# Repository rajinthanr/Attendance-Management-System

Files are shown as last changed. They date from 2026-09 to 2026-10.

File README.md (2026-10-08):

# Card Attendance System

A battery-powered NFC attendance logger. A student taps an ID card and the unit
confirms the tap with an LED and a vibration pulse, and stores the card number
with a timestamp in on-chip flash. Plugged into a PC over USB-C, it appears as a
USB drive, with no driver needed:

- `ATTEND.CSV`: every tap, read-only.
- `STATUS.TXT`: a short summary of the device.
- `SETTINGS.CSV`: edited by the PC to set the clock, start a lecture, and send
  the list of registered card numbers.

A desktop companion app for the PC keeps the student names and works out who
attended which lecture.

The repository holds the hardware (KiCad 10), the firmware (STM32CubeIDE /
Makefile) and the companion app (Python).

## Project status (2026-10-06)

| Area | State |
|---|---|
| Schematic and PCB | Complete and sent to JLCPCB. DRC still reports two missing connections on the antenna loop (AE1). |
| Firmware | Runs on the board in polling mode. Card reading, LEDs, vibration and the USB drive work. Battery measurement reads full scale on the bench (see [Known issues](#known-issues)). 829 host checks pass. |
| Companion app | Desktop app (Tkinter); the earlier browser version is still included. 123 tests pass, including cross-checks against the firmware's own parser. |

## How it works

1. **Card tap.** The ST25R3916 reader polls for ISO14443-A cards (MIFARE
   Classic, NTAG and similar) every 100 ms. The card number is its UID: 4-byte
   UIDs as they are, longer ones by their last four bytes.
2. **Check.** A card read again within 10 s, or already recorded in the current
   lecture, is a duplicate and is not recorded again. Every other card is
   recorded. The device's card list only decides the colour: green for a
   registered card, red for one it doesn't know.
3. **Feedback.**

   | Result | Feedback |
   |---|---|
   | Registered card | green LED and one short buzz |
   | Unregistered card (still recorded) | red LED and one long buzz |
   | Duplicate | two short buzzes |
   | Log full, or reader fault | red blinks with buzzes |
   | Settings applied / refused (eject, button tap or unplug) | green and two buzzes / red and three buzzes |

4. **Logging.** Taps go to a RAM buffer, then to flash within 5 seconds. The log
   holds 6,858 records and survives a power cut. When it is full, new taps are
   refused rather than overwriting old ones.
5. **Lectures.** Starting a lecture (module and lecture name) writes a marker
   into the log, so taps are grouped by lecture even without the app. A card
   counts once per lecture. The app imports every tap before a lecture starts
   and has the device delete its copy (`#CLEARLOG`).
6. **USB.** Plug in USB-C. The reader stops and the drive appears. Ejecting
   the drive or tapping the button applies `SETTINGS.CSV` and starts the reader
   with the cable still in (unplugging does the same). A USB charger that is not
   a computer is recognised after 5 s, and scanning carries on while it charges.
7. **Power.** Press the power button to switch on. A tap shows the battery
   level; holding it for 2 s switches the device off. On battery it also switches
   itself off after 3 minutes without a tap, or when the battery is flat.

`Firmware/docs/USER_GUIDE.md` explains the device for the people who run a
class with it.

## Hardware

| Function | Part | Notes |
|---|---|---|
| MCU | STM32L432**KB** (Cortex-M4F, 128 kB flash, 64 kB RAM, QFN-32) | Runs at 4 MHz from MSI, and 24 MHz during USB sessions, with a 32.768 kHz LSE crystal. The 128 kB of flash holds both the firmware (72 kB) and the attendance log (56 kB). |
| NFC reader | ST25R3916 (13.56 MHz, QFN-32) on SPI1 | Differential antenna drive with an EMC filter, a matching network and a capacitive RX divider; 27.12 MHz crystal. |
| Antenna | PCB loop, `NFC_Loop_40x30_3T` (40 × 30 mm, 3 turns) | In the keep-out area at the top of the board. |
| Backup reader | 8-pin header for a PN532 breakout (Elechouse V3 SPI pinout) | Shares SPI1, with its own chip-select (PA15) and IRQ (PB6). Not used by the firmware yet. |
| Charger | MCP73833 Li-ion linear charger | 10 kΩ NTC and three charge-status LEDs. |
| 3.3 V rail | TPS7A0233 LDO, 200 mA | Runs from the cell. The reader's VDD/VDD_TX come straight from the battery, and its VDD_IO from 3.3 V. |
| USB | USB-C receptacle (GCT USB4110), USB 2.0 full speed | Sink-only with 5.1 kΩ CC resistors; USBLC6-2SC6 ESD protection. |
| Battery | Single-cell Li-ion, 3.7 V, 2-pin JST-XA | Sensed through a 4.7 MΩ / 2.7 MΩ divider with 100 nF, on the ADC (PA7) and the PVD input (PB7). |
| Feedback | Red and green LEDs, vibration motor | The motor is switched by an AO3400A MOSFET with an SS14 flyback diode. |
| Buttons | Power (PA0 / WKUP1), reset, BOOT0 | |
| Debug | 4-pin SWD header: 3V3, SWDIO, SWCLK, GND | |

### MCU pin map

| Pin | Signal | Pin | Signal |
|---|---|---|---|
| PA0 | Power button (WKUP1, polled) | PB0 | ST25R3916 chip-select |
| PA2 / PA3 | Green / red LED | PB1 | ST25R3916 IRQ (polled) |
| PA4 | Vibration motor enable | PB3 / PB4 / PB5 | SPI1 SCK / MISO / MOSI |
| PA7 | Battery sense (ADC1_IN12) | PB6 | PN532 IRQ |
| PA9 | VBUS detect (polled) | PB7 | Battery sense (external PVD input) |
| PA11 / PA12 | USB D- / D+ | PA15 | PN532 chip-select |
| PA13 / PA14 | SWDIO / SWCLK | PC14 / PC15 | 32.768 kHz crystal |

`Firmware/Bsp/Inc/bsp_board.h` is the firmware's reference for the pin map, and
`Firmware/Card Attendance System.ioc` for the CubeMX configuration.

### PCB

- **Board:** 60 × 88.6 mm, 2 layers, 1.6 mm FR-4, all parts on the top side.
- **Floorplan:** the NFC antenna fills the top of the board. Below it are the
  PN532 header, the MCU and the ST25R3916 front end. The power section (USB-C,
  ESD, charger, LDO, battery connector) runs along the bottom edge.
- **Schematic sheets:**
  - `power.kicad_sch`: USB-C, ESD, charger, LDO and battery.
  - `mcu.kicad_sch`: STM32, buttons, LEDs, motor driver, SWD and the PN532
    header.
  - `rfid.kicad_sch`: ST25R3916, crystal, EMC filter, matching network and
    antenna.
- **Rules:** manufacturing rules are in `PCB/Attendance Management System.kicad_dru`.
  The production files sent to JLCPCB are in `PCB/production/`.

## Firmware

The firmware is split along one rule: **the application logic (`App/`) decides,
the drivers (`Bsp/`) act.**

- **`App/`:** the state machine, ISO14443-A protocol, card presence tracking,
  button debouncing, flash log, card list and device config, lecture sessions,
  the `SETTINGS.CSV` parser, the FAT12 volume, CSV and status files, and battery
  maths. It includes no HAL or register headers and compiles on a PC.
- **`Bsp/`:** implements the hardware contract in `App/Inc/platform_if.h`,
  handing up only raw values. It includes the register-level ST25R3916 driver
  (`bsp_nfc.c`).
- **`Tests/`:** builds all of `App/` against a RAM-backed stub platform with a
  simulated card and a simulated PC editing the drive, so the logic is tested
  without hardware.

The firmware currently **polls**: the main loop runs once a millisecond, and only
SysTick and USB use interrupts. `Firmware/docs/ARCHITECTURE.md` describes the
whole design: polling and the plan for interrupts, the flash layout, record, CSV
and settings formats, sessions, the USB volume, and known limitations.

For debugging, `dbg_*` globals defined in `Core/Src/main.c` show the battery
voltage, the last card, button presses, reader status and record counts in
STM32CubeIDE's Live Expressions view.

### Build and test

Run these from `Firmware/`:

```sh
make test    # host tests for the application logic; needs only a native C compiler
make         # cross-compiles build/card-attendance.{elf,hex,bin}
make clean
```

- **Toolchain:** `make` uses the GCC bundled with STM32CubeIDE
  (`/opt/st/stm32cubeide_*`) when one is installed, and otherwise
  `arm-none-eabi-gcc` on `PATH`.
- **Flashing and debugging:** use STM32CubeIDE over the SWD header.
- **Optional:** `Tests/fs_check.sh` checks the USB volume with real FAT tools
  (needs `mtools` and `dosfstools`).

### Data on the device

- **Flash layout:** the firmware takes the first 72 kB of the 128 kB flash; the
  last 56 kB (from `0x08012000`) is reserved for data by the linker script.
  - Its first page: configuration (device ID).
  - The other 27 pages: the attendance log, 6,858 records.
- **Records:** each record is 8 bytes (card number and seconds since
  2000-01-01), exactly one flash double-word. Lecture markers are records with
  reserved IDs from `0xFFFFFF00` up.
- **Setting up a device:** nothing is needed for it to log. The clock starts from
  the firmware's build time until it is set with `#TIME` in `SETTINGS.CSV` (the
  companion app does this when you start a lecture). The card list and device ID
  also come from `SETTINGS.CSV`.

## Companion app

`Companion/` is a desktop app for the PC the device is plugged into. It needs
only Python 3.8 or newer, with no install and no internet, and runs entirely on
that computer. It finds the device, reads its taps into a local SQLite database,
keeps student names, modules and lectures, starts lectures, sends the card list,
and produces attendance reports as CSV or PDF. Start it with `start.bat` on
Windows or `sh start.sh` on macOS and Linux. `Companion/README.md` explains it
in full.

## Repository layout

```
Firmware/            STM32CubeIDE project + standalone Makefile
  App/               application logic (portable, host-tested)
  Bsp/               board support: HAL drivers, ST25R3916 driver, USB MSC glue
  Core/              CubeMX-generated startup code (edit only inside USER CODE blocks)
  Drivers/           ST HAL and CMSIS
  Middlewares/       ST USB Device Library (core + MSC)
  Tests/             host test harness and tools
  docs/              ARCHITECTURE.md (design), USER_GUIDE.md (for users)
  Card Attendance System.ioc   CubeMX pin and peripheral configuration
Companion/           PC app (Python): desktop GUI, database, reports, tests
PCB/                 KiCad 10 project, BOMs (bom/) and JLCPCB production files (production/)
Enclosure/           3D-printable enclosure (enclosure.py and STL files)
CLAUDE.md            detailed engineering notes (design decisions, open issues)
LICENSE              MIT
```

## Tools

- **PCB:** KiCad 10.0.
- **Firmware:** STM32CubeIDE 1.19 (CubeMX 6.15, STM32Cube FW_L4 V1.18.2), or
  `arm-none-eabi-gcc` with `make`.
- **Host tests:** any C11 compiler (`cc`).
- **Companion app:** Python 3.8+ with Tkinter (included with the standard Python
  installers).

## Known issues

- **Battery reading at full scale.** On the bench the battery-sense pin reads
  full scale (`dbg_battery_error` = 4). The schematic, the layout and the BOM
  values are correct, and the firmware path has been checked. The next step is
  to measure the voltage across the 2.7 MΩ resistor on the running board. Until
  this is fixed, low-battery shutdown cannot work.
- **Firmware limitations.** `Firmware/docs/ARCHITECTURE.md` lists them under
  "Known limitations". The most important:
  - Start each lecture from the PC. Without a new lecture, a card already
    recorded in the last 6 hours counts as a duplicate.
- **Antenna tuning.** Tune the matching network and the RX capacitive divider
  against the real coil (ST AN5276). The reader measured a weak RX signal at
  first; the target amplitude reading is about 190.
- **Charge current.** The PROG resistor is 1 kΩ, which sets 1 A. That's more than
  the 500 mA a USB-C sink with plain 5.1 kΩ CC resistors may draw, and more than
  the MSOP-10 charger can dissipate. Use at least 2 kΩ.
- **External footprint library.** Some footprints come from a SnapEDA library at
  an absolute path outside the repository, so a fresh clone can't resolve them
  until the library is added or the paths are updated.
- **PN532 placement.** A PN532 module plugged into its header sits close to the
  ST25R3916 antenna and may detune it.

## License

MIT. See [LICENSE](LICENSE).

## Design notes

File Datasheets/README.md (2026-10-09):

# Datasheets

Reference documents for the parts on the board. Designators follow the current
schematic (`kicad-cli sch export bom`).

| File | Part | Used for |
|---|---|---|
| `STM32L432KB_DS11451_Rev4.pdf` | STM32L432KB (U4), MCU | Stop 2 / Standby wake-up times, run currents, clocks |
| `ST25R3916_DS12484_Rev8.pdf` | ST25R3916 (U5), NFC reader | Wake-up mode, timers, supply currents, SPI |
| `AN4555_STM32L4_hardware_development.pdf` | STM32L4 application note | Power supply, reset, clocks, boot, SWD |
| `FC-135_32.768kHz_crystal_Y1_Q13FC13500049.pdf` | Epson FC-135 (Y1), LSE crystal | CL 6 pF, ±20 ppm, R1 ≤ 70 kΩ, C0 1.2 pF |
| `X32252712MMB4SI_27.12MHz_crystal_Y2.pdf` | YXC 27.12 MHz (Y2), reader crystal | CL 10 pF |
| `MCP73833_charger_DS20002005.pdf` | MCP73833 (U2), Li-ion charger | PROG resistor, status pins |
| `TPS7A02_LDO.pdf` | TPS7A0233 (U3), 3.3 V LDO | Quiescent current, dropout |
| `USBLC6-2SC6_ESD.pdf` | USBLC6-2SC6 (U1), USB ESD | Layout next to J1 |
| `AO3400A_motor_MOSFET.pdf` | AO3400A (Q1), motor switch | Gate threshold at 3.3 V |
| `SS14_flyback_diode.pdf` | SS14 (D4), motor flyback | |

Not included: st.com refuses scripted downloads. Get these from a browser:

- RM0394, STM32L41x-46x reference manual (Stop 2, LPTIM, RCC, PWR):
  https://www.st.com/resource/en/reference_manual/rm0394-stm32l41xxx42xxx43xxx44xxx45xxx46xxx-advanced-armbased-32bit-mcus-stmicroelectronics.pdf
- AN2867, oscillator design guide (LSE drive level):
  https://www.st.com/resource/en/application_note/an2867-guidelines-for-oscillator-design-on-stm8afals-and-stm32-mcusmpus-stmicroelectronics.pdf
- AN5276, antenna matching for ST25 NFC readers:
  https://www.st.com/resource/en/application_note/an5276-antenna-matching-for-st25-nfc-readers-stmicroelectronics.pdf

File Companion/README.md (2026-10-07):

# Attendance Logger: companion app

A small app for the computer that the attendance device is plugged into. The
device records only a card number and a time for each tap; it keeps no list of
registered cards and records every card it reads. This app keeps everything
else: who each card belongs to (so it alone decides which cards are
registered), their department and modules, and the lectures that were held. It reads the taps off the device, matches them to
lectures, and makes attendance reports. You never have to open a CSV by hand,
though you can.

It needs **Python 3.8 or newer**. It opens its own window on your computer;
nothing is served on the network.

The window is built with **Qt** (PySide6), which needs a one-time install, from
this folder:

```sh
python -m venv .venv
.venv/bin/pip install -r requirements.txt          # Windows: .venv\Scripts\pip install -r requirements.txt
```

`start.sh` / `start.bat` use that `.venv` by themselves. Without PySide6 the app
does not start; it says how to install it.

## Start it

| System | How |
|---|---|
| Windows | double-click `start.bat` |
| macOS, Linux | `sh start.sh` |
| anywhere | `python attendance_qt.py` (with the `.venv` Python, or one that has PySide6); `python attendance_app.py` opens the window too |

The **Attendance Logger** window opens: an indigo header with the device status
on the right, then a row of device buttons: **Connect** (indigo, Ctrl+K),
**Read device** (blue, also F5), **Eject** (orange, Ctrl+E), **Set device time**
(teal) and **Clear device records** (red). Under them, banners appear when
something needs doing (with an **Eject now** button where that is the fix). The
two pages, **Lectures** and **Students**, are picked from the bar on the left.
The menus (File, Device, View, Help) hold the same actions with their
shortcuts, and the status bar at the bottom reports what just happened.

Plug the device into the USB-C port: it appears as a drive called
**ATTENDANCE**, and the status at the top turns green and says *Device
connected*. That can take a few seconds. While the drive is gone the status
says *Device not connected*, and **Eject** and the other device buttons are
greyed out. Next to the status the device's **battery** is drawn as a phone
shows it: a battery filled from the left by its charge, green from 50 %, orange
from 20 %, red below, with the percentage beside it. Hover over it for the cell
voltage. While the device is plugged in its cell is charging, so the figure
reads a little high. Older firmware does not report the battery, nor does a
device that has not measured it yet, and then no battery is shown. The window
keeps working while it looks for the device. To stop, close the window
(File, Quit). On Windows a small black window opens behind it; leave that
open, since closing it closes the app.

`python attendance_qt.py --demo` shows the whole app with made-up data and no
device, which is a good way to learn it. Nothing in demo mode touches a real
drive or your database, and the made-up data is deleted when you quit. Other
options: `--device-dir` (use a folder as the device) and `--data-dir` (keep the
database elsewhere).

The window works from the keyboard too. Ctrl+1 and Ctrl+2 pick a page, Ctrl+F
jumps to the search box, F5 reads the device, Ctrl+K connects, Ctrl+E ejects,
and Ctrl+Q quits. In lists, Enter or a
double-click opens the selected row, and clicking a column heading sorts by
it. In a dialog, Enter saves and Escape cancels. Every delete asks first.

## The two pages

The window shows only what a lecturer needs: lectures, and who came to each by
index number and name. (Modules, departments and enrolments are still kept in
the database, but this window does not show them.)

1. **Lectures.** At the top, type the lecture name (the next one is suggested:
   *Circuits Lecture 4* becomes *Circuits Lecture 5*) and press **Start lecture**.
   The app first reads every tap on the device into its database and, once it has
   all of them, tells the device to delete its copy. Then it sets the device
   clock, writes the lecture and ejects the drive. The device checks the file:
   green light and two buzzes means the lecture started, red light and three
   buzzes means it was refused. The cable can stay in. Lectures started on the
   device itself (hold its button 2 seconds) appear here too the next time it is
   plugged in.

   Below, every lecture is listed, the running one marked with a dot. Pick one to
   see who came: **index number, name and the time they tapped**, with the count
   in a green badge. Cards that tapped but belong to nobody are pointed out in an
   orange strip with a **Register…** button. **Rename…**, **End lecture**,
   **Delete**, **Save list (CSV)…** and **Save as PDF…** work on the lecture
   shown. **Clear all records…**, above the list, empties this computer's
   records (see *Your data*).
2. **Students.** Index number, name, card and last tap for each student. **Add
   student**, or **Import list…** (paste rows from Excel or choose a CSV: card
   number, name, index number). **Tap a card…** reads a card on the plugged-in
   device (see below). Cards the device recorded that belong to nobody are
   listed at the top in an orange box, with a **Register…** button.

## The device buttons

* **Eject** ejects the device's drive safely, as the file manager's Eject does.
  The device then applies any changes waiting in `SETTINGS.CSV` and takes
  attendance with the cable still in: the window says *Ejected. The device is
  now taking attendance with the cable in.* When the computer refuses (on
  Linux, most often because a file manager window or the file indexer is
  showing the drive) the window says why, for example *The drive is in use by
  another program: close any window showing it and try again*.
* **Connect** reads the device now when its drive is there. When it is not
  (after an eject the device leaves the computer's USB bus, and the computer
  cannot call it back by itself), a note says how to bring it back: plug the
  cable in, or, if it is already plugged in and taking attendance, **press the
  device's button twice quickly**; its drive comes back in a few seconds. The
  window looks for it every second for 30 seconds, reads it as soon as it
  appears and closes the note. **Cancel** stops waiting.
* **Set device time** sets the device clock to this computer's and ejects the
  drive so the device takes it at once.
* **Clear device records** empties the device's memory. It asks first. Every tap
  and lecture is copied into the database before the device is told to erase
  them (`#CLEARLOG`); if anything could not be read, nothing is erased. Students
  and everything already in the database are kept.
* **Erase device without saving…** (in the Device menu) is for a device whose
  records cannot be read, which *Clear device records* then refuses to erase.
  It tells the device to erase everything **without** copying it here first, so
  taps and lectures not yet read in are lost for good. You have to type `ERASE`
  to confirm. The device keeps its number and clock and numbers its lectures
  from 1 again.

## Registering a card

The device shows green for every new tap: it does not know who is registered;
this app does. While the device is plugged in, its reader stays on, and a tap
is **not** attendance: the device flashes green, buzzes, and tells the app the
card's number (in `LASTCARD.TXT`). So, with the device plugged in:

* **New student:** press **+ Add student** and then **Tap card on device…**, or
  just **Tap a card…** on the Students page with no student picked. Tap the
  card on the device; its number fills in. Add the index number and name and
  save.
* **A new card for a student** (lost card, wrong number): pick the student in
  the list and press **Tap a card…**, or open the student and press **Tap card
  on device…**. The student's taps and modules move to the new card.
* **Whose card is this?** **Tap a card…** with no student picked: a card that
  belongs to someone selects that student.

A card that already belongs to another student is refused, and the app keeps
waiting for another card. Cancel stops the waiting. This needs the updated
firmware; an older device says nothing over USB, and then the way in is to tap
the new card with the device unplugged, plug it in, and **Register** the card
from the *New cards* list (or pick it in the student dialog).

## Saving lists (CSV and PDF)

**Save list (CSV)…** on the Lectures page saves the lecture shown as a CSV with
the columns Index No, Name, Card and Time, unregistered cards last. It opens in
Excel. **Save as PDF…** next to it saves the same list as a PDF to print.

**File, Export** saves the whole database's lists: **All attendance records**
(every tap: date, time, card, index number and name) and the **Student list**,
each as CSV or PDF. The student list CSV has every column (card, name, index
number, department, modules), so it can be imported again.

The PDFs are A4 tables with the title, when they were made, the column
headings at the top of every page and page numbers. The app writes them itself,
so no browser or other program is needed. They use the PDF's built-in
Helvetica, which has the letters of Western European languages only: other
letters (Sinhala and Tamil names, for instance) print as `?`, so use the CSV
for those.

## Your data

The database is one SQLite file, `~/AttendanceLogger/attendance.db` (your home
folder), holding students, modules, enrolments, lectures and every tap. It makes a
dated copy in `~/AttendanceLogger/backups/` once a day and keeps the last 14.
**File, Back up the database…** (Ctrl+B) saves a copy now, wherever you
choose.

**Clear all records on this computer…** (File menu, or the button above the
lecture list) deletes every lecture and every tap from the database, for a
fresh start; the students, their cards, modules and departments are kept.
First it saves a copy of the database in `~/AttendanceLogger/backups/`, named
with the date and time and `before-clear` (the daily copies do not replace it),
and says where. You have to type `CLEAR` to confirm. Records still on the
device come back the next time it is read, lectures and all, unless you tick
**Also clear the device's records**: with the device plugged in, it is then
told to erase its records too, without copying them here first. If you only have a saved `ATTEND.CSV` and not the device,
**Import an ATTEND.CSV…** adds its taps. Reading the device twice never
duplicates a tap. Next to the database, `companion-gui.json` remembers the
folder you last saved to, and `companion.lock` stops a second
window from opening on the same database.

## How it works, and what it will not do

* It looks for the device by checking each drive for `ATTEND.CSV`,
  `SETTINGS.CSV` and a `STATUS.TXT` that begins `ATTENDANCE LOGGER`, so another
  stick that happens to hold files with those names is never touched.
* The device's drive holds `ATTEND.CSV` (every tap), `LECTURES.CSV` (every
  lecture start), `SETTINGS.CSV`, `STATUS.TXT`, `LASTCARD.TXT` (the card last
  tapped while plugged in) and a `LECTURES` folder with one CSV per lecture,
  named like `L001_2026-10-07_14-30.csv` (lecture number, start date and time;
  taps before the first lecture are in `L000_…`). That folder is for reading
  by hand; the app does not need it.
* It reads `ATTEND.CSV`, `LECTURES.CSV`, `STATUS.TXT` and `LASTCARD.TXT`, and
  writes only `SETTINGS.CSV` (the clock, module, lecture, `#NEWSESSION` and
  `#CLEARLOG`). It never writes `ATTEND.CSV`; the device could not accept that
  anyway. The device makes `STATUS.TXT` and `LASTCARD.TXT` afresh at every
  read, so the app reads those two past the computer's file cache (Linux:
  `O_DIRECT`; macOS: `F_NOCACHE`; Windows: `FILE_FLAG_NO_BUFFERING`), falling
  back to an ordinary read where that fails.
* Changes reach the device when the drive is ejected, the device's button is
  tapped or the cable is unplugged, because that is when the device reads the
  file. Starting a lecture ejects the drive for you (Windows: the same lock,
  dismount and eject Explorer uses; macOS: `diskutil eject`; Linux: `udisksctl`
  unmount and power-off).
* `#CLEARLOG` (delete the device's records) is sent only with a lecture start,
  and only when every row of `ATTEND.CSV` and `LECTURES.CSV` was read into the
  database and the row count matched `STATUS.TXT`. Otherwise the device keeps its
  records.
* A lecture is the device's own idea: it stores the module and lecture names in
  its log, so taps are separated by lecture even if you never open this app. The
  app matches taps to its lectures by time, using the start times the device
  lists in `LECTURES.CSV` (the device's clock, whatever this computer says). A
  lecture with no end time lasts until the next one starts, or six hours.
* The lecturer can also start the next lecture on the device itself, with no
  computer: a long press. The device keeps the module and counts the lecture
  name on ("Circuits Lecture 4" becomes "Circuits Lecture 5"). `LECTURES.CSV`
  lists every lecture start in the device's log, so each lecture started this way
  becomes a lecture of its own here, with its own taps, however many there were
  between two reads. A lecture started on the device before any lecture was ever
  named has no module; it is filed under the module `UNASSIGNED`, and editing the
  lecture moves it to the right one. A lecture you delete here is not read back
  from the device. Taps made before the device's first lecture (its `L000` file)
  appear as **Lecture 0**, also under `UNASSIGNED`; move them by editing it, or
  delete it and it stays deleted. Older firmware has no `LECTURES.CSV`; then only the newest
  lecture, from `STATUS.TXT`, is read.
* The device holds only card numbers and times, never names, and no list of
  registered cards: the app sends it none (an older app's `#CARDS` list is
  ignored by the new firmware). Which taps are registered students is worked
  out here, from the database.

## Files

| File | Purpose |
|---|---|
| `attendance_qt.py` | the window (Qt, PySide6): the Lectures and Students pages, the device buttons, the battery icon, menus, dialogs and saving files |
| `app_helpers.py` | what the window says and decides, with no GUI in it: suggested names, banners, device status, the battery level, waiting for a tapped card or for the device to come back, a lecture's CSV and PDF, the one-window lock and the worker thread |
| `requirements.txt` | PySide6, for the Qt window |
| `attendance_app.py` | finds the device, reads and writes its files (`STATUS.TXT` and `LASTCARD.TXT` past the file cache), ejects it, and the actions and exports the window calls; running it opens the window |
| `attendance_db.py` | the SQLite database, the rules for matching taps to lectures, the `SETTINGS.CSV` writer, and the parsers for `ATTEND.CSV`, `LECTURES.CSV`, `STATUS.TXT` and `LASTCARD.TXT` |
| `report_pages.py` | printable report pages, and the PDF writer for tables (standard library only) |

`python attendance_qt.py --demo` is the quickest way to check a change by hand: the demo device has every file a real one has,
with a `LASTCARD.TXT` that never sees a tap.

## Troubleshooting

* *"Device not connected" for a long time.* Check the drive shows up in File
  Explorer or Finder. After an eject it does not: press **Connect** and then
  the device's button twice quickly. If the drive shows and the app still
  waits, the drive is probably not this device (see above).
* *Eject says the drive is in use.* Close any file manager window showing the
  ATTENDANCE drive and press **Eject** again, or press the button on the device
  once.
* *The device refused the settings.* The device keeps its old settings; read
  `STATUS.TXT` on the drive for the reason.
* *A card shows red on the device.* Red now means the device refused the
  settings file or something went wrong, not "unregistered": every new card
  shows green. Read `STATUS.TXT`.
* *Tap a card… keeps waiting.* The device must be plugged in, with the updated
  firmware (the drive then holds `LASTCARD.TXT`), and its light must flash green
  when the card is tapped.
* *Nobody shows as present.* Check the device clock (the app warns when it is
  more than two minutes off) and that the lecture was started before the taps.
* *Only one copy runs.* Starting a second window on the same database just
  says the first is already open. Look for it on the taskbar.
* *"needs PySide6".* Install it as described at the top (the `.venv` lines),
  then start the app with `start.sh` or `start.bat`.

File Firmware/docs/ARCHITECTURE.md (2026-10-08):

# Card Attendance System — firmware architecture

Target: **STM32L432KBU6** (Cortex-M4F, 128 kB flash, 64 kB SRAM, UFQFPN32).
The code and the attendance data share the 128 kB of flash: code in the first
72 kB, the config page and log in the last 56 kB (see "Flash map").

## The two levels

The firmware is split along one rule: **Level 2 decides, Level 1 acts.**

```
                    App/            Level 2 — logic and arithmetic
                     |                no HAL, no vendor headers, no registers
                     |                compiles and runs on a workstation
       platform_if.h |  <-- the contract
                     |
                    Bsp/            Level 1 — HAL drivers
                                      no policy, no arithmetic, no decisions
                                      moves bytes and toggles pins
```

`App/Inc/platform_if.h` is written from Level 2's point of view: it *declares*
what the application needs, and `Bsp/Src/*.c` *implements* it. The dependency
arrow therefore points from the hardware towards the logic, not the other way
round, which is what lets `App/` build against a RAM-backed stub on the host.

### What that buys

`Tests/` compiles every Level 2 module against a RAM-backed stub platform with
a simulated ISO14443-A card, and runs about 900 assertions in under a second:
card activation with 4-, 7- and 10-byte UIDs, presence tracking, the reader's
wake-up mode, button debouncing, exhaustive calendar round trips from 2000 to
2099, the flash log's recovery from a power loss mid-page, the FAT12 image a
host has to accept (the `LECTURES` folder and its long names included), a
simulated PC that copies and edits `SETTINGS.CSV` over that image, a card read
while plugged in reaching `LASTCARD.TXT`, and the whole state machine driven end
to end on simulated time, from card tap to unplug, lecture sessions, duplicate
taps and the sleep deadlines included. None of that needs hardware, a debugger, or a
card.

```
make test          # Level 2, on the host
make               # the full firmware, cross compiled
```

### The rules, concretely

Level 1 never returns a cooked value:

| Level 1 hands up | Level 2 turns it into |
|---|---|
| ADC counts + `VREFINT_CAL` | millivolts, then a battery verdict (`battery.c`) |
| the bytes a card sent (FIFO contents) | a checked UID (`iso14443a.c`), then a card ID (`card_reader.c`) |
| raw button and VBUS levels | debounced presses and attach/detach events (`button.c`, `app_fsm.c`) |
| RTC calendar fields | seconds since epoch, and back (`timeutil.c`) |
| a 512-byte sector request | a synthesised FAT12 / CSV sector (`usb_storage.c`) |

Level 1 never makes a decision. There is no `plat_handle_card()`. The only
Level 2 symbol Level 1 calls is `app_event_post()`, from interrupt context: the
USB storage callback, the button and VBUS edges (EXTI0, EXTI9) and the reader's
wake-up (EXTI1).

The reader's supply mode is an example of where the line falls. Whether the
ST25R3916 runs in its 3.3 V or 5 V mode depends on the battery voltage, so
Level 2 decides (`nfc_supply_3v3_for()`, with hysteresis) and passes a bool to
`plat_nfc_init()` / `plat_nfc_set_supply()`. The no-response timeout and the
SPI prescaler are properties of the chip and the clock tree, so they live in
`bsp_board.h`. That is the test to apply when the boundary is unclear.

## Layout

```
App/Inc, App/Src      Level 2. app_fsm, card_reader, iso14443a, button,
                      log_store, device_cfg, record_buffer, dedup, feedback,
                      battery, csv, fat12, settings_file, session,
                      usb_storage, timeutil, crc, app_events, app_debug
Bsp/Inc, Bsp/Src      Level 1. bsp_clock/gpio/time/nfc/flash/adc/power/usb,
                      bsp_isr, plus usbd_conf and usbd_desc
Core/                 CubeMX output. main.c calls bsp_init() then app_init(),
                      inside USER CODE blocks, so regeneration is safe.
Drivers/              STM32L4 HAL and CMSIS
Middlewares/          ST USB Device Library, core + MSC class
Tests/                host build of Level 2
```

Peripheral interrupt handlers live in `Bsp/Src/bsp_isr.c`, **not** in
`Core/Src/stm32l4xx_it.c`, so that regenerating from the `.ioc` cannot
clobber them.

### The `.ioc`

`Card Attendance System.ioc` carries the full pin map — every signal, label
and pull — so the CubeMX pinout view matches the board and a pin conflict is
caught there rather than on the bench. It declares the button, VBUS and
reader IRQ as EXTI inputs, and TIM1/TIM2 from the 125 kHz design. The BSP
de-initialises those pins and arms them itself (button and VBUS on both edges,
the reader IRQ rising and masked outside wake-up mode), puts LPTIM1 on the LSE
where CubeMX clocks it from PCLK, and never starts TIM1/TIM2. Bring the `.ioc`
in line when it is next regenerated.

The interrupts the BSP owns are listed with code generation switched off, so a
regeneration cannot emit a second copy of a handler that already lives in
`bsp_isr.c`. The USB *middleware* is deliberately not declared — only the USB
peripheral — because the MSC class would generate its own `usbd_conf.c` and
`usbd_desc.c` beside the ones in `Bsp/Src`.

Level 1 stays authoritative: it configures every peripheral at run time and
reads nothing CubeMX generates. Regenerating adds `MX_*_Init()` calls to
`main.c` that are redundant rather than harmful — `bsp_init()` runs after them
and reprograms the same registers, at the cost of about 1 kB of RAM in
duplicate handles.

### After regenerating from the `.ioc`

CubeMX prunes `Drivers/` and `Middlewares/` down to what the `.ioc` declares,
and rewrites `.cproject`. Two things it gets wrong for this project:

1. **`Middlewares/ST/STM32_USB_Device_Library/` is deleted**, and `Middlewares`
   is dropped from the `.cproject` source folders (the include paths survive,
   which makes the failure look like a link error rather than a missing tree).
   Restore the library from `STM32Cube_FW_L4` — Core and Class/MSC, without the
   `*_template.c` files — and re-add the source-folder entry.
2. **`HAL_PCD_MspInit` / `HAL_PCD_MspDeInit` are re-emitted** into
   `stm32l4xx_hal_msp.c` and collide with the ones in `bsp_usb.c`. Delete the
   generated pair; a note in that file's `USER CODE BEGIN 1` block survives
   regeneration and says so. The BSP's version is the one that matters: it uses
   HSI48 + CRS rather than PLLSAI1, enables VDDUSB, sets the NVIC priority, and
   parks PA11/PA12 as analog on unplug.

The clock tree in the `.ioc` is MSI at 4 MHz with the PLL off, matching
`bsp_clock.c`. If it ever drifts back to the 80 MHz PLL default, the generated
`SystemClock_Config()` will start that PLL before `bsp_init()` runs;
`stop_unused_oscillators()` shuts it down again, but the `.ioc` is the place to
fix it.

## Power design

The main loop is a deadline loop: each pass does what is due, works out when
it next has to run, and sleeps until then or until an interrupt. Between cards
the reader watches the antenna on its own, and the MCU spends most of its time
in Stop 2.

| Mode | Used when | Retained | Wakes on |
|---|---|---|---|
| Sleep | USB sessions and switching off (1 ms passes), and any wait under `BSP_STOP2_MIN_MS` (4 ms) | everything | SysTick (1 ms), any interrupt |
| Stop 2 | idle (`ST_IDLE`) with the next deadline 4 ms or more away | SRAM, registers, RTC, LPTIM1 | LPTIM1 at the deadline (at most 15 s), the button (EXTI0), VBUS (EXTI9), the reader's wake-up (EXTI1) |
| Standby | 3 min idle on battery, low battery, a 5 s hold | RTC + backup registers | WKUP1 (button) only, through reset |

Each `app_task()` pass samples the button and VBUS, steps the feedback pattern,
runs the reader, handles queued events, publishes the `dbg_*` globals, and then
calls `plat_sleep_until(next_wake(), deep, queue_still_empty)`. `next_wake()`
in `app_fsm.c` takes the soonest of the deadlines the loop owns: the feedback
pattern's next step, the heartbeat LED's next edge, the button's debounce and
its 2 s and 5 s thresholds (`btn_next_ms()`), the VBUS debounce, the reader's
field guard or next poll (`cr_next_ms()`), the reader retry, the 10 s battery
sample (placed on a heartbeat flash), the 5 s flush and the 3-minute
inactivity timeout, capped at `APP_SLEEP_MAX_MS` (5 s). `deep` is set only in `ST_IDLE`: a USB session needs
the 24 MHz clock and SysTick, so it and the shutdown sequence keep 1 ms passes.
Every timer is still a timestamp compared against `plat_uptime_ms()`
(`HAL_GetTick()`), so nothing blocks, not even the reader's 5 ms field guard.

`plat_sleep_until()` (`bsp_power.c`) re-tests its predicate with interrupts
masked, so an event posted between the queue check and the WFI is never slept
through. For a deep sleep of at least 4 ms, `stop2_for()` sets an LPTIM1
compare at the deadline (rounded up to the next tick) and enters Stop 2.
LPTIM1 counts the LSE divided by 8 (16 bits, 4096 Hz, 0.24 ms a tick, wrapping
every 16 s) without pause and interrupts on both the compare and the wrap,
through EXTI line 32, so a sleep always ends within one wrap and the ticks
slept are never ambiguous; that is why one sleep is capped at
`BSP_STOP2_MAX_MS` (15 s). A wake from the wrap alone, with nothing else
pending, goes straight back to Stop 2 (`woken_by_wrap_only()`). On waking (on MSI at the scanning range), the ticks
slept are converted to milliseconds and added to HAL's `uwTick`, with the
remainder carried to the next sleep, so `plat_uptime_ms()` never notices the
gap. `BSP_ENABLE_STOP2` in `bsp_board.h` set to 0 brings back Sleep-mode-only
operation. With a debugger attached the core never sleeps, so Live Expressions
reads stay stable.

The button and VBUS interrupt on both edges only to wake the loop:
`bsp_input_edge()` posts `APP_EVT_INPUT_EDGE` once per sleep (a bouncing
contact makes dozens of edges), and the next pass samples the levels and
debounces them in Level 2 as before. An edge that arrives after the loop's last
sample but before the sleep is caught by `bsp_input_changed()`, which compares
the pins with the levels the loop last read.

A reader poll switches the field on, waits the ISO14443 guard time, runs
REQA/anticollision/SELECT, and switches the field off again. With
`APP_NFC_USE_WAKEUP` set (the default) the reader is polled only while
something is in the field; see [Card detection](#card-detection-wake-up-mode).
With it cleared, the reader polls every 100 ms for ever, the field is on
about 6 % of the time, and the ST25R3916 stays in Ready mode (oscillator
running) between polls. Either way it is put into power-down before Standby,
since it runs straight off the cell. The reader also stays on during a USB
session, for registering cards (see below).

Consequences worth stating:

- **Feedback never blocks.** Patterns are tables of (output mask, duration)
  stepped against the uptime. The reader pauses while one plays, so the motor
  never runs with the field on, and a card held through the pattern is not
  reported twice.
- **Flash is written in batches, and soon.** Records stage in RAM and go to
  flash at 80 % occupancy, or 5 s after the last scan, whichever is first.
  Appending is a few double-word programs; erases happen once per 254 records.
- **The ADC is powered down between samples** (every 10 s), and re-calibrated
  on each power-up because it has to be.
- **Spare pins are analog**, the lowest-leakage state on an L4.
- **The core runs at 4 MHz** while scanning. USB sessions raise it to 24 MHz
  and drop back on unplug.
- **The idle loop wakes only for the heartbeat:** at the start and end of the
  10 ms flash every 5 s (`APP_SLEEP_MAX_MS` is the same 5 s). The battery
  sample is placed on the flash's wake (`sample_battery()` aligns
  `next_battery` to the heartbeat), so it adds none of its own.
- **The button's pull-up is retained in Standby** via `PWR_PUCRA`. Without
  that, PA0 floats and the unit wakes on noise. Standby is only entered once
  the button is released, so the press that switched the unit off cannot
  switch it straight back on.

### Moving to interrupts

The event queue (`app_events.c`) was the seam: the polled sources posted the
same events an ISR would, so moving a source to an interrupt changed where the
event comes from and not how it is handled. The plan had four steps, and all
are now done:

1. **Done:** button and VBUS on EXTI0 and EXTI9, both edges. The ISR only wakes
   the loop (`APP_EVT_INPUT_EDGE`); the debounce stays in Level 2, which still
   samples the levels and posts `APP_EVT_BUTTON_*` from `poll_button()` and
   `APP_EVT_USB_*` from `poll_vbus()`.
2. **Done, differently from the plan.** The plan was to move the timers to
   LPTIM1/LPTIM2 so `plat_uptime_ms()` no longer depended on SysTick. Instead,
   SysTick still keeps time while the core runs, and LPTIM1 on the LSE only
   bridges each Stop 2 sleep, adding the time slept to the tick count. Every
   Level 2 timer stayed a timestamp against the uptime, and LPTIM2 is unused.
3. **Done:** the ST25R3916 wake-up mode (amplitude measurement on its own
   RC timer) in place of the 100 ms poll, posting `APP_EVT_NFC_WAKE` from
   EXTI1 (PB1).
4. **Done:** Stop 2 between events, through `plat_sleep_until()` and the
   deadlines from `next_wake()`, above.

Still polled: the battery, sampled on the ADC every 10 s (the PVD on PB7 stays
off, `BSP_ENABLE_BATTERY_PVD`). USB sessions do not use Stop 2.

## Data formats

### Attendance record — 8 bytes

```c
struct { uint32_t student_id; uint32_t stamp; };   /* card ID (the field name is historical); epoch 2000-01-01 */
```

Exactly one STM32L4 flash double-word, the smallest programmable unit. Record
size and programming granularity being identical removes read-modify-write
from the log entirely: a power loss can only lose the record being written,
never corrupt one already stored.

### Flash map — 128 kB, code then data

```
0x08000000  pages  0..35   code, 72 kB      (about 60 kB at -Og, 50 kB at -Os)
0x08012000  page  36       config: device ID              (region page 0)
0x08012800  pages 37..63   attendance log, 27 pages x 254 = 6 858 records
                                                        (region pages 1..27)
```

The linker script (`STM32L432KBUX_FLASH.ld`) gives `FLASH` 72 kB and the
rest to an `NVDATA` region, so an image that would overlap the log fails to
link instead of erasing records at run time. `ASSERT`s in the script check
that the two regions tile the 128 kB, and `_Static_assert`s in `bsp_flash.c`
check `BSP_FLASH_BASE` / `BSP_FLASH_SIZE` against `NV_REGION_BYTES`. -O0
(about 97 kB) does not fit, so the CubeIDE Debug configuration builds at -Og.

Firmware for the earlier 256 kB layout kept its data at `0x08020000`, which the
KB does not specify (it may read back on a given chip, untested). This layout
reads none of it: import a unit's log with the app before reflashing, and set
its device ID again afterwards. Old code left in the region by a reflash is no
valid config (no magic) and no valid log page, and `log_init()` erases it.

The config page is one 32-byte `nv_config_t`: magic `"CAS1"`, `format_version` 4,
`device_id`, and words that are written 0 and ignored (`old_card_count` and
`old_card_crc32`, where the card list's size and CRC used to be, and three
reserved). `devcfg_set_device_id()` erases the page, programs it last
double-word first so the magic goes in last, and reads the whole page back. A
blank page, or one written by an earlier layout (format 1 to 3), reads as "no
configuration" with device ID 0; it is never interpreted. A page left by
firmware that still kept a card list is format 4 too, and loads with its device
ID; its card fields and pages 1..8 are simply never read. The pages stay out of
the log so that the log's pages did not move.

Each log page is self describing: a header double-word carrying a monotonic
sequence number, 254 record slots, and a footer written at close carrying the
count and a CRC-16. Logical order comes from the sequence number, not from
physical position. `log_init()` adopts an opened-but-unsealed page and
continues appending, which covers both a power loss mid-write and an ordinary
power-off. Pages are sealed only when they fill: sealing at every power-off
or USB attach, as earlier firmware did, left the rest of the page unusable and
filled the 55-page log after 55 power cycles. There are tests for both.

When the log fills, the device **refuses further records and complains** rather
than overwriting the oldest. Losing attendance history silently is worse than
a device that visibly needs emptying. `APP_LOG_WRAP_WHEN_FULL` inverts this.

### Who owns a card

The device knows nobody's name and keeps no list of registered cards. It
stores a card ID and a time stamp for every tap, and every card that is read and
is not a duplicate is recorded:

| Tap | Feedback |
|---|---|
| new card | green and one short buzz (`FB_ACCEPTED`), recorded |
| duplicate | two short buzzes, not recorded |
| log full | red ×4 (`FB_ERROR`), not recorded |
| any card during a USB session | green and one short buzz (`FB_ACCEPTED`), shown in `LASTCARD.TXT`, not recorded |

A low battery still overrides all of these. Names, student numbers, departments,
module enrolment and which cards are registered at all live in the PC app's
database (`Companion/`), which finds a card's owner by its number. Earlier
firmware kept the registered numbers and showed red for a card not on the list;
that list, the `#CARDS` directive and the red "unknown card" pattern are gone.

### Lecture sessions in the log

A lecture is a module name and a lecture name that apply to every attendance
record after it, up to the next one. It is written into the log itself, as a
marker made of ordinary 8-byte records, so it needs no flash area of its own and
lives exactly as long as the attendance it describes:

```
header  {0xFFFFFFF0 | n, start stamp}      n = text records that follow, 0..15
text    {0xFFFFFFD0,     4 name bytes}     "module NUL lecture NUL", NUL padded
```

Card IDs from 0xFFFFFF00 up are reserved (`NV_ID_RESERVED_MIN`; the PC app also
refuses them), so a marker is recognised from its first word, scanning in either
direction. A longest-name marker is 16 records. Module names are at most 24 bytes
and lecture names 32.

A marker is started from the USB drive (see below). `usbs_end()` returns the
names; once USB has stopped, the state machine appends the marker with
`start_session()`, which flushes the RAM buffer first so the marker always fits
and last so it is in flash at once.

A marker is also started from the button, with no PC: hold past
`APP_BTN_LONG_MS` (2 s, a short buzz) and let go before `APP_BTN_OFF_MS` (5 s).
`new_lecture()` in `app_fsm.c` finds the newest marker with `sess_latest()` and
appends one with the same module and the next name from `sess_next_name()`: a
trailing number counts up (`Circuits Lecture 4` -> `Circuits Lecture 5`, `Week
09` -> `Week 10`), a name without one gets ` 2`, an empty log gives `Lecture 1`
with no module, and the text before the number is cut, at a character boundary,
if the result would pass 32 bytes. It is stamped when the button is released.
With fewer than `SESS_MAX_RECORDS` free log slots it shows the log-full pattern
instead. The PC learns of these lectures from `LECTURES.CSV`.

A marker can be torn by a power cut. A header then promises more text than
follows, or the tail of one has lost its header. `usbs_begin()` claims only the
text records that are really there, and records strays separately, so what comes
after is still attendance.

### Attendance CSV: 32 bytes per row, header included

```
DATE,TIME,CARD_ID<spaces>
2026-09-10,13:27:45,0000123456
```

Fixed width, and 32 divides 512 exactly: sixteen rows per sector, no row ever
straddling a sector boundary. A mass-storage host reads sectors in whatever
order it likes, and this turns "which records are in sector N?" into a multiply
(plus a binary search over the session markers, below): no scan, no
RAM-resident copy of the log. Columns: date 0..9, time 11..18, card 20..29, CRLF
30..31. The card ID is zero padded to ten digits; there is no name, module or
lecture column. No column holds a comma or a quote, so no quoting is needed.

Markers are not rows. At attach the log is read once and every marker is noted
in a table (position, attendance records before it, marker records so far; 6
bytes each, up to 768, in SRAM2). Row `r` is then log record `r` plus the marker
records before it, found by binary search. Every marker's names and start time
reach the PC through `LECTURES.CSV`, and the newest one's through `STATUS.TXT`
too (below), not through the attendance CSV. The `LECTURES` folder splits the
same rows at the markers, one file per lecture.

### Lecture list: 128 bytes per row

```
DATE,TIME,MODULE,LECTURE<spaces>
2026-10-07,14:00:03,EN2090,Circuits Lecture 5<spaces>
```

`LECTURES.CSV` has one row per marker header in the log, in log order, built
from the same marker table (`read_lectures_sector()` in `usb_storage.c`, rows
from `csv_lecture_row()`). The names need more than 32 bytes, so the rows are
128: at most 77 bytes of text, spaces to byte 125, CRLF, four rows to a sector.
A stray text record (the tail of a torn marker) is no lecture and has no row; a
torn header shows the names it still has. The module field is empty for a
lecture started from the button before any was named. Names never hold a comma
or a quote. The PC treats each row as a lecture start by the device clock, and
a tap belongs to the last lecture that started before it.

### Lecture files: the `LECTURES` folder

```
LECTURES\L000_2026-10-06_09-12.csv    taps before the first lecture, if any (8.3 alias L000.CSV)
LECTURES\L001_2026-10-06_14-00.csv    lecture 1 (L001.CSV)
LECTURES\L002_2026-10-07_14-00.csv    lecture 2 (L002.CSV)
```

For people reading the drive by hand; the PC app does not use the folder.
`plan_lecture_files()` in `usb_storage.c` makes one file per marker header, in
log order, plus `L000` when attendance records come before the first header (or
the log has taps and no header at all). A file holds the attendance rows from
its marker up to the next file's, in the same 32-byte rows and header as
`ATTEND.CSV` and rendered by the same code (`attend_sector()`), so a file costs
only a 4-byte table entry (its marker and first cluster; up to 769, in SRAM2).
`read_lfile_sector()` finds the file that owns a cluster by binary search.

The name is the lecture number, then the marker's start date and time; `L000`
is named after its first tap. Lecture `n` is row `n` of `LECTURES.CSV`, which
holds its module and lecture names. Numbers count from 1 in log order, so they
start again after `#CLEARLOG`. Stray text records start no file. Each name takes
two long-name entries (`fat12_lfn_entry()`, with `fat12_sfn_checksum()` of the
alias) and the 8.3 alias, dated with the lecture's start. The directory is
generated on every read (`read_dir_sector()`): `.`, `..`, then three entries a
file. The files are placed last and get whatever clusters are left; if they did
not all fit, the oldest would be left out, but with the shipped log size they
always fit. `STATUS.TXT` gives the count.

### Duplicate taps

Three layers, cheapest first:

1. **The reader** accepts a card only after a clean ISO14443-A activation (BCC
   and CRC_A checked in `iso14443a.c`), and `card_reader.c` reports a card held
   on the reader once, not on every 100 ms poll, so one noisy read is never a
   tap.
2. **`dedup.c`**: a card recorded in the last 10 seconds is a duplicate. This
   is the card held against the reader. The 10 s run from the tap that counted:
   a retry inside them does not restart them (it did once, which held off a
   student who kept tapping). Starting a lecture clears the table
   (`start_session()`), so the last card of one lecture counts at once in the
   next; before that fix, a card tapped just before a long press was a
   "duplicate" in the new lecture. It is a RAM table, so it forgets at Standby.
3. **`sess_card_seen()`** (`session.c`): a card already recorded in the current
   lecture is a duplicate, however long ago. It scans the RAM buffer and then the
   flash log backwards from the newest record and stops at the first session
   header, at a record older than `APP_SESSION_MAX_AGE_S` (6 hours, which is what
   makes it work when no lecture has been started), or after
   `APP_SESSION_SCAN_MAX` records. It reads flash, so a student who comes back
   after the unit has slept is still caught, and it costs a few hundred
   microseconds. A stamp from the future (the clock was set backwards) counts as
   just now.

A duplicate buzzes twice, records nothing, and counts in `scans_duplicate`.
Starting the next lecture resets layer 3 for everyone, because the new header is
where the scan stops.

### USB volume

A FAT12 volume with five files and a folder, sized afresh at every attach to be
exactly as large as its contents:

| File | Access | Source |
|---|---|---|
| `ATTEND.CSV` | read-only | synthesised sector by sector from the flash log |
| `SETTINGS.CSV` | read/write | the current settings rendered as text into a 14 kB RAM window (`SETF_MAX_BYTES` = 28 x 512) |
| `STATUS.TXT` | read-only | one generated sector: see below |
| `LASTCARD.TXT` | read-only | one generated sector: the card last read during this USB session |
| `LECTURES.CSV` | read-only | synthesised from the marker table: one row per lecture start |
| `LECTURES\` | read-only folder | one CSV per lecture, synthesised like `ATTEND.CSV` (above) |

```
LBA 0            boot sector
LBA 1..12        FAT 1 (12 sectors, 4096 entries)
LBA 13..24       FAT 2 (one RAM copy serves both)
LBA 25           root directory (16 entries)
cluster 2        STATUS.TXT                                  (LBA 26)
clusters 3..30   SETTINGS.CSV window (the only free space the host sees)
cluster 31       LASTCARD.TXT
clusters 32..    ATTEND.CSV
then             LECTURES.CSV (1 cluster per 4 lectures, header included; at most 193)
then             the LECTURES directory
then             the lecture files
```

One sector per cluster and 16 root entries, seven of them the device's own (the
volume label, the five files and the folder). A full log appears twice, in
`ATTEND.CSV` and in the lecture files: 6 858 rows at 32 bytes is about 429
clusters each, about 860 with the lecture list and the directory. The volume
may have at most 4084 data clusters (`FAT12_MAX_CLUSTERS`), the most a FAT12
volume can have before a host reads it as FAT16, so the FAT has 4096 entries,
12 sectors a copy. The FAT (6 kB) and root directory are real RAM tables that the
host's writes modify, so the host may allocate, delete and replace files exactly
as its driver pleases. Because the window is the only free space, everything the
host writes lands in RAM. A write to any generated file is refused; a write to
the boot sector, or to the `LECTURES` directory (a host updating an access
date), is accepted and dropped. Windows' `System Volume Information` and macOS's
`.Trashes` fit in the window beside the settings or are refused for lack of
room; neither can touch the log.

`usbs_begin()` takes the loaded `device_cfg_t` (the device ID) so that
`SETTINGS.CSV`, `STATUS.TXT` and the volume serial can show it. The FAT, the
root directory, the marker table (4.5 kB) and the lecture-file table (3 kB)
live in SRAM2. The ARM build uses about 22.3 kB (46 %) of the 48 kB main RAM
block, 14 kB (88 %) of the 16 kB SRAM2, and 60.3 kB (84 %) of the 72 kB code
region.

The record count is latched at attach. A host that saw the file size change
mid-copy would produce a truncated CSV. Nothing is recorded during a USB
session anyway: a card read then goes to `LASTCARD.TXT` (below), not to the log.

`STATUS.TXT` is 512 bytes of text that starts `ATTENDANCE LOGGER` (the PC app
recognises the device by that line). It lists the device ID (once set), the
clock, the battery (`87 % (3950 mV)` from the last sample, or `unknown` before
the first), the number of records in `ATTEND.CSV`, the number of files in the
`LECTURES` folder, the last tap (card and time), the current lecture with the
device-clock time it started (`module / lecture (since ...)`, or `none set`),
and what the host's current `SETTINGS.CSV` would do when the session ends:
unchanged, will be applied (clock set, device ID change, all records deleted,
new lecture), or an error, in which case nothing is applied. The PC uses the
lecture's start time, which is the device's own clock, to decide which taps
belong to which lecture whatever its own clock says.

The battery figure is `batt_percent()` (`battery.c`): a piecewise-linear Li-ion
discharge curve at light load, 0 % at `APP_BATT_CUTOFF_MV` (where the unit
switches itself off) and 100 % at 4.2 V. A cell on charge reads high, and so
does the figure, which on `STATUS.TXT` is the usual case, since the cable is in.
The main loop passes each sample to `usbs_set_battery()`; it is also
`dbg_battery_percent`.

### Editing the settings over USB

`SETTINGS.CSV` as first shown:

```
# Edit these lines, then eject the drive (or press the button). Add #NEWSESSION,1 to start another lecture with the same names.
#TIME,2026-10-06 14:30:00
#MODULE,EN2090
#LECTURE,Circuits Lecture 4
#DEVICE,0000012345
```

The `#DEVICE` line appears once an ID is set. The device shows its current
settings back, so a host that edits only the lines it cares about leaves the
rest as they were. Nothing reaches the device while the drive is
mounted. The session ends in one of four ways, and all of them run `usb_leave()`:

- **Eject.** The host sends SCSI START STOP UNIT with START = 0 (Eject in
  Explorer, Finder or a Linux file manager, `eject`, `udisksctl power-off`).
  ST's MSC class handles that command without telling anyone, so `bsp_usb.c`
  registers a copy of the class whose `DataOut` looks at the command block just
  decoded and latches `plat_usb_ejected()`. `run_usb()` waits
  `APP_USB_EJECT_GRACE_MS` (1 s) so the host finishes its side, then leaves.
- **A short press of the button.**
- **A 5 s hold** (switch off). `begin_shutdown()` applies the file before switching off. A 2-5 s hold ends the session like a tap.
- **The cable coming out** (VBUS drops).

After an eject or a press the unit stays on USB power and scans; it sets
`usb_hold_off`, so the drive comes back only once the cable has been unplugged
and plugged in again, or on a double press (`BTN_DOUBLE`: two taps whose
releases are within `APP_BTN_DOUBLE_MS`, 600 ms), which clears `usb_hold_off`
and runs `usb_attach()`. The PC cannot bring it back itself: after the eject
the device has left the bus. The app's Connect button says to double-press.
The first tap of the pair is still an ordinary `BTN_SHORT` (the battery
display, or the end of a USB session). While VBUS is present the 3-minute idle switch-off is
suspended: Standby would bring the drive back on the next wake instead of the
reader. `usb_leave()` stops the USB peripheral and calls `usbs_end()`, which finds the file by its exact 8.3 name `SETTINGS.CSV` (a file
saved under any other name is ignored), follows its cluster chain through the
window, and parses it with `setf_scan()`, which never touches flash. Only after
the whole file is accepted is anything applied.

Rules for the file (`settings_file.h` has the full list): CRLF, LF or CR line
ends; UTF-8 BOM skipped; only lines whose first non-blank character is `#` mean
anything and every other line is ignored, so an old file that still lists
students does no harm; a `#` line with an unknown keyword is a comment, which
includes `#CARDS` from an older app (its numbers are ordinary lines, so they are
ignored too); a comma or quote inside a name becomes a space and quoted values
work. A file that is empty, larger than the window, or whose cluster chain
is broken is refused.

| Directive | Effect |
|---|---|
| `#TIME,YYYY-MM-DD HH:MM[:SS]` | sets the RTC, but only when it differs from the value the file was shown with, so an untouched file never winds the clock back to the moment of attach |
| `#DEVICE,<id>` | sets the device ID (decimal or `0x` hex), stored in the config page and used as the volume serial |
| `#MODULE,<name>` / `#LECTURE,<name>` | name the lecture (24 and 32 bytes). A new session starts when either differs from what the file was shown with. A name the file omits keeps its current value, and clearing both ends the lecture |
| `#NEWSESSION` | starts a new session even if the names are unchanged (a second lecture with the same names) |
| `#CLEARLOG` | erases the whole log (`log_erase_all()`), the RAM buffer and the 10 s table, before any new session marker is written. The Companion app sends it with a lecture start and with *Clear device records*, in both cases only after it has read every row of `ATTEND.CSV` and `LECTURES.CSV` into its database and the row count matched `STATUS.TXT`; *Erase device without saving…* sends it without that import, behind a typed confirmation. Renaming the lecture by hand never clears anything |

The session marker is written only if the import succeeded. A malformed `#TIME`
or `#DEVICE` value is reported on `STATUS.TXT` and ignored; it does not fail the
import.

When the cable comes out (`usb_leave()` in `app_fsm.c`, after the USB peripheral
has stopped) the unit applies the edit, shows the result and carries on
scanning: green and two pulses for applied (`FB_SAVED`), red and three pulses
for refused (`FB_REJECTED`). If the host changed nothing there is no pattern.
A new device ID is read back from flash before success is claimed; a mismatch
shows red.

**Power loss during the apply.** The only flash write besides the log is the
config page (device ID). It is erased and then programmed with the magic last,
so an interruption leaves "no configuration" (device ID 0) until the host sets
the ID again, never a page that half reads. The marker is appended to the log
like any other record.

### Registering a card while plugged in

The reader stays on during a USB session (`usb_attach()` leaves it
enabled), but a card read then is not attendance. `run_usb()` runs the reader just as
`run_idle()` does, wake-up mode included, and hands a card to `enrol_card()`
instead of `handle_card()`: nothing is logged and no duplicate check applies.
`usbs_set_last_card()` stores the card ID and UID (inside a critical section,
since the USB interrupt reads them) and counts the tap, the unit shows green and
one buzz (`FB_ACCEPTED`), and the scan counts in `scans_enrolled`
(`APP_SCAN_ENROLLED` in `dbg_scan_result`). `LASTCARD.TXT` is rendered afresh
at every read (`lastcard_sector()`):

```
LAST CARD
Taps    : 2
Card ID : 0183769758
UID     : 0A F4 1A 9E
```

`Taps` counts the cards read since this USB session began, from 0 at each
attach, so the PC notices the same card tapped twice; before the first tap the
ID reads `none yet` and the UID `-`. A host caches files, so the PC app reads
this one past its cache (as it does `STATUS.TXT`) and fills in the card when
`Taps` goes up: **Tap a card…** on the Students page, or **Tap card on device…**
in the student dialog. Once the drive is ejected or a button press ends the
session, taps are attendance again. A card can also be registered afterwards:
the app lists cards in the log that belong to nobody and offers to register
each one.

## Card reading (ISO14443-A)

```
field on -> 5 ms guard -> REQA -> ATQA
         -> per cascade level: anticollision (93/95/97 20) -> UID part + BCC
                               SELECT (93/95/97 70 ...)   -> SAK + CRC_A
         -> field off
```

`iso14443a.c` runs the exchange over `plat_nfc_reqa()` and
`plat_nfc_transceive()`, checks the BCC and the SAK's CRC_A itself, and
follows the cascade tag (0x88) through 4-, 7- and 10-byte UIDs. A collision is
reported rather than resolved: the reader expects one card at a time, and the
next poll tries again.

`card_reader.c` turns polls into arrivals. A card held on the reader is seen
by every poll but reported once; it counts as gone after one empty poll
(`APP_NFC_REMOVE_MISSES`; each empty poll costs the 203 mA field for ~6 ms and
100 ms of Ready mode). The reader then re-arms its wake-up mode, so a card
still held but missed once is not logged twice: it is in the reference, and
taking it away only costs one false wake-up. The logged ID is the UID
as a big-endian 32-bit number (`0A F4 1A 9E` is `0x0AF41A9E`, `0183769758` in
the CSV); longer UIDs keep their last four bytes, since the first is the
manufacturer code.

`bsp_nfc.c` drives the ST25R3916 at register level (DS12484 Rev 8). It waits
on the IRQ *pin* rather than polling the status registers over SPI, because
§4.3.3 forbids SPI traffic while a timed direct command runs, and it lets the
chip's no-response timer (1 ms) end each exchange that gets no answer.

### Card detection: wake-up mode

With `APP_NFC_USE_WAKEUP` set, the reader is not polled while the field is
empty. `card_reader.c` alternates between two states:

```
armed ──EXTI1 / APP_EVT_NFC_WAKE──> polling every 100 ms
  ^                                     │
  └── measure the empty field, arm <────┘ after 1 empty poll           
```

- **Arming** (`plat_nfc_wakeup_arm()`): Level 2 measures the antenna
  amplitude with the field empty and passes it as the reference. The BSP
  writes it to the amplitude reference register, sets the wake-up timer to
  `APP_NFC_WAKE_PERIOD_MS` (100 ms) with amplitude measurement on, unmasks
  only I_wam, enters wake-up mode (`en` = 0, `wu` = 1) and unmasks EXTI1. The
  chip then drives the antenna briefly every period on its own RC timer and
  interrupts when a reading differs from the reference by more than the
  trigger window (`delta`, passed in by Level 2). **Every other chip interrupt
  must be masked in wake-up mode** (`irq_masks(true)`): the chip starts its
  oscillator for each measurement, so an unmasked I_osc raised the pin every
  100 ms. On the bench that showed as 99 % false wake-ups with the wake-up
  reading equal to the reference; `dbg_nfc_wake_irq` now records what raised
  each wake-up (0x040000, I_wam, is the only right answer). Leaving wake-up
  mode restores the normal masks before the oscillator is waited on.
- **The reference and the window are learned.** The reference is a Measure
  amplitude reading, but the chip compares its own wake-up measurement, which
  may sit a few counts away. `plat_nfc_wakeup_disarm()` hands up that
  measurement (register 0x36); after a wake-up that found no card,
  `card_reader.c` keeps the difference as `offset` and adds it to every later
  reference. False wake-ups that continue after that are noise: from the
  second in a row the window widens by one count, from
  `APP_NFC_WAKE_DELTA_MIN` (2) up to `APP_NFC_WAKE_DELTA_MAX` (10), and it
  narrows by one after `APP_NFC_WAKE_RELAX_AFTER` (20) wake-ups in a row that
  found a card. Both start afresh at every boot.
- **Waking**: the EXTI1 handler masks its line (one shot: the pin stays high
  until the status registers are read, and SPI belongs to the main loop) and
  posts `APP_EVT_NFC_WAKE`. The FSM calls `cr_wake()`, which leaves wake-up
  mode (`plat_nfc_wakeup_disarm()` reads the status, which drops the pin, and
  waits for `osc_ok`) and polls at once.
- **Polling** then runs exactly as without wake-up mode. A held card keeps the
  reader polling, so it is still reported once, and its removal is still seen.
  After `APP_NFC_REMOVE_MISSES` empty polls the reader arms again.
- **Arming only ever follows an empty poll.** A card measured into the
  reference would never wake the reader. So after any pause (a feedback
  pattern, a supply-mode change) `cr_enable()` polls once first, and arms
  only if that finds nothing. The reader runs the same way during a USB
  session, for registering cards.
- **A fresh reference each time** keeps drift from building up. If the cell
  voltage or the surroundings move the amplitude past the delta, the reader
  wakes, finds nothing, and re-arms against the new level. Such wake-ups are
  counted in `dbg_nfc_false_wakes`.
- **No commands in wake-up mode.** The oscillator is off there, so the regulator
  adjustment and the amplitude measurement need Ready mode. `sample_battery()`
  disables the reader before changing the supply mode, and `run_idle()` skips
  its 10 s amplitude reading while armed (`dbg_nfc_amplitude` then shows the
  reference). The host stubs count any command sent in wake-up mode
  (`host_nfc_misuse`), and the tests require none.

**Tuning on the bench.** Watch `dbg_nfc_armed`, `dbg_nfc_wakeups`,
`dbg_nfc_false_wakes`, `dbg_nfc_wake_irq`, `dbg_nfc_wake_raw`,
`dbg_nfc_wake_offset`, `dbg_nfc_wake_delta` and `dbg_nfc_amplitude`. A
false wake-up or two after power-on is the offset being learned. A
`dbg_nfc_wake_irq` other than 0x040000 is a masking bug. A window stuck at
`APP_NFC_WAKE_DELTA_MAX` with false wake-ups still climbing is noise or an
object near the antenna; cards that are read only very close mean the window
grew too large for this antenna. Setting `APP_NFC_USE_WAKEUP` to 0 brings back
plain 100 ms polling for comparison.

**Reading the globals with a hot-plugged probe.** CubeIDE's debug session sets
C_DEBUGEN, and `plat_sleep_until()` then never sleeps, so Live Expressions are
reliable. A probe attached without halting debug (STM32CubeProgrammer
`mode=HOTPLUG`) reads zeros for most words while the core sleeps, flash
included. Halt for the read: `STM32_Programmer_CLI -c port=SWD mode=HOTPLUG
shared -halt -u <addr> <len> out.bin -run` (a millisecond, which USB does not
notice). No build keeps the debug clocks on in Sleep, Stop 2 or Standby:
`bsp_power_init()` clears `DBGMCU_CR` (DBG_SLEEP, DBG_STOP, DBG_STANDBY) at
every boot, and Stop 2 and Standby entry clear it again. The bits survive every
reset but a power-on one, and with them set the unit drew 0.3 mA switched off.
So a probe cannot attach while the core is in Stop 2: attach while it is awake
(plug its USB into a PC, which keeps the loop in Sleep mode),
or hold BOOT0 (SW2) and press reset (SW1) to enter the bootloader.

**Flashing over SWD toggles FLASH_SR.PEMPTY ("main flash is empty").**
Measured on the bench, with no reset in between: 0 before programming, 1
after, 0 after a second pass. ST's flash loader (STM32CubeProgrammer, and
CubeIDE through the ST-LINK GDB server) clears status flags with a mask that
includes the bit, and on this part writing 1 to it flips it. With it set,
every reset that is not a power-on (the tool's, the reset button, the
debugger's) boots the system bootloader (USB ID 0483:df11, DFU), because the
chip re-reads the flag only at power-on or option-byte reload; `RCC_CSR`
showed only a software reset, no brown-out and no option reload. Hence "it
sometimes does not run after flashing": it depends on the flag's state before
the flash.

The firmware now deals with it whenever it gets to run once:
`bsp_early_init()`, the first call in `main()`, sets `SCB->VTOR` to
`FLASH_BASE` (with the flag set, address 0 maps the bootloader, so a program
a debugger starts after a reset would otherwise take its interrupts from the
bootloader's vectors) and flips a set PEMPTY back (`dbg_pempty_cleared` = 1).
That covers CubeIDE debug sessions, which halt at the reset vector and start
the program themselves. It also stops the HAL taking the flag for a flash
error, which used to fail the first log write after a flash. A flash followed
straight by a plain reset (CubeProgrammer `-rst`, CubeIDE Run) never runs the
program, so if the board then shows up as DFU: power-cycle it (USB and
battery), or flash once more (the flag flips back), or toggle FLASH_SR bit 17
(write 0x00020000 to 0x40022010) and reset.

## Flow-chart coverage

| Flow chart | Where |
|---|---|
| Start / battery OK? / load config | `app_init()` |
| card present → power RF → read | the reader's wake-up (`APP_EVT_NFC_WAKE`), `run_idle()`, `card_reader.c`, `iso14443a.c`, `bsp_nfc.c` |
| valid ID? (BCC, CRC_A, cascade) | `iso14443a_select()` |
| same ID within 10 s? / already signed in? | `dedup.c` (8-entry MRU table) and `sess_card_seen()`, see "Duplicate taps" |
| known card? | not on the device: every new card is logged with `FB_ACCEPTED` (green); the PC app decides who is registered |
| create record, RAM buffer | `handle_card()`, `record_buffer.c` |
| RAM buffer ≥ 80 % | `rb_needs_flush()` → `log_flush()` |
| 3-min inactivity → flush → Standby | `APP_EVT_INACTIVITY` → `begin_shutdown()` |
| USB attach → enumerate → CSV | `usb_attach()`, `usb_storage.c`, `bsp_usb.c` |
| card read during USB (registering) | `run_usb()` → `enrol_card()` → `usbs_set_last_card()`, `LASTCARD.TXT`; not logged |
| low battery → flush → Standby | `sample_battery()` → `APP_EVT_LOW_BATTERY` |

Branches the flow chart does not have:

- **Every card is recorded.** The device has no student list to check, so
  "ID in student list?" always takes the yes branch.
- **A card read on USB is not attendance.** It is shown to the PC for
  registering (`LASTCARD.TXT`) and not logged.
- **A charger is not a host.** VBUS that does not enumerate within 5 s is
  treated as a charger: USB is stopped again and taps are logged from then on.
  Until a host has enumerated, the reader waits (`run_usb()` enables it only
  with `usb_host` set), so a card held through those seconds is logged when the
  session ends rather than shown in a `LASTCARD.TXT` nobody reads.
- **Settings when the USB session ends.** On an eject, a button press or the
  cable coming out, an edited `SETTINGS.CSV` is applied (green, two pulses) or
  refused (red, three pulses), and scanning carries on, with the cable still in
  after an eject or a press.

`handle_card()` checks in this order: the 10 s table (`dedup.c`), then "already
recorded in this lecture" (`sess_card_seen()`), then whether the log has room,
and only then records the card (green).

Duplicate suppression uses an eight-entry MRU table rather than the single
last-seen slot the diagram implies. With one slot, two people tapping in
alternation each clear the other's entry and both get logged twice; there is a
test for that case.

## User interface

| Event | LEDs | Motor |
|---|---|---|
| Power on | green 300 ms | 120 ms |
| Card accepted | green 250 ms | 60 ms |
| Card read during a USB session (registering, not recorded) | green 250 ms | 60 ms |
| Duplicate (within 10 s, or already in this lecture) | green ×2 | ×2 short |
| Log full, or reader failed at power-on | red ×4 | ×4 |
| Settings applied (eject, button or unplug) | green, two pulses | ×2 |
| Settings refused | red, three pulses | ×3 |
| Button held 2 s (still down) | — | 60 ms |
| Released between 2 s and 5 s: new lecture | green | ×3 short |
| Button tap | green ×2 (battery OK) or red ×5 (low); while plugged in it first ends the USB session | — |
| Button held 5 s, or 3 min idle on battery | red 700 ms, then off | 250 ms |
| Idle | 10 ms green flash every 5 s; red if the battery is low or the reader failed | — |
| USB session | green flash every second | — |

## Live debugging

The `dbg_*` globals for the STM32CubeIDE Live Expressions view are defined in
`Core/Src/main.c` (the `USER CODE BEGIN PV` block, so CubeMX regeneration
keeps them) and declared in `App/Inc/app_debug.h`: battery millivolts, raw
counts and percentage (`dbg_battery_percent`), the last card's UID, ATQA, SAK and logged ID, the scan result, button
state and press counts, reader status, counters and interrupt flags, the
wake-up state and counts (`dbg_nfc_armed`, `dbg_nfc_wakeups`,
`dbg_nfc_false_wakes`), how long the last pass asked to sleep
(`dbg_sleep_ms`), record counts, and the RTC. The host build defines its own
copies in `Tests/host_platform.c`.

To set the clock from the debugger, fill in `dbg_set_time` and set
`dbg_set_time_request` to 1. A unit whose RTC was never set starts from the
firmware's build time.

## Companion app

`Companion/` holds the app for the computer the device is plugged into: a
desktop window built with Qt (`attendance_qt.py`, PySide6; it says how to
install PySide6 and exits when it is missing). There is no other window, no
browser version and no server. The window's non-GUI helpers are in
`app_helpers.py`; the actions and device access in `attendance_app.py`. It recognises the device by `ATTEND.CSV`, `SETTINGS.CSV`
and a `STATUS.TXT` that begins `ATTENDANCE LOGGER`, reads `ATTEND.CSV`,
`LECTURES.CSV`, `STATUS.TXT` and `LASTCARD.TXT` (the last two past the OS file
cache, since the device regenerates them at every read), and rewrites only
`SETTINGS.CSV`, in place. It does not use the `LECTURES` folder.

Everything the device does not know lives in a SQLite database
(`attendance_db.py`, `~/AttendanceLogger/attendance.db`, with a dated backup once
a day): students (card, name, student number, department, modules), modules,
lectures and every tap. Reading the device adds its taps (known ones are
skipped); attendance is worked out by matching taps to lecture time windows,
using the lecture start times the device lists in `LECTURES.CSV`. Which taps
are registered students is decided there too: the app sends the device no card
list. It registers cards over USB through `LASTCARD.TXT` (see above), shows the
battery from `STATUS.TXT` while the device is connected, and clears the device
with `#CLEARLOG` only after importing everything, except for *Erase device
without saving…*, which skips the import behind a typed `ERASE`. Reports come
out as CSV or as PDF (`report_pages.py` makes a page that headless Chrome or Edge
prints; with neither, Print opens the page in the browser, then Save as PDF).
`Companion/README.md` describes use.

## Board notes for the hardware

- **PC14/PC15 need a 32.768 kHz crystal.** Not optional: the RTC runs from
  it, and so does LPTIM1, which times and ends every Stop 2 sleep.
- **PB7 (`PVD_IN`) must be tied to the battery divider node**, the same node
  as PA7. The PVD's levels 0–6 watch VDD, which a regulator holds steady until
  it drops out entirely — by which point it is too late to write flash. Level 7
  compares PVD_IN against VREFINT and so actually tracks the cell.
- **Never leave PLS at 7 with the PVD off.** In that state PB7 pulls the
  divider node up to VDD and PA7 reads full scale (4079 counts measured on
  the board, against ~1250 when deselected). `pvd_off()` in `bsp_power.c`
  disables the PVD and sets PLS back to 0, at boot and before Standby.
- **The divider is 4.7 M over 2.7 M with 100 nF across the low leg.** It is
  permanently connected because the PVD watches it, so it is sized for ~0.5 µA;
  the cap keeps the source impedance low enough for the ADC's 640.5-cycle
  sampling window.
- **PA0 is the power button**, active low to ground; it is WKUP1, and while
  running its edges (EXTI0) wake the loop, which samples the level.
- USB is crystal-less: HSI48 trimmed by the CRS against the host's SOF.
- **The MCU is the 128 kB STM32L432KB.** The flash-size word at `0x1FFF75E0`
  reads 128 on the bench unit. A 256 kB KC would run this firmware unchanged,
  using only the bottom 128 kB.

Full pin map: `Bsp/Inc/bsp_board.h`.

## Known limitations

Most were found in review on 2026-10-06; none is covered by a test yet. (A long press
while plugged in used to discard the host's edits; `begin_shutdown()` now applies
them first, and `test_fsm_plugged_in()` covers it.)

- **Back-to-back lectures need a new session.** Without a new marker, a card
  recorded in the last 6 hours (`APP_SESSION_MAX_AGE_S`) is a duplicate, so a
  second lecture within 6 hours that was started neither over USB nor with the
  button (hold 2 s, let go) loses every returning student, with no way to
  recover the taps.
- **A button lecture can be started by accident.** One 2-5 s hold starts it,
  with no confirmation. Nothing is lost: the taps after it are filed under the
  new lecture, which can be deleted or merged in the app. While the device is a
  USB drive the hold only ends the drive session.
- **Card IDs from `0xFFFFFF00` up collide with session markers.** The PC app
  refuses them, but `handle_card()` does not: a 7-byte UID whose last four bytes
  fall in that range is logged as a marker and disappears from the CSV.
- **The marker table holds 768 entries.** A log with more lecture markers than
  that is cut short at the 768th in `ATTEND.CSV`, `LECTURES.CSV` and the
  `LECTURES` folder, silently.
  With the Companion app's `#CLEARLOG` at every lecture start the log holds the
  markers since the last one, a few lectures started from the button at most, so
  this matters only to a device used without the app.
- **Changing the device ID erases the config page first.** A power cut between
  the erase and the final write leaves no device ID (0, and the default volume
  serial) until it is set again.
- **Host editors.** The root directory has 16 entries, seven of them the
  device's own, and a long file name takes extra entries; macOS metadata files
  use root entries too, so a save can fail with "disk full" for want of an
  entry. `SETTINGS.CSV` is a few hundred bytes now, so the 28-cluster window
  leaves an editor plenty of room for a temporary copy. Excel may also rewrite `#TIME` in a locale format the parser does not
  accept. Edit `SETTINGS.CSV` with a plain text editor, or let the Companion app
  write it.
- **Settings apply when the session ends.** `#TIME` is applied at the eject,
  button press or unplug, so the clock is late by however long the drive stayed
  mounted after the file was written (the app ejects straight away).
- **A tap in the first seconds on a charger is late.** Until VBUS has gone
  `APP_USB_ENUM_TIMEOUT_MS` (5 s) without enumerating, the reader waits for a
  host. A card held through that is read and logged when the wait ends; one
  taken away sooner gets no feedback and has to be tapped again.
- **Eject detection relies on START STOP UNIT.** A host that ejects some other
  way (or only suspends the port) leaves the drive session running; the button
  or the cable still end it. A Windows or Linux host that sends START = 0 for
  disk power management would end the session as well.

## Provisioning

Nothing needs provisioning for the device to log: it records every card it
reads, and keeps no card list. Until the RTC is set it starts from the
firmware's build time; set the clock once (the app does it when a lecture is
started, or use `#TIME` in `SETTINGS.CSV`). The device ID is optional and set
with `#DEVICE`. Students are entered in the PC app, which never sends them to
the device. `Tests/fs_check.sh` drives the whole USB path with real FAT tools.

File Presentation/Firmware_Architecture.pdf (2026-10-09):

# Firmware Flow

The MCU sleeps in Stop 2 until something wakes it, handles it, and goes back to sleep.

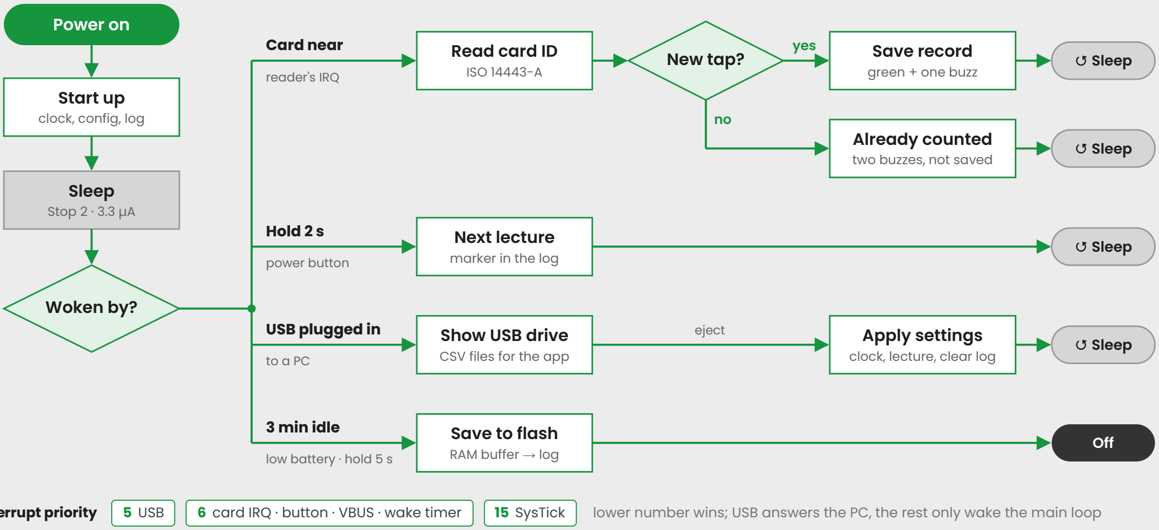
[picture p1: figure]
Power on; Start up clock, config, log; Sleep Stop 2 · 3.3 µA; Woken by?; Card near; reader's IRQ; Read card ID ISO 14443-A; New tap?; yes; Save record; green + one buzz; Already counted two buzzes, not saved; Hold 2 s; power button; Next lecture marker in the log; USB plugged in; Show USB drive CSV files for the app; eject; Apply settings; clock, lecture, clear log; 3 min idle; low battery · hold 5 s; Save to flash RAM buffer → log; ↺ Sleep; Off

Interrupt priority | 5 USB | 6 card IRQ · button · VBUS · wake timer | 15 SysTick | lower number wins; USB answers the PC, the rest only wake the main loop

New tap = not already in this lecture and not the same card within 10 s. Records wait in RAM and go to flash 5 s after the last tap. The reader looks for cards by itself while the MCU sleeps.

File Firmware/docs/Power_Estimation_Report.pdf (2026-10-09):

BENCH MEASUREMENT AND MODEL · FIRMWARE AND HARDWARE REV 0. 1

# RFID Attendance Logger Power, Capacity and Cost

Current draw for each operating mode and event, | when the MCU and the reader
are awake, | the reasoning behind each clock frequency, | the expected number of
card reads and the battery life on a 1000 mAh, | 3.7 V Li- | ion cell, | how the

## STM32L432KB's 128 kB of flash is shared between the program and the

attendance log, | and what a finished unit costs to make at 1 to 10 000 units, | in
US dollars and Sri Lankan rupees.

Hardware
STM32L432KB (128 kB) +

ST25R3916

Battery
1000 mAh, 3.7 V nominal
(3.7 Wh)

Date
08 October

2026

| | | Status Currents measured 8 October
| | | 2026

BATTERY LIFE
17 months
4 lectures/day, | 100
students, | incl. | self-
discharge (12
pessimistic)

IDLE SCANNING
108µA

Reader wake- up mode is
91 % of it

SWITCHED OFF
1.8µA

Standby, measured; 57
years on the device alone

PER CARD TAP
2.8µAh

10.3 mC; 6,858 records fit in flash

# 1 Summary

The logger spends nearly all of its life in one of two low- | power states. | Switched off, | it sits in Standby and
draws 1.8 µA (measured). | Switched on and waiting for cards, | the MCU sleeps in Stop 2 and wakes only for a
10 ms heartbeat flash every 5 s, | while the ST25R3916 checks the antenna itself every 100 ms. | That idle state
draws about 108 µA, | and 91 % of it is the reader's wake- | up mode. | The large currents (202 mA for the RF
field, | 82 mA for the motor) flow only for milliseconds per tap, | so a whole 100- | student lecture costs about 0.36
mAh (1.34 mWh).
At four lectures a day, | the device uses about 33 mAh a month. | With the cell's self- | discharge (about 20 mAh a
month) that gives roughly 17 months per charge, | or 27 months from the device's draw alone.
The program and the log share the STM32L432KB's 128 kB flash: 72 kB for the program (60.6 kB at - | Og) and
56 kB for the log, | 6,858 records or about 64 lectures of 100 students. | The log fills long before the battery
empties (in about 16 teaching days at four lectures a day), | so the PC sync, | which clears the log, | sets the
routine, | not the charger.

A finished unit costs about US$25 (LKR 8,382) to make at 1 000 units and US$18 (LKR 6,042) at 10 000, landed in Sri Lanka and tested (section 11).

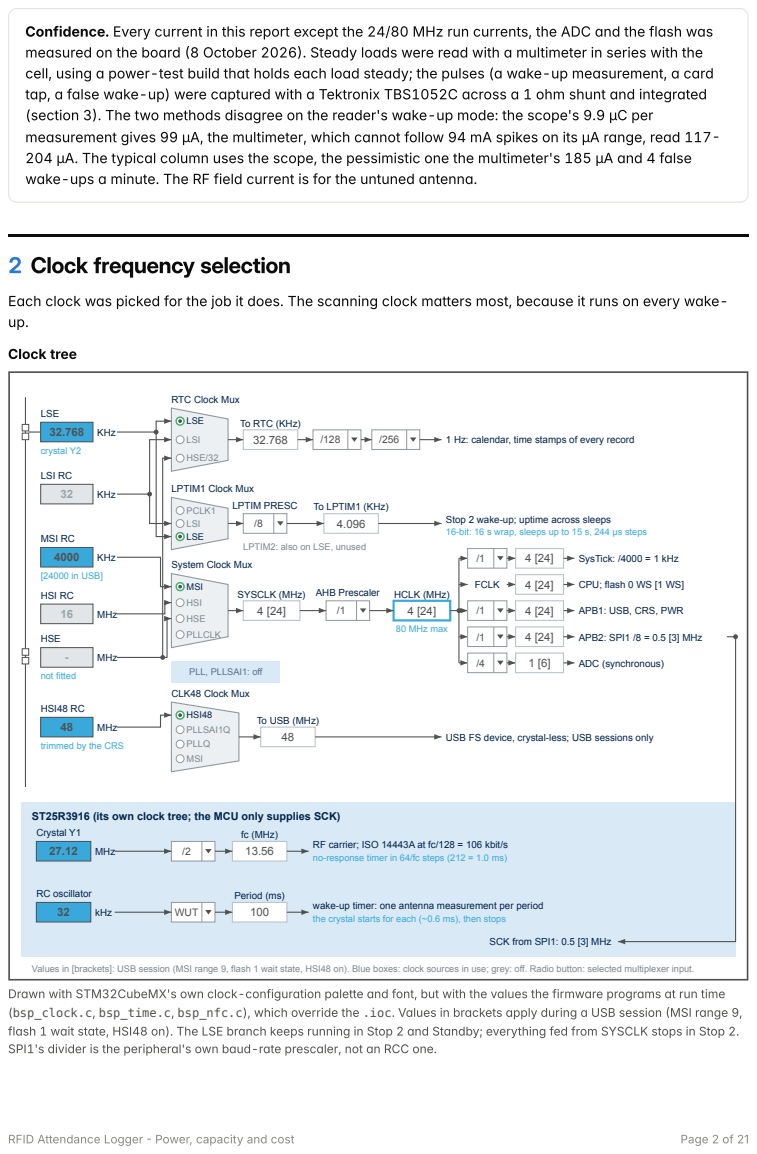
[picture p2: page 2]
RFID Attendance Logger -; Power, capacity and cost; Page 2 of 21; Confidence.; Every current in this report except the 24/80 MHz run currents,; the ADC and the flash was; measured on the board (8 October 2026).; Steady loads were read with a multimeter in series with the; cell,; using a power-; test build that holds each load steady; the pulses (a wake-; up measurement,; a card; tap,; a false wake-; up) were captured with a Tektronix TBS1052C across a 1 ohm shunt and integrated; (section 3).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

2 Clock frequency selection

RTC Clock Mux

To RTC (KHz)

16-bit: 16 s wrap, sleeps up to 15 s, 244 µs steps

LPTIM2: also on LSE, unused

System Clock Mux

To USB (MHz)

trimmed by the CRS

ST25R3916 (its own clock tree; the MCU only supplies SCK)
Crystal Y1

RF carrier; ISO 14443A at fc/128 = 106 kbit/s
no-response timer in 64/fc steps (212 = 1.0 ms)

wake-up timer: one antenna measurement per period
the crystal starts for each (~0.6 ms), then stops

SCK from SPI1: 0.5 [3] MHz

Values in [brackets]: USB session (MSI range 9, flash 1 wait state, HSI48 on). Blue boxes: clock sources in use; grey: off. Radio button: selected multiplexer input.

RFID Attendance Logger - | Power, capacity and cost | Page 3 of 21
Clock domain | Selection | Setting | Why

Scanning
(SYSCLK/HCLK)

MSI range 6, 4
MHz

Range 1, 0 wait
states
Reset clock and the Stop 2 wake- | up clock
(STOPWUCK = | MSI): no PLL to relock on each
wake- | up. | The work is time- | bound (5 ms field
guard, | 106 kbit/s frames, | ADC sampling), | so a
faster clock only raises the current for the same window.
USB session | MSI range 9, | 24
MHz

Range 1, 1 wait
state
USB FS needs HCLK above 14. | 2 MHz
(RM0394). | 24 MHz is the first MSI step with
margin for rendering CSV sectors on demand. Powered from VBUS, so it costs the battery nothing.
USB kernel clock | HSI48 trimmed by
CRS

Locks to the host's
1 kHz SOF
Meets the USB ±0. | 25 % tolerance with no
crystal and no PLL. | Stopped outside USB
sessions.
RTC and Stop 2 timer | LSE 32.768 kHz | RTC; LPTIM1 at
LSE / 8 (16- | bit)
Runs through Stop 2 for well under 1 µA. | LPTIM1
counts 4096 Hz, | so its 16- | bit count wraps every
16 s and one Stop 2 sleep can last up to 15 s (the loop asks for at most 5 s); resolution 244 µs. A wake from the wrap alone goes straight back to Stop 2.
Reader SPI | 4 MHz / 8 = | 500
| kHz

Mode 1,

ST25R3916 max

10 MHz

Well inside the chip's limit. | Register traffic during
a read adds an estimated 2- | 3 ms of field- | on
time; a /2 prescaler (2 MHz) would cut it to under 1 ms.
ADC | HCLK / 4 = | 1 MHz | 640.5- | cycle
| | | sample

0.64 ms per channel gives the 1.7 MΩ divider time to settle; the ADC is powered only for each sample.

Reader crystal | 27.12 MHz | 2 × 13.56 MHz
| | | carrier
Fixed by ISO 14443 (fc = | 13.56 MHz). | Runs only
in Ready mode or for each wake- | up
measurement.
Reader wake- | up timer | ST25R3916 32
| kHz RC
100 ms period | Keeps the 27. | 12 MHz crystal off between
measurements, | so the reader idles at about 3 µA
between them. | 100 ms is the slowest check a
person will not notice; each check costs about 10 µC, so the period sets most of the idle current.
SysTick | HCLK / 4000 = | 1
| kHz
Stopped in Stop 2 | HAL's millisecond tick, | the firmware's only time
base while awake. | LPTIM1 adds the time slept in
Stop 2, | so timers never see a gap.
Calendar | LSE / 128 / 256 =
| 1 Hz
RTC, | backup
domain
ST's lowest- | power split of the prescalers. | Keeps
the date and time through Standby and resets for the attendance time stamps.
Clocks left off | PLL, | PLLSAI1,
HSI16, | LSI
- | No load needs more than 24 MHz, | so there is no
PLL to start or lock (15- | 40 µs, | plus current).
There is no HSE crystal. | LSI would only be
needed by a watchdog, | which is not enabled.
MSI is not locked to the LSE (MSI PLL mode off): nothing timed depends on it.

RFID Attendance Logger - | Power, capacity and cost | Page 4 of 21

### Why 4 MHz and not faster

The MCU's awake time is set by the radio and the protocol rather than by computation: a read waits out a 5 ms
field guard, | exchanges ISO 14443 frames at 106 kbit/s, | and busy- | waits on the reader's IRQ line. | For a fixed
window t, | the charge is Q = Irun
(f) × t, | so the lowest clock that meets the deadlines wins.

MCU charge during one 15 ms read window (4 MHz measured, 24/80 MHz datasheet):
4 MHz | = 1.01 mA × 15 ms = 15.2 µC
24 MHz | = 2.8 mA × 15 ms | = 42.0 µC
80 MHz | = 9.0 mA × 15 ms | = 135.0 µC + PLL lock per wake-up
RF field = 202 mA × 12 ms | = 2474 µC

Charge for one card read: MCU clock options against the RF field

0 | 1,000 | 2,000 | µC
MCU at 4 MHz (selected) | 15.2 µC
MCU at 24 MHz | 42.0 µC
MCU at 80 MHz (PLL) | 135.0 µC
RF field for the same poll | 2,473.8 µC
At 4 MHz the MCU is 0.6 % of a read's charge. | At 80 MHz it would be about 5 %, | for no gain in speed.
For purely computational work (one pass of the main loop is roughly 2000 cycles), | current per MHz is close to
constant, | so finishing faster and sleeping longer gains little: 0.5 ms at 1.0 mA (0.51 µC) at 4 MHz against 25
µs at 9 mA (0. | 23 µC) at 80 MHz. | That small gain is lost to the PLL's start- | up time and to the 4 flash wait states
80 MHz needs.

### Why not slower

SPI with the field on. | The SPI clock is SYSCLK / 8. | At 2 MHz the reader's register traffic would take twice as
long while the 202 mA field is on, | costing more than the MCU saves.
ADC sampling. | The ADC clock is HCLK / 4. | A slower clock stretches the 640.5- | cycle sample and keeps the
ADC powered longer.
Low- | power run (at most 2 MHz) would barely help. | The MCU is awake about 0.02 % of the time in idle, | so
its run current adds only ~0. | 2 µA to the 108 µA idle figure.

### Voltage scaling

The firmware keeps Range 1 at all clocks. | Range 2 would cut run current by about 10 %, | but that saves well
under 0. | 1 µA in idle, | while USB needs Range 1 anyway. | Staying in Range 1 avoids switching the regulator on
every USB attach. | Stop 2 and Standby use the low- | power regulator either way.

RFID Attendance Logger - | Power, capacity and cost | Page 5 of 21

# 3 Measurements and assumptions

Battery- | side currents, | measured on 8 October 2026 with a multimeter in series with the cell. | The power- | test
build (make power-test, | Bsp/Src/bsp_power_test.c) runs no application: each press of the button holds the next
load steady, | so the meter reads it instead of a millisecond pulse. | The 3.3 V rail comes from a linear LDO, | so the
battery supplies the same current the MCU and LEDs draw; the reader's VDD/VDD_TX and the motor sit straight on BAT+.

Measured MEASURED 8 OCTOBER 2026

Mode | State held | Current | Note
1 | MCU Stop 2 + RTC + LPTIM1, | reader
power- | down
3.3 µA | Includes the divider, | LDO and charger leakage
2 | As 1, | reader in wake- | up mode (100
| ms)
103 µA | Meter read 117- | 204 µA as it averaged the 100 ms
measurements; 188 averaged
3 | As 1, | reader Ready (oscillator on,
field off)
5.66 mA | Reader between polls and during patterns
4 | As 1, | RF field on | 202 mA | Antenna not yet tuned
5 | MCU Run, | MSI 4 MHz, | reader power-
| down | | 1.01 mA | DS11451 gives ~0.5 mA; peripheral clocks are on
6 | MCU Sleep, | MSI 4 MHz, | SysTick
| every 1 ms
0.72 mA | The loop's mode in USB sessions
7 | Green LED on (470 Ω from 3.3 V) | 2.77 mA
8 | Red LED on | 3.0 mA
9 | Vibration motor on (coin ERM on BAT+) | 56.5 mA
10 | Standby (switched off) | 1.8 µA | 4.8 µA before the reader's SPI pins were pulled down in
Standby

### Scope captures MEASURED 8 OCTOBER 2026

Tektronix TBS1052C, | probe and menu at 10X, | across a 1 ohm shunt in the battery's negative lead, | so 1 mV is
1 mA; USB and the debugger unplugged. | Each capture's DC offset (up to 2 mA) is taken from a quiet stretch
and subtracted, | and the charge is the integral of the current. | The files are in Waveforms/;
Firmware/docs/waveforms.py does the arithmetic.
Event | Capture | Charge / current | Detail
One wake- | up
measurement
TEK00005 | 9.9 µC | Oscillator start 13 mA × 0.4 ms, | plateau 3.7 mA, | field spike 94
mA peak for 41 µs; two more in TEK00007: 5.9 and 8.8 µC

Wake- up mode
average
99 µA | 9.9 µC × 10 per second, | plus the reader's timer (a few µA,
below the scope's resolution)

Wake- up IRQ to field
on
TEK00006 | 25.9 µC | The measurement that saw the card, | MCU wake, | oscillator start
Read: field on | TEK00006 | 2.47 mC | 12. | 2 ms at 202 mA (guard, | REQA, | anticollision, | SELECT)

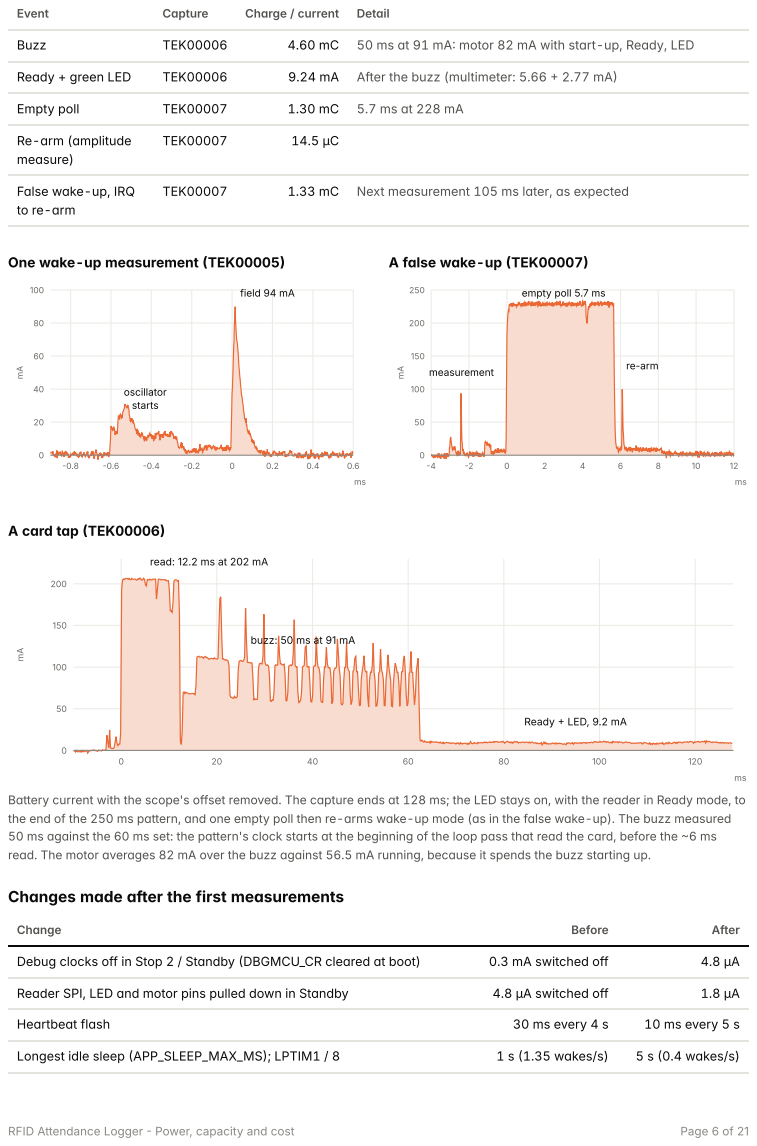
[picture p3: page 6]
RFID Attendance Logger -; Power, capacity and cost; Page 6 of 21; Event; Capture; Charge / current; Detail; Buzz; TEK00006; 50 ms at 91 mA: motor 82 mA with start-; Ready,; LED; Ready + green LED; After the buzz (multimeter: 5.66 + 2.77 mA); Empty poll; TEK00007; arm (amplitude; measure); False wake-; IRQ; arm; Next measurement 105 ms later,; as expected; One wake-; up measurement (TEK00005); oscillator starts; field 94 mA; A false wake-; up (TEK00007); measurement; re-arm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

empty poll 5.7 ms

read: 12.2 ms at 202 mA

buzz: 50 ms at 91 mA

Ready + LED, 9.2 mA

Changes made after the first measurements

RFID Attendance Logger - | Power, capacity and cost | Page 7 of 21
Change | Before | After
Battery sample placed on the heartbeat's wake | own wake every 10 s | none extra
Empty polls before re- | arming (APP_NFC_REMOVE_MISSES) | 3 | 1
Accepted- | card buzz (APP_FB_ACCEPT_VIB_MS) | 90 ms | 60 ms

### Still estimated

Quantity | Typical | Pessimistic | Source / basis
STM32L432 Run, | 24 MHz / 80
MHz
2.8 / 9.0 mA | - | DS11451 typ., | Range 1 (not used while scanning)
ADC on, | extra over Run | 0. | 2 mA | - | DS11451
Flash program / erase | 7.0 mA | - | DS11451; 22 ms per page erase
Button pull- | ups (R8 10k + internal) | 0.41 mA | - | Only while pressed
Field time per read / per empty poll | 12. | 2 / 5.7 ms | 14. | 1 / 6.6 ms | Scope (one capture each); pessimistic +15 %
Reader wake- | up mode average | 99 µA | 185 µA | Scope (pulse charge × 10/s) against the
multimeter
False wake- | ups while scanning | 1 / min | 4 / min | Not measured yet; read dbg_nfc_false_wakes
Cell self- | discharge | 2 %/month | 3 %/month | Typical Li- | ion at room temperature
Usable capacity of 1000 mAh | 900 mAh | 850 mAh | Cut- | off at 3.3 V, | ageing margin

### Measured on the board MEASURED 07 OCTOBER 2026

Quantity | Value | Note
Flash size (0x1FFF75E0) | 128 kB | Fitted part is the STM32L432KB
Cell voltage (dbg_battery_mv) | 4,152 mV | Three samples 10 s apart: 4152, | 4149, | 4154 mV
State of charge (dbg_battery_percent) | 96 % | From the firmware's Li- | ion voltage curve
ADC counts at PA7 | 1,876 | PA7 = | 3308 mV × 1876 / 4095 = | 1515 mV
VDDA from VREFINT | 3,308 mV | VREFINT_CAL 1652 / 1497 counts × 3000 mV
Divider check | 4,153 mV | 1515 mV × (4.7 M + 2.7 M) / 2.7 M

# 4 Operating modes

Mode | Typical | Pessimistic | What is running
Off (Standby) | 1.8 µA | 1.8 µA | MCU Standby + RTC, | reader power- | down, | divider (measured)
Idle, | scanning | 108 µA | 194 µA | Stop 2, | reader wake- | up mode, | heartbeat
Polling mode (wake- | up off) | 18.9 mA | - | Reader Ready + field every 100 ms; for comparison
Card read (RF field on) | 202 mA | - | 12. | 2 ms per read, | 228 mA in an empty poll (scope)
Vibration motor on | 82 mA | - | Average over a 50 ms buzz (scope); 56.5 mA running steadily

RFID Attendance Logger - | Power, capacity and cost | Page 8 of 21
Mode | Typical | Pessimistic | What is running
USB session | 4- | 6 mA | - | From VBUS, | not the battery (plus charge current)
Idle scanning current, | 108 µA in total
0 | 25 | 50 | 75 | 100 | µA
ST25R3916 wake-up mode (100 ms) | 99.27 µA
Heartbeat LED (10 ms every 5 s) | 5.54 µA
MCU Stop 2, reader off, board static | 3.30 µA
MCU loop wake-ups (0.4/s) | 0.20 µA
Battery sample (every 10 s) | 0.18 µA
The reader's own antenna measurements are 91 % of idle current. | The MCU, | including its wake- | ups, | is under 4 %.
Wake-up mode = 9.93 µC per measurement × 10 /s (scope) | = 99.3 µA
Heartbeat | = 2.77 mA × 10 ms / 5000 ms | = 5.5 µA
Wake-ups | = 0.4 /s × 0.5 ms × 1.01 mA | = 0.20 µA
Sampling | = 1.5 ms × (1.01 + 0.2) mA / 10 s | = 0.18 µA
Off | = measured, mode 10 | = 1.80 µA
Polling mode = 5.66 mA Ready + 228 mA × 5.7 ms / 100 ms + MCU = 18.9 mA
The reader's wake- | up mode is still far cheaper than polling: switching it off would take idle current from 108
µA to about 19 mA, | and battery life left switched on from 346 days to 2.0 days. | Each measurement costs 9.9
µC (scope), | ten times the ~1 µC first assumed: it starts the 27. | 12 MHz oscillator (5.0 µC) and drives the
untuned antenna for about 41 µs at up to 94 mA (4.0 µC). | A longer period (section 10) or a tuned antenna is
the largest remaining saving.

# 5 When the MCU and the reader are awake

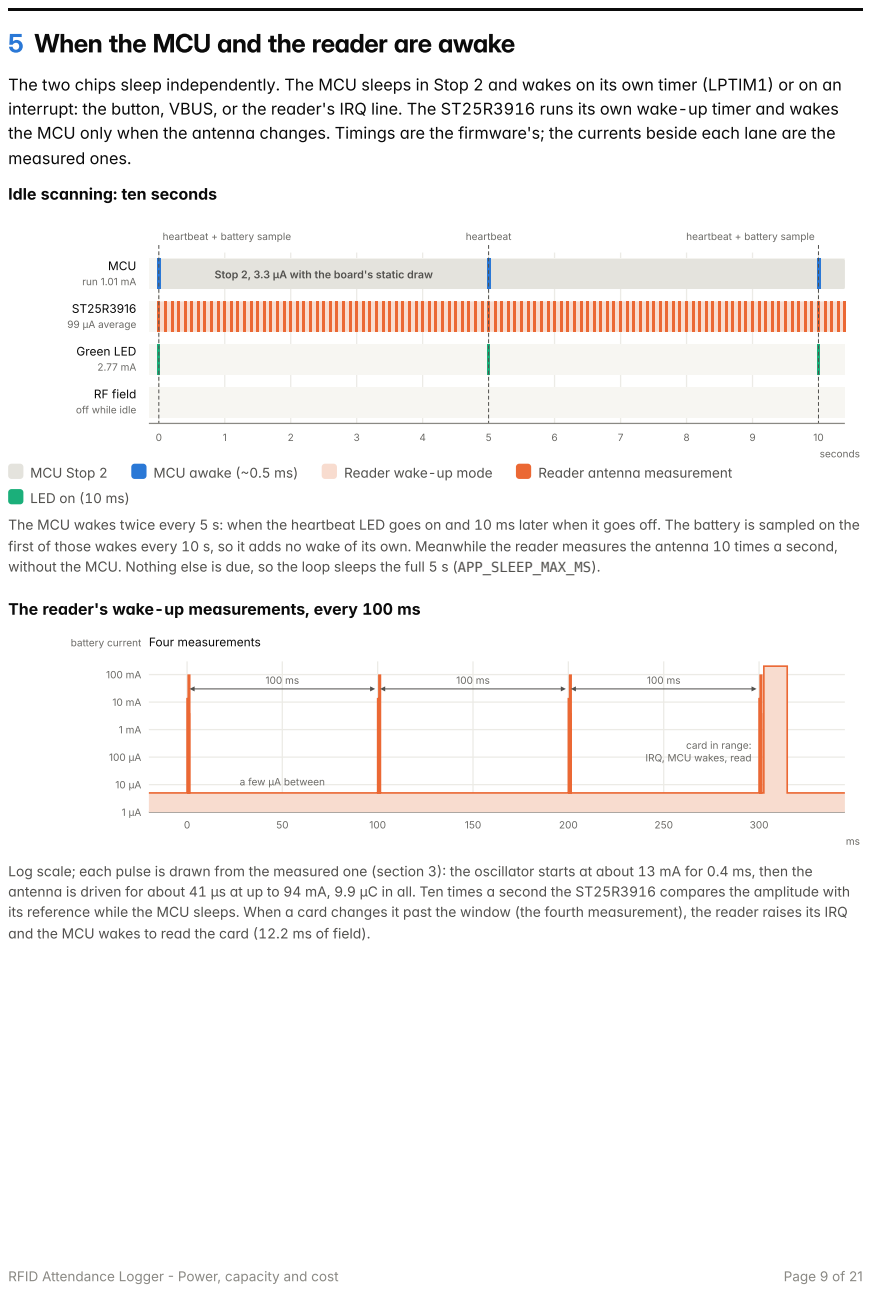
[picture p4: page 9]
RFID Attendance Logger -; Power, capacity and cost; Page 9 of 21; The two chips sleep independently.; The MCU sleeps in Stop 2 and wakes on its own timer (LPTIM1) or on an; interrupt: the button,; VBUS,; or the reader's IRQ line.; The ST25R3916 runs its own wake-; up timer and wakes; the MCU only when the antenna changes.; Timings are the firmware's; the currents beside each lane are the; measured ones.; seconds; MCU; run 1.01 mA; 99 µA average; Green LED; heartbeat + battery sample; heartbeat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

Idle scanning: ten seconds

Stop 2, 3.3 µA with the board's static draw

RF field
off while idle

LED on (10 ms)

IRQ, MCU wakes, read | card in range:

a few µA | between

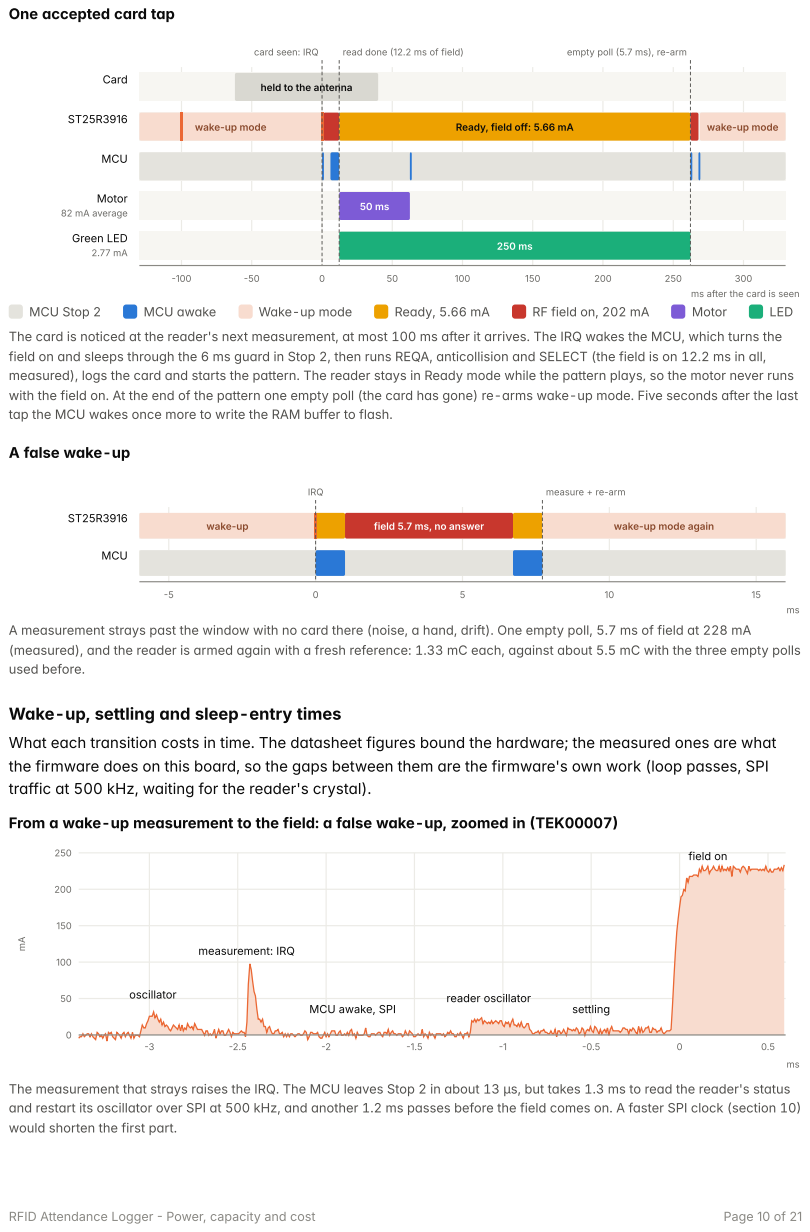
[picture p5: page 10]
RFID Attendance Logger -; Power, capacity and cost; Page 10 of 21; Card; wake-up mode; Ready, field off: 5.66 mA; MCU; Motor; 82 mA average; Green LED; card seen: IRQ; read done (12.2 ms of field); empty poll (5.7 ms), re-arm; MCU Stop 2; MCU awake; Wake-; up mode; Ready,; RF field on,; LED; The card is noticed at the reader's next measurement,; at most 100 ms after it arrives.; The IRQ wakes the MCU,; which turns the; field on and sleeps through the 6 ms guard in Stop 2,; then runs REQA,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

One accepted card tap

held to the antenna

ms after the card is seen

tap the MCU wakes once more to write the RAM buffer to flash.

MCU awake, SPI

would shorten the first part.

RFID Attendance Logger - | Power, capacity and cost | Page 11 of 21
Measured on the board | Time | Source / what happens
Wake- | up measurement: oscillator start
to field | 605 µs | TEK00005
Wake- | up measurement: whole event | 731 µs | TEK00005

Measurement to the reader's oscillator
restarting
1. | 28 / 1. | 27 ms | MCU leaves Stop 2 (~13 µs), | runs the loop, | reads the reader
over SPI at 500 kHz
Oscillator restart to field on | 1. | 15 / 1. | 22 ms | Crystal settles (I_osc), | next loop pass
Card seen to field on | 2.43 / 2.49 ms | False wake- | up / card tap

Field on for a read (guard,
REQA..SELECT)
12. | 25 ms | TEK00006
Field on for an empty poll | 5.69 ms | TEK00007; see the note below
Field off to re- | arm measurement | 392 µs | TEK00007
Re- | arm to the next wake- | up
measurement
98.8 ms | TEK00007: the 100 ms wake- | up timer
Buzz (motor on) | 50. | 1 ms | TEK00006; 60 ms set
STM32L432 (DS11451 Rev 4) | Typ | Max | Where it applies
Sleep to Run | 6 CPU cycles | 6 cycles | 1.5 µs at 4 MHz; USB sessions and short waits
Stop 2 to Run, | MSI 4 MHz,
from flash
12.06 µs | 13. | 16 µs | Every idle wake- | up (datasheet lists 4 MHz at Range 2)
Stop 2 to Run, | MSI 48 MHz,
Range 1
8.02 µs | 9. | 24 µs | For comparison: a faster wake clock saves 4 µs
Standby to Run, | MSI 4 MHz | 19. | 14 µs | 25.8 µs | Power button; then reset and start- | up code
Shutdown to Run | 261.5 µs | 315.7 µs | Not used: Shutdown would lose the RTC
Reset after power- | on (BOR) | 250 µs | 400 µs | Battery connected

Regulator Range 2 to Range

1

20 µs | 40 µs | Not used: the firmware stays in Range 1
MSI start- | up, | ranges 4- | 7 | 3 µs | 6 µs | MSI restarts on every Stop 2 exit
MSI PLL- | mode settling to 1
% | | | | - | 2.5 ms | Not used (MSI PLL mode off)
HSI48 start- | up | 2.5 µs | 6 µs | USB attach; the CRS then trims it on each 1 ms SOF
PLL lock | 15 µs | 40 µs | Not used (PLL off)
LSE start- | up | 2 s | - | Crystal dependent; only when the battery is connected
(firmware allows 5 s)
ADC regulator start- | up | - | 20 µs | Every battery sample
ADC calibration | 116 ADC cycles | - | 116 µs at 1 MHz, | every sample
VREFINT buffer start | 8 µs | 12 µs | Every sample; then at least 4 µs sampling
Flash: one 64- | bit record | 81.69 µs | 90.76 µs | Each log record

RFID Attendance Logger - | Power, capacity and cost | Page 12 of 21
STM32L432 (DS11451 Rev 4) | Typ | Max | Where it applies
Flash: page erase (2 kB) | 22.02 ms | 24.47 ms | Once per 254 records, | and #CLEARLOG
ST25R3916 (DS12484 Rev 8) | Typ | Max | Note
Power- | down to Ready: crystal
start- | up
crystal dependent | - | I_osc at 750 mVpp; firmware waits up to 50 ms
Wake- | up mode: field per
measurement
~20 µs | - | Measured: 41 µs above 40 mA
Measure amplitude command | - | 25 µs | Each re- | arm
Adjust regulators command | - | 5 ms | Start- | up and a supply- | mode change
ISO 14443 guard, | field on to first
command
5 ms | - | Firmware: 5 ms + 1 tick
(APP_NFC_FIELD_GUARD_MS)
No- | response timer | 212 × 64/fc = | 1.0 ms | - | Ends an empty poll (BSP_NFC_NRT_64FC)
Supply: power- | down | 2 µA | 20 µA | Switched off
Supply: wake- | up mode (logic +
RC)
2.8 µA | 20 µA | Between measurements; 3.6 µA in the
datasheet's example
Supply: Ready | 4.5 mA | 7.5 mA | Measured 5.66 mA
Firmware | Time | What it covers
Enter Stop 2 | <100 µs | Mask interrupts, | re- | check the queue and inputs, | write the
LPTIM1 compare (synchronises in ~3 LSE cycles, | 92 µs), | WFI

Shortest / longest Stop
2 sleep
4 ms / 15 s | Shorter waits use Sleep mode; the loop asks for at most 5 s
(BSP_STOP2_MIN/MAX_MS, | APP_SLEEP_MAX_MS)
Enter Standby | ~1 s | Power- | off pattern (700 ms), | flush to flash (up to 24.5 ms with
an erase), | reader power- | down, | wait for the button release

Button debounce / hold /
off / double press

30 ms / 2 s / 5 s / 600 ms APP_BTN_*

VBUS debounce; USB
enumeration timeout
50 ms; 5 s | No enumeration in 5 s means a charger
Battery divider settling | 1. | 2 s | C3 through R7 || R8 = | 171 ms time constant
(APP_BATT_SETTLE_MS)
Flush RAM records | 5 s after the last tap | Or at 80 % full, | on USB attach, | before power- | off
Inactivity switch- | off | 3 min | Suspended while VBUS is present
Open finding: the field guard looks short. | An empty poll keeps the field on 5.7 ms in all, | although the
firmware waits 5 ms + 1 tick before REQA and the no- | response timer then adds about 1 ms. | The buzz is
also shorter than set (50 ms against 60). | Both suggest that the millisecond count runs ahead across short
Stop 2 sleeps, | or that the guard starts before the field does, | so the real guard may be under the 5 ms ISO
14443 requires. | Cards still read, | but it should be confirmed with a GPIO marker on the scope. | Timing the
guard with the reader's own NFC field- | on guard timer would make it independent of the MCU.

RFID Attendance Logger - | Power, capacity and cost | Page 13 of 21

# 6 Charge per event

Charge = | current × time for each load, | summed over the event. | 1 µAh = | 3.6 mC.
Event | What draws current | Charge (typ.) | µAh (typ.) | µAh (pess.)
Accepted card tap | Measured: field 12. | 2 ms, | buzz 50 ms, | Ready + LED to
250 ms, | 1 empty poll
10. | 26 mC | 2.85 | 3.01
Duplicate tap | Same read and poll, | 2 × 60 ms motor at 82 mA + LED | 15. | 19 mC | 4. | 22 | 4.38
False wake- | up | Measured: IRQ, | 5.7 ms empty poll at 228 mA, | re- | arm | 1.33 mC | 0.37 | 0.42
Power- | on (button) | Boot (20 ms at 80 MHz), | reader start, | 120 ms motor,
| | 300 ms LED | | | | 11.05 mC | 3.07 | 3.07
Lecture start (2- | 5 s
hold)
3 s hold, | 60 ms + 3 × 80 ms motor, | 880 ms LED,
marker write
28.32 mC | 7.87 | 7.87
Auto power- | off (3
min idle)
250 ms motor, | 700 ms red LED, | flush, | reader power-
down
22.63 mC | 6. | 29 | 6. | 29
Power- | off (5 s hold) | As above + 5 s hold + 60 ms hold buzz | 29.61 mC | 8. | 23 | 8. | 23

Short press (battery
check)
0. | 2 s press, | two 150 ms green blinks | 0.91 mC | 0. | 25 | 0. | 25
Flash page erase | 22 ms at ~7 mA, | once per 254 records | 0. | 15 mC | 0.04 | 0.04
Battery sample | 1.5 ms MCU + ADC, | every 10 s, | on a heartbeat wake | 1.8 µC | 0.0005 | 0.0005
One accepted card tap, | 10.3 mC (2.85 µAh)
0 | 2 | 4 | mC
Buzz: motor, Ready and LED, 50 ms | 4.60 mC
RF field for the read, 12.2 ms at 202 mA | 2.47 mC
Ready and LED, rest of the pattern, 200 ms | 1.85 mC
Empty poll, 5.7 ms at 228 mA, and re-arm | 1.32 mC
Wake-up IRQ: measurement, oscillator start | 25.9 µC
Flash write + share of page erase | 1.3 µC
Built from the scope captures. | The buzz and the RF field (read plus one empty poll) are 82 % of a tap; the reader in Ready mode
with the LED on for the rest of the pattern is most of the remainder.
Wake-up IRQ = measured, TEK00006 | = 0.026 mC
Read | = 202 mA × 12.2 ms (guard, REQA, anticollision, SELECT) = 2.47 mC
Buzz | = 91 mA × 50 ms (motor, Ready, LED) | = 4.60 mC
Ready + LED = 9.24 mA × 200 ms (rest of the pattern) | = 1.85 mC
Empty poll | = 228 mA × 5.7 ms + re-arm 14 µC | = 1.32 mC
Total | = incl. flash | = 10.26 mC = 2.85 µAh

# 7 A lecture, and battery life

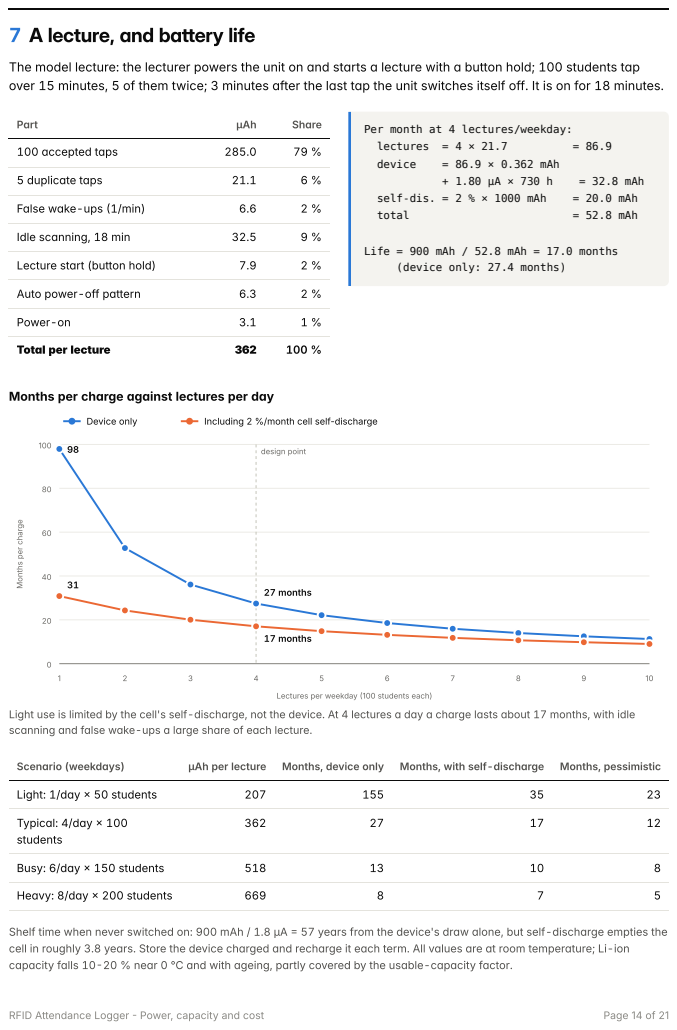
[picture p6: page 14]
RFID Attendance Logger -; Power, capacity and cost; Page 14 of 21; over 15 minutes,; 5 of them twice; 3 minutes after the last tap the unit switches itself off.; It is on for 18 minutes.; Part; µAh; Share; 100 accepted taps; 5 duplicate taps; False wake-; ups (1/min); Idle scanning,; 18 min; Lecture start (button hold); Auto power-; off pattern; Power-; Total per lecture; lectures = 4 × 21.7; device; = 86.9 × 0.362 mAh; = 32.8 mAh; self-dis. = 2 % × 1000 mAh; = 20.0 mAh; total; = 52.8 mAh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

The model lecture: the lecturer powers the unit on and starts a lecture with a button hold; 100 students tap

Per month at 4 lectures/weekday:

Life = 900 mAh / 52.8 mAh = 17.0 months
(device only: 27.4 months)

Months per charge against lectures per day

Months per charge

Lectures per weekday (100 students each)

# 8 Card reads per charge

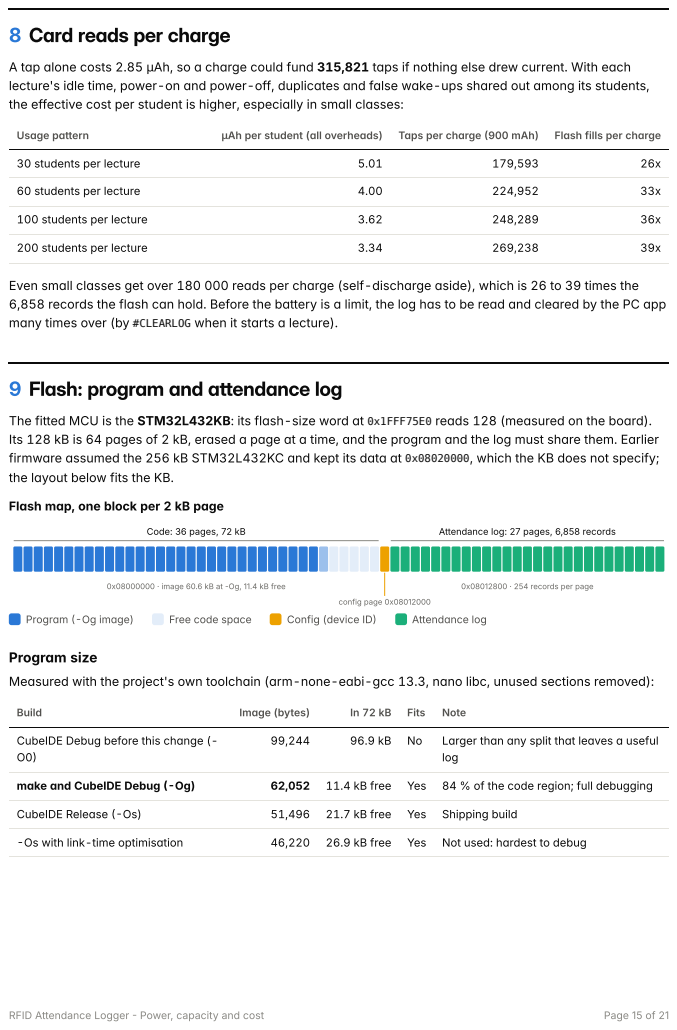
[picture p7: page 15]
RFID Attendance Logger -; Power, capacity and cost; Page 15 of 21; A tap alone costs 2.85 µAh,; so a charge could fund 315,821 taps if nothing else drew current.; With each; lecture's idle time,; power-; on and power-; off,; duplicates and false wake-; ups shared out among its students,; the effective cost per student is higher,; especially in small classes:; Usage pattern; µAh per student (all overheads); Taps per charge (900 mAh); Flash fills per charge; 30 students per lecture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

many times over (by #CLEARLOG when it starts a lecture).

9 Flash: program and attendance log

the layout below fits the KB.

Flash map, one block per 2 kB page

Code: 36 pages, 72 kB

Attendance log: 27 pages, 6,858 records

0x08000000 · image 60.6 kB at -Og, 11.4 kB free

0x08012800 · 254 records per page

CubeIDE Debug before this change (-

RFID Attendance Logger - | Power, capacity and cost | Page 16 of 21
Where the 50.3 kB - | Os image goes
0 | 5,000 | 10,000 | 15,000 | 20,000 | bytes
Application logic (App/) | 19.3 kB
ST HAL drivers | 18.1 kB
Board support (Bsp/) | 5.9 kB
USB device library | 5.5 kB
Startup and CubeMX init (Core/) | 1.4 kB
C library | 0.2 kB
Application code and ST's HAL are about three quarters of the image. | The HAL is used through its generic drivers; replacing it
with direct register code could save several kB more, | at the cost of portability.
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

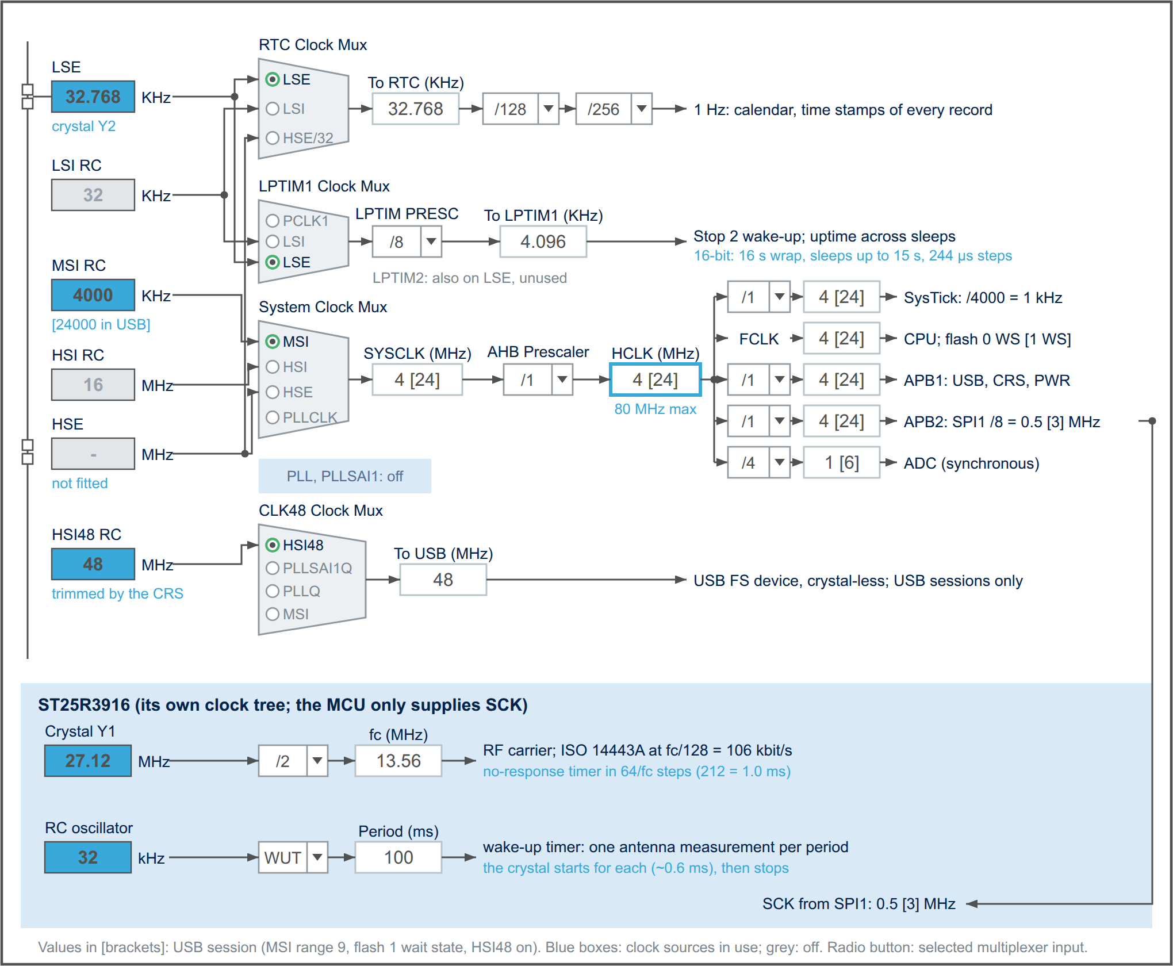
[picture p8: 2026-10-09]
Firmware/docs/clock_tree.png

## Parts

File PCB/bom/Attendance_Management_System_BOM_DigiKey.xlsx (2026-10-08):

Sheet: Read_me
How to order
1. On the BOM sheet set "Boards to build" (B4) and review the yellow Use alternate / Include / Spares cells.
2. Open the DigiKey_Upload sheet. Delete rows whose Quantity is 0 (optional cable parts are off by default), then save it as CSV or copy the rows.
3. On digikey.com use BOM Manager (Upload a BOM) or Cart > Quick Add > "Upload a list", and map: Quantity, Digi-Key Part Number, Customer Reference. digikey_upload_1_board.csv (next to this workbook) is the same list for 1 board with the default choices.
4. Red stock figures on the BOM sheet mean the chosen part has less stock than you are ordering.
Decisions before ordering
U5, NFC reader: ST25R3916-AQWT is out of stock at Digi-Key (the ST25R3916B is not due until 2028). The in-stock ST25R3917-AQWT is pin-compatible but has no capacitive-sensor wake-up, no automatic antenna tuning and no card emulation. It works for this reader if the firmware uses inductive wake-up and J5/J6 stay unconnected. Set U5 "Use alternate" = Y to order it, or source the ST25R3916 elsewhere.
Y2 + C6/C7, 32.768 kHz: no 4 pF-load 3.2x1.5 mm crystal is stocked, so Y2 is a 6 pF part and C6/C7 were changed to 8.2 pF in the schematic (2026-09-26).
R6, charge current: 1 kΩ sets 1 A, above the 500 mA a USB-C sink with 5.1 kΩ CC resistors may draw. The 2 kΩ alternate gives 500 mA.
C20/C21/C36, 10 µF: only 178 of the Samsung part are in stock; switch to the Yageo alternate if that runs out.
Not included
The PCB itself, the Li-ion cell (with a JST XA plug), the vibration motor, the optional PN532 breakout module, solder paste and a JST XA crimp tool. J5/J6 (solder pads) and AE3 (etched antenna) are PCB features, not parts.
Substitutions made against the first choice (all checked on digikey.com)
USBLC6-2SC6 is back-ordered, so the BOM uses USBLC6-2SC6Y. U1 is the 128 kB STM32L432KBU6 (2026-10-07); its Digi-Key number, stock and price have not been looked up, so search the MPN before ordering. Samsung CL21A475KAQNNNE (4.7 µF), CL21B105K (1 µF), CL21A106K (10 µF) and CL21C150J (15 pF, obsolete) and Yageo RC0805FR-075K1L (5.1 kΩ) are out of stock or obsolete, so the listed KEMET, Samsung, Yageo and Stackpole parts replace them.
Checked 2026-09-26. Each row has a Digi-Key search link (column AA) for re-checking stock and price.

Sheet: BOM
Card Attendance System: Bill of Materials (Digi-Key)
Source: PCB/Attendance Management System.kicad_sch. Part numbers, stock and prices read from digikey.com on 2026-09-26; stock and prices change daily, so re-check before ordering.
Boards to build | 1
Edit only the yellow cells: Boards to build, Use alternate (Y/N), Include (Y/N), Spares. Order qty, the part to order and the cost are formulas.
Item | Designators | Qty / board | Value | Description | Package | Manufacturer | MPN | Digi-Key PN | DK stock (2026-09-26) | Unit price (USD) | Price at qty | Use alternate (Y/N) | Alt. manufacturer | Alt. MPN | Alt. Digi-Key PN | Alt. DK stock | Alt. unit price (USD) | Include (Y/N) | Spares | Order qty | Order: manufacturer | Order: MPN | Order: Digi-Key PN | Est. cost (USD) | Notes | Digi-Key link
1 | C1,C3,C8,C11,C22,C23,C24,C25,C28,C29,C30,C34 | 12 | 100n | Capacitor, ceramic, 100 nF 50 V X7R ±10% | 0805 | Samsung Electro-Mechanics | CL21B104KBCNNNC | 1276-1003-1-ND | 4581382 | $0.045 | 10 | N |  |  |  |  |  | Y | 3 |  |  |  |  |  | Schematic asks X7R 16 V; 50 V part has less DC-bias loss. | https://www.digikey.com/en/products/result?keywords=
2 | C2,C35 | 2 | 4.7u | Capacitor, ceramic, 4.7 µF 25 V X5R ±10% | 0805 | Samsung Electro-Mechanics | CL21A475KACLRNC | 1276-2415-1-ND | 190853 | $0.137 | 10 | N |  |  |  |  |  | Y | 2 |  |  |  |  |  | Covers C2 (10 V) and C35 (16 V) with one 25 V part. CL21A475KAQNNNE is out of stock. | https://www.digikey.com/en/products/result?keywords=
3 | C4 | 1 | 10n | Capacitor, ceramic, 10 nF 50 V X7R ±10% | 0805 | Samsung Electro-Mechanics | CL21B103KBANNNC | 1276-1015-1-ND | 2107628 | $0.044 | 10 | N |  |  |  |  |  | Y | 2 |  |  |  |  |  |  | https://www.digikey.com/en/products/result?keywords=
4 | C5,C33 | 2 | 1u | Capacitor, ceramic, 1 µF 25 V X7R ±10% | 0805 | KEMET | C0805C105K3RACTU | 399-C0805C105K3RACTUCT-ND | 373194 | $0.109 | 10 | N |  |  |  |  |  | Y | 2 |  |  |  |  |  | Samsung CL21B105K parts are out of stock. | https://www.digikey.com/en/products/result?keywords=
5 | C6,C7 | 2 | 8.2p | Capacitor, ceramic, 8.2 pF 50 V C0G ±0.25 pF (LSE load caps) | 0805 | KEMET | C0805C829C5GACTU | 399-C0805C829C5GACTUCT-ND | 3279 | $0.372 | 10 | N |  |  |  |  |  | Y | 2 |  |  |  |  |  | Y2 has CL = 6 pF (no 4 pF 3.2x1.5 mm crystal is stocked), which needs 8.2 pF load caps: CL = C/2 + ~2 pF stray. Changed from 4.3p in the schematic on 2026-09-26. | https://www.digikey.com/en/products/result?keywords=
6 | C9,C10 | 2 | 15p | Capacitor, ceramic, 15 pF 50 V C0G ±5% (27.12 MHz load caps) | 0805 | KEMET | C0805C150J5GACTU | 399-C0805C150J5GACTUCT-ND | 28868 | $0.160 | 10 | N |  |  |  |  |  | Y | 2 |  |  |  |  |  | Samsung CL21C150JBANNNC is obsolete. | https://www.digikey.com/en/products/result?keywords=
7 | C12,C13,C38,C39 | 4 | 150p | Capacitor, ceramic, 150 pF 50 V C0G ±5% | 0805 | KEMET | C0805C151J5GACTU | 399-C0805C151J5GACTUCT-ND | 62894 | $0.080 | 10 | N |  |  |  |  |  | Y | 2 |  |  |  |  |  | EMC filter (C12/C13) and RX divider (C38/C39). | https://www.digikey.com/en/products/result?keywords=
8 | C15,C37 | 2 | 10p | Capacitor, ceramic, 10 pF 50 V C0G ±5% | 0805 | KEMET | C0805C100J5GACTU | 399-C0805C100J5GAC7800CT-ND | 215055 | $0.076 | 10 | N |  |  |  |  |  | Y | 2 |  |  |  |  |  | RX divider series caps. Digi-Key number really ends GAC7800CT-ND. | https://www.digikey.com/en/products/result?keywords=
9 | C16,C17 | 2 | 68p | Capacitor, ceramic, 68 pF 50 V C0G ±5% (series matching) | 0805 | KEMET | C0805C680J5GACTU | 399-C0805C680J5GACTUCT-ND | 20555 | $0.106 | 10 | N |  |  |  |  |  | Y | 4 |  |  |  |  |  | Matching values change when the antenna is tuned; spares allow a retune. | https://www.digikey.com/en/products/result?keywords=
10 | C18,C19 | 2 | 270p | Capacitor, ceramic, 270 pF 50 V C0G ±5% (parallel matching) | 0805 | KEMET | C0805C271J5GACTU | 399-C0805C271J5GACTUCT-ND | 147889 | $0.216 | 10 | N |  |  |  |  |  | Y | 4 |  |  |  |  |  | As above. | https://www.digikey.com/en/products/result?keywords=
11 | C20,C21,C36 | 3 | 10u | Capacitor, ceramic, 10 µF 25 V X5R ±10% | 0805 | Samsung Electro-Mechanics | CL21A106KAFN3NE | 1276-2890-1-ND | 178 | $0.158 | 10 | N | YAGEO | CC0805KKX5R6BB106 | 311-1460-1-ND | 5598 | $0.341 | Y | 1 |  |  |  |  |  | Only 178 in stock (enough for ~50 boards). Every other 10 µF 0805 checked (Samsung, Murata, TDK, KEMET) was out of stock. The alternate is 10 V, fine on the 4.2 V BAT+ rail. | https://www.digikey.com/en/products/result?keywords=
12 | C26,C27,C31,C32 | 4 | 2.2u | Capacitor, ceramic, 2.2 µF 25 V X7R ±10% | 0805 | Samsung Electro-Mechanics | CL21B225KAFNNNE | 1276-2954-1-ND | 390169 | $0.087 | 10 | N |  |  |  |  |  | Y | 2 |  |  |  |  |  |  | https://www.digikey.com/en/products/result?keywords=
13 | D1,D5 | 2 | RED | LED, red 631 nm, clear lens | 0805 | Lite-On Inc. | LTST-C170KRKT | 160-1415-1-ND | 436448 | $0.180 | 1 | N |  |  |  |  |  | Y | 1 |  |  |  |  |  | Check the cathode mark against the footprint. | https://www.digikey.com/en/products/result?keywords=
14 | D2,D3,D6 | 3 | GREEN | LED, green 571 nm, clear lens | 0805 | Lite-On Inc. | LTST-C170KGKT | 160-1414-1-ND | 477688 | $0.190 | 1 | N |  |  |  |  |  | Y | 1 |  |  |  |  |  |  | https://www.digikey.com/en/products/result?keywords=
15 | D4 | 1 | SS14 | Diode, Schottky 40 V 1 A (motor flyback) | SMA (DO-214AC) | Vishay General Semiconductor | SS14-E3/61T | SS14-E3/61TGICT-ND | 141918 | $0.470 | 1 | N |  |  |  |  |  | Y | 0 |  |  |  |  |  |  | https://www.digikey.com/en/products/result?keywords=
16 | FB1,FB2 | 2 | 600R@100MHz | Ferrite bead, 600 Ω @ 100 MHz, 300 mA, 0.52 Ω DCR | 0402 | Murata Electronics | BLM15AG601SN1D | 490-1006-1-ND | 1148672 | $0.100 | 1 | N |  |  |  |  |  | Y | 2 |  |  |  |  |  |  | https://www.digikey.com/en/products/result?keywords=
17 | J1 | 1 | USB-C | Connector, USB-C receptacle, USB 2.0, 16-pin, SMT right angle | GCT USB4110 | GCT | USB4110-GF-A | 2073-USB4110-GF-A-1-ND | 145796 | $1.270 | 1 | N |  |  |  |  |  | Y | 0 |  |  |  |  |  |  | https://www.digikey.com/en/products/result?keywords=
18 | J2 | 1 | BATTERY | Connector header, JST XA, 2-pos 2.50 mm, vertical, shrouded, THT | JST B02B-XASK-1 | JST Sales America Inc. | B02B-XASK-1 | 455-B02B-XASK-1-ND | 12098 | $0.160 | 1 | N |  |  |  |  |  | Y | 0 |  |  |  |  |  | Mating cable parts are listed at the end (optional). | https://www.digikey.com/en/products/result?keywords=
19 | J3 | 1 | SWD | Pin header, 1x4, 2.54 mm, vertical, THT | 1x04 P2.54 | Sullins Connector Solutions | PREC004SAAN-RC | 35-PREC004SAAN-RC-ND | 42330 | $0.100 | 1 | N |  |  |  |  |  | Y | 0 |  |  |  |  |  |  | https://www.digikey.com/en/products/result?keywords=
20 | J4 | 1 | VIB_MOTOR | Pin header, 1x2, 2.54 mm, vertical, THT | 1x02 P2.54 | Sullins Connector Solutions | PREC002SAAN-RC | 35-PREC002SAAN-RC-ND | 55276 | $0.100 | 1 | N |  |  |  |  |  | Y | 0 |  |  |  |  |  | The vibration motor itself is not in this BOM. | https://www.digikey.com/en/products/result?keywords=
21 | J5,J6 | 2 | CSO / CSI | Solder pads for the capacitive wake-up electrode wires (PCB feature) | SolderWirePad 1x2 mm |  |  |  |  |  |  | N |  |  |  |  |  | N | 0 |  |  |  |  |  | No part to buy. Leave unconnected if U5 is the ST25R3917 alternate (pins 2/25 must be NC). | https://www.digikey.com/en/products/result?keywords=
22 | J7 | 1 | PN532 | Socket header, 1x8, 2.54 mm, female, vertical, THT | 1x08 P2.54 | Sullins Connector Solutions | PPTC081LFBN-RC | S7006-ND | 29560 | $0.580 | 1 | N |  |  |  |  |  | Y | 0 |  |  |  |  |  | PN532 backup-reader module is not in this BOM. | https://www.digikey.com/en/products/result?keywords=
23 | L3,L4 | 2 | 470nH | Inductor, wirewound ceramic, 470 nH ±5%, 250 mA, 1.76 Ω DCR | 0805 | Coilcraft | 0805CS-471XJRC | 2457-0805CS-471XJRC-ND | 10591 | $1.340 | 1 | N |  |  |  |  |  | Y | 0 |  |  |  |  |  | EMC filter carries the full TX current; 250 mA / 1.76 Ω is the best stocked 470 nH 0805. A 1210 part (e.g. Murata LQH32C) would lose less power but needs a new footprint. | https://www.digikey.com/en/products/result?keywords=
24 | Q1 | 1 | AO3400A | MOSFET, N-ch 30 V 5.7 A (motor driver) | SOT-23 | Alpha & Omega Semiconductor | AO3400A | 785-1000-1-ND | 303749 | $0.520 | 1 | N |  |  |  |  |  | Y | 0 |  |  |  |  |  |  | https://www.digikey.com/en/products/result?keywords=
25 | R1,R2 | 2 | 5.1k | Resistor, 5.1 kΩ ±1% 1/8 W thick film (USB-C CC) | 0805 | Stackpole Electronics | RMCF0805FT5K10 | RMCF0805FT5K10CT-ND | 101761 | $0.027 | 10 | N |  |  |  |  |  | Y | 2 |  |  |  |  |  | Yageo RC0805FR-075K1L is out of stock. | https://www.digikey.com/en/products/result?keywords=
26 | R3,R4,R5,R9,R10 | 5 | 470R | Resistor, 470 Ω ±1% 1/8 W thick film (LED series) | 0805 | Stackpole Electronics | RMCF0805FT470R | RMCF0805FT470RCT-ND | 106645 | $0.027 | 10 | N |  |  |  |  |  | Y | 2 |  |  |  |  |  |  | https://www.digikey.com/en/products/result?keywords=
27 | R6 | 1 | 1k | Resistor, 1 kΩ ±1% 1/8 W (MCP73833 PROG: sets charge current) | 0805 | Stackpole Electronics | RMCF0805FT1K00 | RMCF0805FT1K00CT-ND | 320655 | $0.027 | 10 | N | Stackpole Electronics | RMCF0805FT2K00 | RMCF0805FT2K00CT-ND | 119534 | $0.027 | Y | 2 |  |  |  |  |  | 1 kΩ = 1 A charge current: more than a USB-C sink with 5.1 kΩ Rd may draw (500 mA) and hot for the MSOP-10. Set Use alternate = Y for 2 kΩ (500 mA) after changing the schematic. | https://www.digikey.com/en/products/result?keywords=
28 | R7,R8,R11,R12,R20 | 5 | 10k | Resistor, 10 kΩ ±1% 1/8 W thick film | 0805 | Stackpole Electronics | RMCF0805FT10K0 | RMCF0805FT10K0CT-ND | 3852513 | $0.027 | 10 | N |  |  |  |  |  | Y | 2 |  |  |  |  |  |  | https://www.digikey.com/en/products/result?keywords=
29 | R15 | 1 | 1.5k | Resistor, 1.5 kΩ ±1% 1/8 W (antenna damping) | 0805 | Stackpole Electronics | RMCF0805FT1K50 | RMCF0805FT1K50CT-ND | 149568 | $0.027 | 10 | N |  |  |  |  |  | Y | 2 |  |  |  |  |  | Damping value may change during antenna tuning. | https://www.digikey.com/en/products/result?keywords=
30 | R16,R18,R19 | 3 | 4.7M | Resistor, 4.7 MΩ ±1% 1/8 W (battery and VBUS dividers) | 0805 | Stackpole Electronics | RMCF0805FT4M70 | RMCF0805FT4M70CT-ND | 12637 | $0.031 | 10 | N |  |  |  |  |  | Y | 2 |  |  |  |  |  |  | https://www.digikey.com/en/products/result?keywords=
31 | R17 | 1 | 2.7M | Resistor, 2.7 MΩ ±1% 1/8 W (battery divider low leg) | 0805 | Stackpole Electronics | RMCF0805FT2M70 | RMCF0805FT2M70CT-ND | 6211 | $0.031 | 10 | N |  |  |  |  |  | Y | 2 |  |  |  |  |  |  | https://www.digikey.com/en/products/result?keywords=
32 | R21,R22 | 2 | 0 | Resistor, 0 Ω jumper (antenna feed) | 0805 | Stackpole Electronics | RMCF0805ZT0R00 | RMCF0805ZT0R00CT-ND | 3287189 | $0.010 | 10 | N |  |  |  |  |  | Y | 2 |  |  |  |  |  |  | https://www.digikey.com/en/products/result?keywords=
33 | SW1,SW2,SW3 | 3 | RST / BOOT0 / POWER | Tactile switch, SPST-NO, 180 gf, 2.5 mm height, SMT | C&K PTS636 | C&K | PTS636SM25SMTR LFS | CKN12321-1-ND | 20227 | $0.290 | 1 | N |  |  |  |  |  | Y | 0 |  |  |  |  |  | Footprint is PTS636Sx25SMTRLFS; SM = 180 gf actuation. | https://www.digikey.com/en/products/result?keywords=
34 | TH1 | 1 | 10k NTC | NTC thermistor, 10 kΩ ±5%, B25/85 = 3977 K, leaded bead | THT, vertical | Vishay BC Components | NTCLE100E3103JB0 | BC2301-ND | 10220 | $0.600 | 1 | N |  |  |  |  |  | Y | 0 |  |  |  |  |  | Flexible leads; bend to the 1.9 mm footprint pitch. | https://www.digikey.com/en/products/result?keywords=
35 | U1 | 1 | STM32L432KBU6 | MCU, Arm Cortex-M4F 80 MHz, 128 kB flash, 64 kB RAM | UFQFPN-32 5x5 | STMicroelectronics | STM32L432KBU6 |  |  |  | 1 | N |  |  |  |  |  | Y | 0 |  |  |  |  |  | 128 kB part, as on the schematic and in production/bom.csv; the firmware keeps code (72 kB) and the log (56 kB) within 128 kB. Digi-Key number, stock and price not looked up yet: search the MPN before ordering (cost counts 0 until then). | https://www.digikey.com/en/products/result?keywords=
36 | U2 | 1 | MCP73833 | Li-ion charger, 1 cell, 4.20 V, up to 1 A | MSOP-10 | Microchip Technology | MCP73833-AMI/UN | MCP73833-AMI/UN-ND | 1437 | $1.140 | 1 | N |  |  |  |  |  | Y | 0 |  |  |  |  |  | AMI = 4.20 V regulation variant. | https://www.digikey.com/en/products/result?keywords=
37 | U3 | 1 | TPS7A0233 | LDO, 3.3 V 200 mA, 25 nA IQ | SOT-23-5 (DBV) | Texas Instruments | TPS7A0233PDBVR | 296-TPS7A0233PDBVRCT-ND | 6864 | $0.840 | 1 | N |  |  |  |  |  | Y | 0 |  |  |  |  |  |  | https://www.digikey.com/en/products/result?keywords=
38 | U5 | 1 | ST25R3916 | NFC reader IC, 13.56 MHz, SPI | VFQFPN-32 5x5 | STMicroelectronics | ST25R3916-AQWT | 497-18366-1-ND | 0 | $6.510 | 1 | N | STMicroelectronics | ST25R3917-AQWT | 497-ST25R3917-AQWTCT-ND | 4278 | $6.040 | Y | 0 |  |  |  |  |  | DECISION NEEDED: ST25R3916-AQWT (and the newer ST25R3916B) are out of stock at Digi-Key. The ST25R3917 is pin-compatible (same datasheet DS12484) and in stock, but it has no capacitive-sensor wake-up, no AAT and no card emulation; pins 2, 17-19 and 25 must be left unconnected. Use it only with the inductive wake-up and J5/J6 unfitted. | https://www.digikey.com/en/products/result?keywords=
39 | U6 | 1 | USBLC6-2SC6 | USB ESD protection, 2 lines + VBUS | SOT-23-6 | STMicroelectronics | USBLC6-2SC6Y | 497-11882-1-ND | 39458 | $0.710 | 1 | N |  |  |  |  |  | Y | 0 |  |  |  |  |  | Automotive-grade version of USBLC6-2SC6, same pinout. USBLC6-2SC6 (497-5235-1-ND) is back-ordered. | https://www.digikey.com/en/products/result?keywords=
40 | Y1 | 1 | 27.12MHz | Crystal, 27.12 MHz, CL 10 pF, ±10 ppm | 3.2x2.5 mm 4-SMD | Abracon LLC | ABM8-27.120MHZ-10-D1G-T | 535-14403-1-ND | 15659 | $0.460 | 1 | N |  |  |  |  |  | Y | 0 |  |  |  |  |  | CL 10 pF matches C9/C10 = 15 pF (7.5 pF + ~2.5 pF stray). | https://www.digikey.com/en/products/result?keywords=
41 | Y2 | 1 | 32.768k | Crystal, 32.768 kHz, CL 6 pF, ±20 ppm | 3.2x1.5 mm 2-SMD | Abracon LLC | ABS07-120-32.768KHZ-T | 535-11937-1-ND | 52806 | $0.940 | 1 | N |  |  |  |  |  | Y | 0 |  |  |  |  |  | Lowest-CL 3.2x1.5 mm crystal in stock (no 4 pF part). Needs the 8.2 pF load caps C6/C7. Check the land pattern against the EuroQuartz EQ161 footprint. | https://www.digikey.com/en/products/result?keywords=
42 | AE3 | 1 | Antenna_Loop | NFC loop antenna (PCB copper) | PCB trace |  |  |  |  |  |  | N |  |  |  |  |  | N | 0 |  |  |  |  |  | Etched on the PCB: nothing to buy. | https://www.digikey.com/en/products/result?keywords=
43 | (cable) J2 mate | 1 | XAP-02V-1 | Battery cable: JST XA 2-pos receptacle housing |  | JST Sales America Inc. | XAP-02V-1 | 455-1903-ND | 74040 | $0.100 | 1 | N |  |  |  |  |  | N | 1 |  |  |  |  |  | Optional: only if you make the battery lead yourself. Set Include = Y. | https://www.digikey.com/en/products/result?keywords=
44 | (cable) J2 mate | 2 | SXA-001T-P0.6 | Battery cable: JST XA crimp socket contact, 22-28 AWG |  | JST Sales America Inc. | SXA-001T-P0.6 | 455-1904TR-ND | 112000 | $0.018 | 1 | N |  |  |  |  |  | N | 2 |  |  |  |  |  | Optional. Sold from qty 1 on tape; needs a JST XA crimp tool. | https://www.digikey.com/en/products/result?keywords=
 |  |  |  |  |  |  |  |  |  |  |  |  |  |  |  |  |  |  |  |  |  |  | Estimated total (USD) |  | Estimate only: unit prices are the quoted break (column L). Digi-Key reprices the whole order at the quantities you actually buy. Excludes PCB, battery, motor, PN532 module, shipping and tax.
 |  |  |  |  |  |  |  |  |  |  |  |  |  |  |  |  |  |  |  |  |  |  | Parts to order (lines with qty > 0)

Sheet: DigiKey_Upload
Quantity | Digi-Key Part Number | Manufacturer Part Number | Manufacturer | Customer Reference

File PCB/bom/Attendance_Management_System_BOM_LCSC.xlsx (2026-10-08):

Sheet: Read_me
Two ways to use this BOM
Every orderable symbol in the schematic now carries a hidden LCSC field with the number used here, so the Fabrication Toolkit fills the LCSC column of production/bom.csv itself once the board is updated from the schematic.
JLCPCB assembly: upload jlcpcb_bom.csv (next to this workbook, same as the JLCPCB_BOM sheet) with production/positions.csv from the Fabrication Toolkit. U1 is out of stock there, so mark it "do not place" and solder it yourself, or send one to JLCPCB as a consigned part. J2, J3, J4, J7 and TH1 are through-hole: add JLCPCB's through-hole assembly or solder them by hand. Check part rotations in JLCPCB's placement preview before you pay.
Buying parts from LCSC to build by hand: set "Boards to build" (B4) on the BOM sheet, review the yellow cells, then copy the LCSC_Order sheet into LCSC's BOM tool (lcsc.com > BOM Tool) or add the parts to the cart. Delete rows whose Quantity is 0 (the optional battery-cable parts are off by default). LCSC sells most passives in minimum lots of 10 to 100, so the order quantities are rounded up to those.
Red stock figures on the BOM sheet mean the chosen part has less stock than you need.
JLCPCB library types
Basic parts are already loaded on JLCPCB's machines. Extended parts each carry a one-off loading fee per part type per order; Preferred extended parts have that fee waived on Economic assembly. The BOM sheet counts the Extended types you are ordering. Passives use Basic parts wherever one exists in the right value and 0805 size; the small C0G values, 4.7 MΩ and 2.7 MΩ are not in the Basic library.
Decisions before ordering
U1 is the 128 kB STM32L432KBU6 (C2928224), as in production/bom.csv: since 2026-10-07 the firmware keeps its code and attendance log within 128 kB. Its stock, price and JLCPCB library type have not been re-read; check them before ordering.
Y2 + C6/C7: no 4 pF-load 3.2x1.5 mm crystal is stocked, so Y2 is a 6 pF Epson FC-135 and C6/C7 were changed to 8.2 pF in the schematic (2026-09-26).
R6: 1 kΩ sets a 1 A charge current, above the 500 mA a USB-C sink with 5.1 kΩ CC resistors may draw. The 2 kΩ alternate gives 500 mA.
U5: ST25R3916-AQWT is in stock at LCSC (about 100) although Digi-Key has none. Order early if you need more than a few boards.
Substitutions against the schematic or the Digi-Key BOM (all checked on lcsc.com / jlcpcb.com)
SW1-SW3: PTS636 SK25 (250 gf) because the SM25 (180 gf) is out of stock; same footprint. U2: MCP73833T-AMI/UN, the tape-and-reel version. L3/L4: Murata LQW2BASR47J00L, same rating as the Coilcraft 0805CS-471. Y1: YXC 27.12 MHz, 10 pF, instead of the Abracon ABM8 (1 in stock). D2/D3/D6: Lite-On LTST-C170KGKT, not the Basic green LED (its 2.6-3.1 V forward voltage is too high for D6 on 3.3 V). J1: LCSC shows 0 but JLCPCB assembly holds 710; for hand assembly buy it from Digi-Key.
Not included
The PCB, the Li-ion cell (with a JST XA plug), the vibration motor, the optional PN532 breakout module, solder paste and a JST XA crimp tool. J5/J6 (solder pads) and AE3 (etched antenna) are PCB features, not parts.
Checked 2026-09-26. Each row has an LCSC link (last column) for re-checking stock and price.

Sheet: BOM
Card Attendance System: Bill of Materials (LCSC / JLCPCB)
Source: PCB/Attendance Management System.kicad_sch. Part numbers, stock, minimum order quantities, prices and JLCPCB library types read from lcsc.com and jlcpcb.com on 2026-09-26; they change daily, so re-check before ordering.
Boards to build | 1
Edit only the yellow cells: Boards to build, Use alternate (Y/N), Include (Y/N), Spares. Needed qty, LCSC order qty (rounded up to the LCSC minimum lot), the part to order and the cost are formulas.
Item | Designators | Qty / board | Value | Description | Footprint | Manufacturer | MPN | LCSC # | JLCPCB library | LCSC stock (2026-09-26) | JLCPCB stock | LCSC min / multiple | Unit price at min (USD) | Use alternate (Y/N) | Alt. value | Alt. manufacturer | Alt. MPN | Alt. LCSC # | Alt. JLCPCB library | Alt. LCSC stock | Alt. JLCPCB stock | Alt. min / multiple | Alt. unit price (USD) | Include (Y/N) | Spares | Needed qty | LCSC order qty | Order: value | Order: manufacturer | Order: MPN | Order: LCSC # | Order: JLCPCB library | Boards the JLCPCB stock covers | Est. cost (USD) | Notes | LCSC link
1 | C1,C3,C8,C11,C22,C23,C24,C25,C28,C29,C30,C34 | 12 | 100n | Capacitor, 100 nF 50 V X7R ±10% | 0805 | YAGEO | CC0805KRX7R9BB104 | C49678 | Basic | 9771320 | 18198779 | 20 | $0.0192 | N |  |  |  |  |  |  |  |  |  | Y | 0 |  |  |  |  |  |  |  |  |  | Schematic asks X7R 16 V; the 50 V Basic part has less DC-bias loss. | open (https://www.lcsc.com/product-detail/)
2 | C2,C35 | 2 | 4.7u | Capacitor, 4.7 µF 25 V X5R ±10% | 0805 | Samsung Electro-Mechanics | CL21A475KAQNNNE | C1779 | Basic | 1968760 | 2946783 | 20 | $0.0348 | N |  |  |  |  |  |  |  |  |  | Y | 0 |  |  |  |  |  |  |  |  |  | One 25 V part covers C2 (10 V) and C35 (16 V). | open (https://www.lcsc.com/product-detail/)
3 | C4 | 1 | 10n | Capacitor, 10 nF 50 V X7R ±10% | 0805 | Samsung Electro-Mechanics | CL21B103KBANNNC | C1710 | Basic | 1184600 | 2362717 | 50 | $0.0116 | N |  |  |  |  |  |  |  |  |  | Y | 0 |  |  |  |  |  |  |  |  |  |  | open (https://www.lcsc.com/product-detail/)
4 | C5,C33 | 2 | 1u | Capacitor, 1 µF 50 V X7R ±10% | 0805 | Samsung Electro-Mechanics | CL21B105KBFNNNE | C28323 | Basic | 271530 | 2506668 | 10 | $0.0403 | N |  |  |  |  |  |  |  |  |  | Y | 0 |  |  |  |  |  |  |  |  |  |  | open (https://www.lcsc.com/product-detail/)
5 | C6,C7 | 2 | 8.2p | Capacitor, 8.2 pF 50 V C0G ±0.25 pF (32.768 kHz load caps) | 0805 | FH | 0805CG8R2C500NT | C1840 | Extended | 34100 | 34887 | 50 | $0.0110 | N |  |  |  |  |  |  |  |  |  | Y | 0 |  |  |  |  |  |  |  |  |  | Y2 has CL = 6 pF, so C6/C7 need about 2 x (6 - 2 pF stray) = 8 pF. Changed from 4.3p in the schematic on 2026-09-26. | open (https://www.lcsc.com/product-detail/)
6 | C9,C10 | 2 | 15p | Capacitor, 15 pF 50 V C0G ±5% (27.12 MHz load caps) | 0805 | YAGEO | CC0805JRNPO9BN150 | C107110 | Preferred ext. | 118450 | 165907 | 50 | $0.0095 | N |  |  |  |  |  |  |  |  |  | Y | 0 |  |  |  |  |  |  |  |  |  |  | open (https://www.lcsc.com/product-detail/)
7 | C12,C13,C38,C39 | 4 | 150p | Capacitor, 150 pF 50 V C0G ±5% | 0805 | YAGEO | CC0805JRNPO9BN151 | C107111 | Extended | 183200 | 184665 | 50 | $0.0081 | N |  |  |  |  |  |  |  |  |  | Y | 0 |  |  |  |  |  |  |  |  |  | EMC filter (C12/C13) and RX divider (C38/C39). | open (https://www.lcsc.com/product-detail/)
8 | C15,C37 | 2 | 10p | Capacitor, 10 pF 50 V C0G ±5% (RX divider) | 0805 | YAGEO | CC0805JRNPO9BN100 | C107107 | Extended | 467700 | 494538 | 100 | $0.0184 | N |  |  |  |  |  |  |  |  |  | Y | 0 |  |  |  |  |  |  |  |  |  |  | open (https://www.lcsc.com/product-detail/)
9 | C16,C17 | 2 | 68p | Capacitor, 68 pF 50 V C0G ±5% (series matching) | 0805 | YAGEO | CC0805JRNPO9BN680 | C107120 | Extended | 45050 | 47387 | 50 | $0.0101 | N |  |  |  |  |  |  |  |  |  | Y | 0 |  |  |  |  |  |  |  |  |  | Matching values change when the antenna is tuned; the LCSC minimum lot leaves spares for a retune. | open (https://www.lcsc.com/product-detail/)
10 | C18,C19 | 2 | 270p | Capacitor, 270 pF 100 V C0G ±5% (parallel matching) | 0805 | YAGEO | CC0805JRNPO0BN271 | C107106 | Extended | 15500 | 15534 | 50 | $0.0160 | N |  |  |  |  |  |  |  |  |  | Y | 0 |  |  |  |  |  |  |  |  |  | As above. | open (https://www.lcsc.com/product-detail/)
11 | C20,C21,C36 | 3 | 10u | Capacitor, 10 µF 25 V X5R ±10% | 0805 | Samsung Electro-Mechanics | CL21A106KAYNNNE | C15850 | Basic | 1512600 | 5574591 | 20 | $0.0798 | N |  |  |  |  |  |  |  |  |  | Y | 0 |  |  |  |  |  |  |  |  |  |  | open (https://www.lcsc.com/product-detail/)
12 | C26,C27,C31,C32 | 4 | 2.2u | Capacitor, 2.2 µF 50 V X5R ±10% | 0805 | Samsung Electro-Mechanics | CL21A225KBQNNNE | C377773 | Basic | 194170 | 685779 | 10 | $0.0536 | N |  |  |  |  |  |  |  |  |  | Y | 0 |  |  |  |  |  |  |  |  |  |  | open (https://www.lcsc.com/product-detail/)
13 | D1,D5 | 2 | RED | LED, red 630 nm | 0805 | NATIONSTAR | NCD0805R1 | C84256 | Basic | 4428400 | 5303999 | 50 | $0.0135 | N |  |  |  |  |  |  |  |  |  | Y | 0 |  |  |  |  |  |  |  |  |  | Check the cathode mark against the footprint. | open (https://www.lcsc.com/product-detail/)
14 | D2,D3,D6 | 3 | GREEN | LED, yellow-green 571 nm (AlInGaP, Vf ~2 V) | 0805 | LITEON | LTST-C170KGKT | C98221 | Extended | 254200 | 254219 | 20 | $0.0315 | N |  |  |  |  |  |  |  |  |  | Y | 0 |  |  |  |  |  |  |  |  |  | Not the Basic green (KT-0805G, C2297): that is a 525 nm InGaN LED with Vf 2.6-3.1 V, which barely lights on D6 (PA2 at 3.3 V through 470 R). | open (https://www.lcsc.com/product-detail/)
15 | D4 | 1 | SS14 | Diode, Schottky 40 V 1 A (motor flyback) | D_SMA | MDD(Microdiode Semiconductor) | SS14 | C2480 | Basic | 890450 | 1205634 | 50 | $0.0192 | N |  |  |  |  |  |  |  |  |  | Y | 0 |  |  |  |  |  |  |  |  |  |  | open (https://www.lcsc.com/product-detail/)
16 | FB1,FB2 | 2 | 600R@100MHz | Ferrite bead, 600 Ω @ 100 MHz, 300 mA, 0.52 Ω | 0402 | muRata | BLM15AG601SN1D | C76884 | Extended | 1475200 | 1493001 | 100 | $0.0099 | N |  |  |  |  |  |  |  |  |  | Y | 0 |  |  |  |  |  |  |  |  |  |  | open (https://www.lcsc.com/product-detail/)
17 | J1 | 1 | USB-C | USB-C receptacle, USB 2.0, 16-pin, SMT | USB_C_Receptacle_GCT_USB4110 | Global Connector Technology | USB4110-GF-A | C5143397 | Extended | 0 | 710 | 1 | $1.4914 | N |  |  |  |  |  |  |  |  |  | Y | 0 |  |  |  |  |  |  |  |  |  | LCSC shows 0 in stock but JLCPCB assembly holds 710. For hand assembly buy it from Digi-Key (2073-USB4110-GF-A-1-ND). | open (https://www.lcsc.com/product-detail/)
18 | J2 | 1 | BATTERY | JST XA header, 2-pos 2.50 mm, vertical, THT | JST_XA_B02B-XASK-1_1x02_P2.50mm_Vertical | JST | B02B-XASK-1(LF)(SN) | C263753 | Extended | 28050 | 28059 | 10 | $0.0764 | N |  |  |  |  |  |  |  |  |  | Y | 0 |  |  |  |  |  |  |  |  |  | Through-hole. | open (https://www.lcsc.com/product-detail/)
19 | J3 | 1 | SWD | Pin header, 1x4, 2.54 mm, vertical, THT | PinHeader_1x04_P2.54mm_Vertical | XFCN | PZ254V-11-04P | C2691448 | Extended | 933760 | 1010306 | 20 | $0.0276 | N |  |  |  |  |  |  |  |  |  | Y | 0 |  |  |  |  |  |  |  |  |  | Through-hole. | open (https://www.lcsc.com/product-detail/)
20 | J4 | 1 | VIB_MOTOR | Pin header, 1x2, 2.54 mm, vertical, THT | PinHeader_1x02_P2.54mm_Vertical | XFCN | PZ254V-11-02P | C492401 | Extended | 1151250 | 1161591 | 50 | $0.0184 | N |  |  |  |  |  |  |  |  |  | Y | 0 |  |  |  |  |  |  |  |  |  | Through-hole. The motor itself is not in this BOM. | open (https://www.lcsc.com/product-detail/)
21 | J5,J6 | 2 | CSO / CSI | Solder pads for the capacitive-sensor electrode (PCB feature) | SolderWirePad_1x01_SMD_1x2mm |  |  |  |  |  |  |  |  | N |  |  |  |  |  |  |  |  |  | N | 0 |  |  |  |  |  |  |  |  |  | Nothing to buy. | open (https://www.lcsc.com/product-detail/)
22 | J7 | 1 | PN532 | Socket header, 1x8, 2.54 mm, female, vertical, THT | PinSocket_1x08_P2.54mm_Vertical | JXTCONN | PM2.54-1X8PM-H85 | C42431840 | Extended | 21230 | 21231 | 5 | $0.1130 | N |  |  |  |  |  |  |  |  |  | Y | 0 |  |  |  |  |  |  |  |  |  | Through-hole. The PN532 module is not in this BOM. | open (https://www.lcsc.com/product-detail/)
23 | L3,L4 | 2 | 470nH | Inductor, wirewound ceramic, 470 nH ±5%, 250 mA, 1.76 Ω | 0805 | muRata | LQW2BASR47J00L | C337959 | Extended | 4980 | 4980 | 5 | $0.1242 | N |  |  |  |  |  |  |  |  |  | Y | 0 |  |  |  |  |  |  |  |  |  | Same rating as the Coilcraft 0805CS-471 in the Digi-Key BOM. The multilayer-ferrite 470 nH parts at LCSC (e.g. TDK MLF2012) have lower DCR but a ferrite core, which is worse for the RF drive. | open (https://www.lcsc.com/product-detail/)
24 | Q1 | 1 | AO3400A | MOSFET, N-ch 30 V 5.7 A (motor driver) | SOT-23 | AOS | AO3400A | C20917 | Basic | 681455 | 1074077 | 5 | $0.0853 | N |  |  |  |  |  |  |  |  |  | Y | 0 |  |  |  |  |  |  |  |  |  |  | open (https://www.lcsc.com/product-detail/)
25 | R1,R2 | 2 | 5.1k | Resistor, 5.1 kΩ ±1% 1/8 W (USB-C CC) | 0805 | UNI-ROYAL | 0805W8F5101T5E | C27834 | Basic | 2477700 | 3573872 | 100 | $0.0056 | N |  |  |  |  |  |  |  |  |  | Y | 0 |  |  |  |  |  |  |  |  |  |  | open (https://www.lcsc.com/product-detail/)
26 | R3,R4,R5,R9,R10 | 5 | 470R | Resistor, 470 Ω ±1% 1/8 W (LED series) | 0805 | UNI-ROYAL | 0805W8F4700T5E | C17710 | Basic | 2280000 | 2879988 | 100 | $0.0049 | N |  |  |  |  |  |  |  |  |  | Y | 0 |  |  |  |  |  |  |  |  |  |  | open (https://www.lcsc.com/product-detail/)
27 | R6 | 1 | 1k | Resistor, ±1% 1/8 W (MCP73833 PROG: sets charge current) | 0805 | UNI-ROYAL | 0805W8F1001T5E | C17513 | Basic | 27482800 | 31829451 | 100 | $0.0041 | N | 2k | UNI-ROYAL | 0805W8F2001T5E | C17604 | Basic | 4433300 | 5690088 | 100 | $0.0039 | Y | 0 |  |  |  |  |  |  |  |  |  | 1 kΩ = 1 A charge current, more than a USB-C sink with 5.1 kΩ Rd may draw (500 mA). Set Use alternate = Y for 2 kΩ (500 mA) after changing the schematic. | open (https://www.lcsc.com/product-detail/)
28 | R7,R8,R11,R12,R20 | 5 | 10k | Resistor, 10 kΩ ±1% 1/8 W | 0805 | UNI-ROYAL | 0805W8F1002T5E | C17414 | Basic | 44415400 | 51391005 | 100 | $0.0039 | N |  |  |  |  |  |  |  |  |  | Y | 0 |  |  |  |  |  |  |  |  |  |  | open (https://www.lcsc.com/product-detail/)
29 | R15 | 1 | 1.5k | Resistor, 1.5 kΩ ±1% 1/8 W (antenna damping) | 0805 | UNI-ROYAL | 0805W8F1501T5E | C4310 | Basic | 445400 | 832480 | 100 | $0.0035 | N |  |  |  |  |  |  |  |  |  | Y | 0 |  |  |  |  |  |  |  |  |  | May change during antenna tuning. | open (https://www.lcsc.com/product-detail/)
30 | R16,R18,R19 | 3 | 4.7M | Resistor, 4.7 MΩ ±1% 1/8 W (battery and VBUS dividers) | 0805 | UNI-ROYAL | 0805W8F4704T5E | C17674 | Extended | 76200 | 77104 | 100 | $0.0030 | N |  |  |  |  |  |  |  |  |  | Y | 0 |  |  |  |  |  |  |  |  |  |  | open (https://www.lcsc.com/product-detail/)
31 | R17 | 1 | 2.7M | Resistor, 2.7 MΩ ±1% 1/8 W (battery divider low leg) | 0805 | UNI-ROYAL | 0805W8F2704T5E | C17531 | Extended | 29200 | 29539 | 100 | $0.0048 | N |  |  |  |  |  |  |  |  |  | Y | 0 |  |  |  |  |  |  |  |  |  |  | open (https://www.lcsc.com/product-detail/)
32 | R21,R22 | 2 | 0 | Resistor, 0 Ω jumper (antenna feed) | 0805 | UNI-ROYAL | 0805W8F0000T5E | C17477 | Basic | 5411400 | 7103041 | 100 | $0.0045 | N |  |  |  |  |  |  |  |  |  | Y | 0 |  |  |  |  |  |  |  |  |  |  | open (https://www.lcsc.com/product-detail/)
33 | SW1,SW2,SW3 | 3 | RST / BOOT0 / POWER | Tactile switch, SPST-NO, 250 gf, 2.5 mm height, SMT | SW_Tactile_SPST_NO_Straight_CK_PTS636Sx25SMTRLFS | C&K | PTS636SK25SMTRLFS | C2689642 | Extended | 3520 | 3524 | 5 | $0.2615 | N |  |  |  |  |  |  |  |  |  | Y | 0 |  |  |  |  |  |  |  |  |  | PTS636 SK25 (250 gf) because the SM25 (180 gf, C2799946) is out of stock at LCSC. Same footprint, slightly stiffer press. | open (https://www.lcsc.com/product-detail/)
34 | TH1 | 1 | 10k NTC | NTC thermistor, 10 kΩ ±5%, B25/85 = 3977 K, leaded | R_Axial_DIN0204_L3.6mm_D1.6mm_P1.90mm_Vertical | VISHAY | NTCLE100E3103JB0 | C141588 | Extended | 266 | 266 | 1 | $0.6261 | N |  |  |  |  |  |  |  |  |  | Y | 0 |  |  |  |  |  |  |  |  |  | Through-hole; bend the leads to the 1.9 mm footprint pitch. | open (https://www.lcsc.com/product-detail/)
35 | U1 | 1 | STM32L432KBU6 | MCU, Cortex-M4F 80 MHz, 128 kB flash, 64 kB RAM | QFN-32-1EP_5x5mm_P0.5mm_EP3.45x3.45mm | ST | STM32L432KBU6 | C2928224 | Extended |  |  | 1 |  | N |  |  |  |  |  |  |  |  |  | Y | 0 |  |  |  |  |  |  |  |  |  | 128 kB part, as on the schematic and in production/bom.csv; the firmware keeps code (72 kB) and the log (56 kB) within 128 kB. Stock, price and JLCPCB library type not re-read for this part: check lcsc.com before ordering (cost counts 0 until then). | open (https://www.lcsc.com/product-detail/)
36 | U2 | 1 | MCP73833 | Li-ion charger, 1 cell, 4.20 V, up to 1 A | MSOP-10_3x3mm_P0.5mm | MICROCHIP | MCP73833T-AMI/UN | C627668 | Extended | 208 | 208 | 1 | $1.9017 | N |  |  |  |  |  |  |  |  |  | Y | 0 |  |  |  |  |  |  |  |  |  | MCP73833T-AMI/UN is the tape-and-reel version of MCP73833-AMI/UN (C511281, out of stock). AMI = 4.20 V. | open (https://www.lcsc.com/product-detail/)
37 | U3 | 1 | TPS7A0233 | LDO, 3.3 V 200 mA, 25 nA IQ | SOT23_DBV_TEX-L | TI | TPS7A0233PDBVR | C2887324 | Extended | 8793 | 8793 | 1 | $0.5665 | N |  |  |  |  |  |  |  |  |  | Y | 0 |  |  |  |  |  |  |  |  |  |  | open (https://www.lcsc.com/product-detail/)
38 | U5 | 1 | ST25R3916 | NFC reader IC, 13.56 MHz, SPI | QFN50P500X500X100-33N | ST | ST25R3916-AQWT | C2908147 | Extended | 100 | 100 | 1 | $5.4546 | N | ST25R3916B | ST | ST25R3916B-AQWT | C5267436 | Extended | 180 | 180 | 1 | $4.8285 | Y | 0 |  |  |  |  |  |  |  |  |  | In stock at LCSC (unlike Digi-Key), but only about 100. The alternate is the newer ST25R3916B-AQWT; check its datasheet for differences before swapping. | open (https://www.lcsc.com/product-detail/)
39 | U6 | 1 | USBLC6-2SC6 | USB ESD protection, 2 lines + VBUS | SOT-23-6 | ST | USBLC6-2SC6 | C7519 | Extended | 43755 | 45736 | 5 | $0.1778 | N |  |  |  |  |  |  |  |  |  | Y | 0 |  |  |  |  |  |  |  |  |  | Genuine ST part. | open (https://www.lcsc.com/product-detail/)
40 | Y1 | 1 | 27.12MHz | Crystal, 27.12 MHz, CL 10 pF, ±10 ppm, 50 Ω | Crystal_SMD_3225-4Pin_3.2x2.5mm_HandSoldering | YXC Crystal Oscillators | X32252712MMB4SI | C29975 | Extended | 6440 | 9243 | 5 | $0.1106 | N |  |  |  |  |  |  |  |  |  | Y | 0 |  |  |  |  |  |  |  |  |  | CL 10 pF matches C9/C10 = 15 pF. The Abracon ABM8 part (C1986308) has only 1 in stock. | open (https://www.lcsc.com/product-detail/)
41 | Y2 | 1 | 32.768k | Crystal, 32.768 kHz, CL 6 pF, ±20 ppm, 3.2x1.5 mm | Crystal_SMD_EuroQuartz_EQ161-2Pin_3.2x1.5mm | EPSON | Q13FC13500049 | C95361 | Extended | 129910 | 136924 | 5 | $0.2032 | N |  |  |  |  |  |  |  |  |  | Y | 0 |  |  |  |  |  |  |  |  |  | Epson FC-135. No 4 pF crystal comes in 3.2x1.5 mm at LCSC (4 pF parts are 2.0x1.2 mm), so C6/C7 are 8.2 pF. | open (https://www.lcsc.com/product-detail/)
42 | AE3 | 1 | Antenna_Loop | NFC loop antenna (PCB copper) | NFC_Loop_40x30_3T |  |  |  |  |  |  |  |  | N |  |  |  |  |  |  |  |  |  | N | 0 |  |  |  |  |  |  |  |  |  | Etched on the PCB: nothing to buy. | open (https://www.lcsc.com/product-detail/)
43 | (cable) J2 mate | 1 | XAP-02V-1 | Battery cable: JST XA 2-pos housing |  | JST | XAP-02V-1 | C157892 | Extended | 48240 | 48250 | 20 | $0.0358 | N |  |  |  |  |  |  |  |  |  | N | 0 |  |  |  |  |  |  |  |  |  | Optional: only if you make the battery lead yourself. Set Include = Y. | open (https://www.lcsc.com/product-detail/)
44 | (cable) J2 mate | 2 | SXA-001T-P0.6 | Battery cable: JST XA crimp contact, 22-28 AWG |  | JST | SXA-001T-P0.6 | C246759 | Extended | 328100 | 328137 | 50 | $0.0129 | N |  |  |  |  |  |  |  |  |  | N | 0 |  |  |  |  |  |  |  |  |  | Optional. Needs a JST XA crimp tool. | open (https://www.lcsc.com/product-detail/)
 |  |  |  |  |  |  |  |  |  |  |  |  |  |  |  |  |  |  |  |  |  |  |  |  |  |  |  |  |  |  | Estimated LCSC parts total (USD) |  |  |  | Estimate only, at the price for the LCSC minimum lot. Excludes the PCB, JLCPCB assembly and loading fees, battery, motor, PN532 module, shipping and tax.
 |  |  |  |  |  |  |  |  |  |  |  |  |  |  |  |  |  |  |  |  |  |  |  |  |  |  |  |  |  |  | Lines to order (order qty > 0)
 |  |  |  |  |  |  |  |  |  |  |  |  |  |  |  |  |  |  |  |  |  |  |  |  |  |  |  |  |  |  | JLCPCB Extended part types (each has a loading fee)
 |  |  |  |  |  |  |  |  |  |  |  |  |  |  |  |  |  |  |  |  |  |  |  |  |  |  |  |  |  |  | JLCPCB Basic / Preferred ext. types (no loading fee)

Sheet: JLCPCB_BOM
Comment | Designator | Footprint | LCSC Part #

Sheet: LCSC_Order
Quantity | LCSC Part Number | Manufacturer Part Number | Manufacturer | Customer Reference

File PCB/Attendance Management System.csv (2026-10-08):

Reference | Qty | Value | Footprint | Description
AE3 | 1 | Antenna_Loop | Snapeda:NFC_Loop_40x30_3T | Loop antenna
C1,C3,C8,C11,C22,C23,C24,C25,C28,C29,C30,C34 | 12 | 100n | Capacitor_SMD:C_0805_2012Metric | Unpolarized capacitor
C2,C35 | 2 | 4.7u | Capacitor_SMD:C_0805_2012Metric | Unpolarized capacitor
C4 | 1 | 10n | Capacitor_SMD:C_0805_2012Metric | Unpolarized capacitor
C5,C33 | 2 | 1u | Capacitor_SMD:C_0805_2012Metric | Unpolarized capacitor
C6,C7 | 2 | 4.3p | Capacitor_SMD:C_0805_2012Metric | Unpolarized capacitor
C9,C10 | 2 | 15p | Capacitor_SMD:C_0805_2012Metric | Unpolarized capacitor
C12,C13,C38,C39 | 4 | 150p | Capacitor_SMD:C_0805_2012Metric | Unpolarized capacitor
C15,C37 | 2 | 10p | Capacitor_SMD:C_0805_2012Metric | Unpolarized capacitor
C16,C17 | 2 | 68p | Capacitor_SMD:C_0805_2012Metric | Unpolarized capacitor
C18,C19 | 2 | 270p | Capacitor_SMD:C_0805_2012Metric | Unpolarized capacitor
C20,C21,C36 | 3 | 10u | Capacitor_SMD:C_0805_2012Metric | Unpolarized capacitor
C26,C27,C31,C32 | 4 | 2.2u | Capacitor_SMD:C_0805_2012Metric | Unpolarized capacitor
D1,D5 | 2 | RED | LED_SMD:LED_0805_2012Metric | Light emitting diode
D2,D3,D6 | 3 | GREEN | LED_SMD:LED_0805_2012Metric | Light emitting diode
D4 | 1 | SS14 | Diode_SMD:D_SMA | 40V 1A Schottky Diode, SMA
FB1,FB2 | 2 | 600R@100MHz | Inductor_SMD:L_0402_1005Metric | Ferrite bead
J1 | 1 | USB-C | Connector_USB:USB_C_Receptacle_GCT_USB4110 | USB 2.0-only 16P Type-C Receptacle connector
J2 | 1 | BATTERY | Connector_JST:JST_XA_B02B-XASK-1_1x02_P2.50mm_Vertical | Generic connector, single row, 01x02, script generated
J3 | 1 | SWD | Connector_PinHeader_2.54mm:PinHeader_1x04_P2.54mm_Vertical | Generic connector, single row, 01x04, script generated
J4 | 1 | VIB_MOTOR | Connector_PinHeader_2.54mm:PinHeader_1x02_P2.54mm_Vertical | Generic connector, single row, 01x02, script generated
J5 | 1 | CSO | Connector_Wire:SolderWirePad_1x01_SMD_1x2mm | Generic connector, single row, 01x01, script generated
J6 | 1 | CSI | Connector_Wire:SolderWirePad_1x01_SMD_1x2mm | Generic connector, single row, 01x01, script generated
J7 | 1 | PN532 | Connector_PinSocket_2.54mm:PinSocket_1x08_P2.54mm_Vertical | Backup NFC reader: PN532 breakout (Elechouse V3 pinout, DIP switches set to SPI)
L3,L4 | 2 | 470nH | Inductor_SMD:L_0805_2012Metric_Pad1.05x1.20mm_HandSolder | Inductor
Q1 | 1 | AO3400A | Package_TO_SOT_SMD:SOT-23 | 30V Vds, 5.7A Id, N-Channel MOSFET, SOT-23
R1,R2 | 2 | 5.1k | Resistor_SMD:R_0805_2012Metric | Resistor
R3,R4,R5,R9,R10 | 5 | 470R | Resistor_SMD:R_0805_2012Metric | Resistor
R6 | 1 | 1k | Resistor_SMD:R_0805_2012Metric | Resistor
R7,R8,R11,R12,R20 | 5 | 10k | Resistor_SMD:R_0805_2012Metric | Resistor
R15 | 1 | 1.5k | Resistor_SMD:R_0805_2012Metric | Resistor
R16,R18,R19 | 3 | 4.7M | Resistor_SMD:R_0805_2012Metric | Resistor
R17 | 1 | 2.7M | Resistor_SMD:R_0805_2012Metric | Resistor
R21,R22 | 2 | 0 | Resistor_SMD:R_0805_2012Metric | Resistor
SW1 | 1 | RST | Button_Switch_SMD:SW_Tactile_SPST_NO_Straight_CK_PTS636Sx25SMTRLFS | Push button switch, generic, two pins
SW2 | 1 | BOOT0 | Button_Switch_SMD:SW_Tactile_SPST_NO_Straight_CK_PTS636Sx25SMTRLFS | Push button switch, generic, two pins
SW3 | 1 | POWER | Button_Switch_SMD:SW_Tactile_SPST_NO_Straight_CK_PTS636Sx25SMTRLFS | Push button switch, generic, two pins
TH1 | 1 | 10k NTC | Resistor_THT:R_Axial_DIN0204_L3.6mm_D1.6mm_P1.90mm_Vertical | Temperature dependent resistor, negative temperature coefficient
U1 | 1 | STM32L432KBUx | Package_DFN_QFN:QFN-32-1EP_5x5mm_P0.5mm_EP3.45x3.45mm | STMicroelectronics Arm Cortex-M4 MCU, 128KB flash, 64KB RAM, 80 MHz, 1.71-3.6V, 26 GPIO, UFQFPN32
U2 | 1 | MCP73833-xxx-UN | Package_SO:MSOP-10_3x3mm_P0.5mm | Stand-Alone Linear Li-Ion / Li-Polymer Charge Management Controller, MSOP-10
U3 | 1 | TPS7A0233PDBVR | External:SOT23_DBV_TEX-L
U5 | 1 | ST25R3916-AQWT | External:QFN50P500X500X100-33N | RFID, READ/WRITE, 13.56MHZ, VFQFPN-32; Frequency Min:-; Frequency Max:13.56MHz; RFID IC Type:Read, Write; Programmable Memory:-; Output Power:1.6W; RF IC Case Style:VFQFPN; No. of Pins:32Pins; Supply Voltage Min:2.4V; Supply Voltage Max:5.5V; Current Consumption:-; Product Range:-; MSL:MSL 3 - 168 hours; SVHC:No SVHC (27-Jun-2018)
U6 | 1 | USBLC6-2SC6 | Package_TO_SOT_SMD:SOT-23-6 | USB ESD protection, 2 data lines + VBUS, SOT-23-6
Y1 | 1 | 27.12MHz | Crystal:Crystal_SMD_3225-4Pin_3.2x2.5mm_HandSoldering | Four pin crystal, GND on pins 2 and 4
Y2 | 1 | 32.768k | Crystal:Crystal_SMD_EuroQuartz_EQ161-2Pin_3.2x1.5mm | Two pin crystal

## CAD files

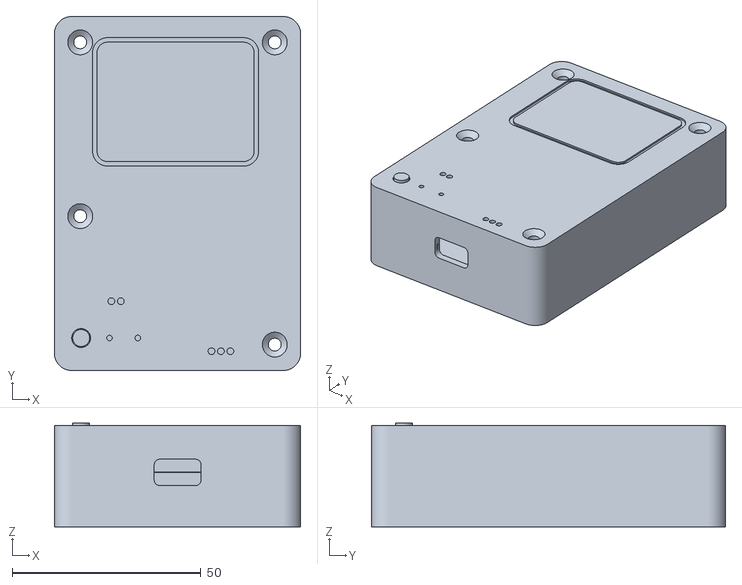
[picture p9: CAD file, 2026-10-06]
Enclosure/stl/assembly.stl
65.2 x 93.7 x 27.5

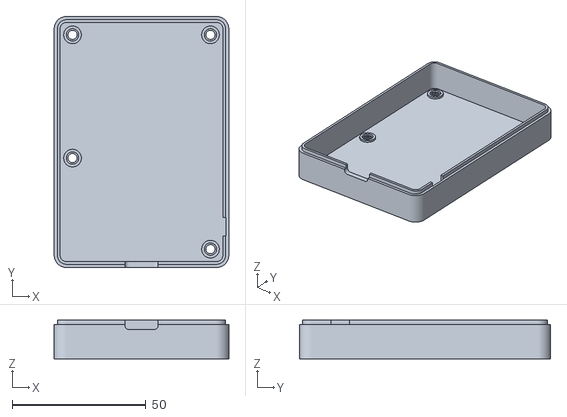
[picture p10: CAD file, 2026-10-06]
Enclosure/stl/base.stl
65.2 x 93.7 x 14.4

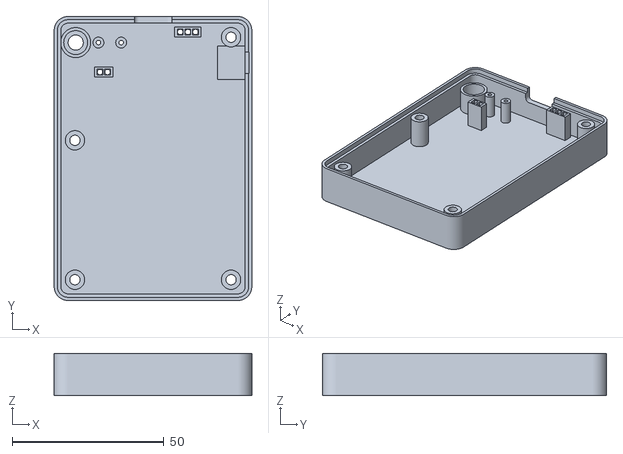
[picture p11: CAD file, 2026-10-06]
Enclosure/stl/lid.stl
65.2 x 93.7 x 14.0

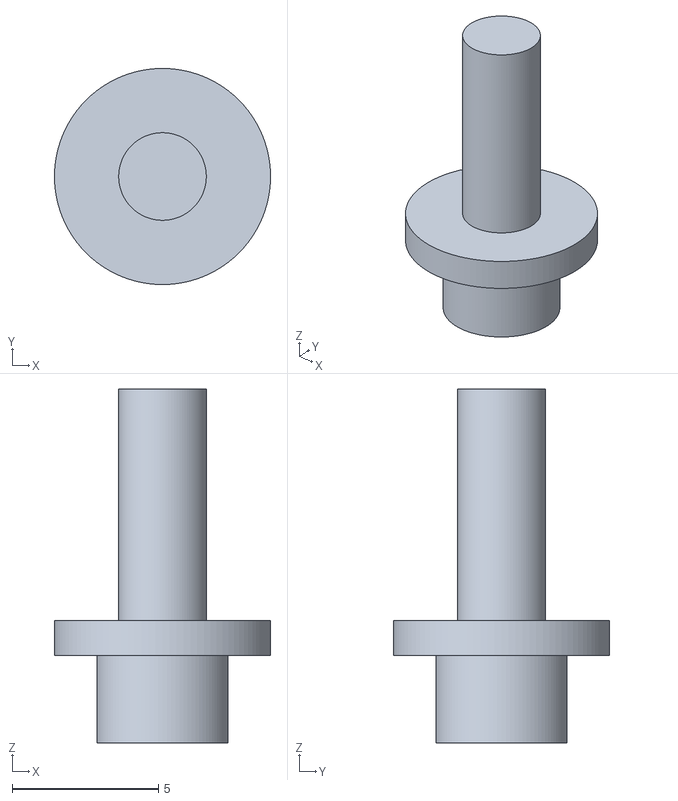
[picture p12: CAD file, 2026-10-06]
Enclosure/stl/button.stl
7.40 x 7.40 x 12.1

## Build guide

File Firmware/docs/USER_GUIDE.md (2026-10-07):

# Card Attendance System: user guide

Written for: the people who run a class with the device, not the firmware team.

The device logs a card tap with the date and time, and shows its log to a
computer as a small USB drive. It records only the card number and the time: it
does not know who owns a card, or which cards are registered. For the easiest
way to use it, run the companion app in the `Companion` folder (see its README):
it keeps the student list, registers cards, finds the device, starts lectures,
shows who was present and prints reports. This guide describes the device
itself, which also works with no app at all, by opening the files on the drive.

## Taking attendance

Tap a card on the reader. The device answers:

| You see | It means |
|---|---|
| green light and one short buzz | the tap is recorded |
| two short buzzes | this card is already recorded in this lecture (or was read twice in a row); not recorded again |
| green light and three quick buzzes | a new lecture has started (you held the button, see below) |
| red light blinking five times | the battery is low |
| red light blinking fast without stopping, no buzz, nothing else works | the device could not start (most often its clock crystal). Unplug the USB cable and disconnect the battery for a few seconds, then try again; if it keeps happening, the board needs looking at |
| red light and four buzzes | the device's memory is full and the tap was not recorded (or, at switch-on, its reader did not start) |

Every card is recorded, registered or not: the device keeps no list of students
and shows green for every new tap. Who the card belongs to is worked out later,
on the computer.

While the device is plugged into a computer as a USB drive, a tap is **not**
recorded. It gives the same green light and buzz, and the card's number is shown
to the computer so the companion app can register the card (see
[Registering a new card](#registering-a-new-card)).

On battery, after three minutes without a tap the device switches itself off.
Press the power button to wake it (green light and a short buzz). While its
cable is in (a computer or a charger) it stays on.

The power button also does three other things while the device is on:

| Press | Result |
|---|---|
| tap | shows the battery: two green blinks if it is fine, red blinking five times if it is low. While it is a USB drive on a computer, a tap first ends that and starts taking attendance (see below) |
| two quick taps, with the cable in after an eject | brings the drive back to the computer, so the app can read the device again |
| hold until it buzzes (2 seconds), then let go | **starts the next lecture** (green and three quick buzzes). See [Starting a lecture on the device](#starting-a-lecture-on-the-device) |
| keep holding for 5 seconds | switches the device off (red light and a long buzz) instead; no lecture is started. Any changes you made to `SETTINGS.CSV` are applied first |

## Taking attendance with the cable in

When the device is plugged into a computer it shows up as a USB drive. Its
reader stays on, but only for registering cards: taps are not recorded while the
drive is there. To start taking attendance without pulling the cable, either:

- **eject the drive** on the computer (Eject in Explorer, Finder or the file
  manager; the companion app does this for you when you start a lecture), or
- **tap the button** on the device once.

The device applies your `SETTINGS.CSV` (green and two buzzes, or red and three
if the file was refused), the drive disappears from the computer, and taps are
recorded again. The cable can stay in: the device runs and charges from it. To
see the drive again, press the button twice quickly (or unplug the cable and
plug it back in); the app's **Connect** button reminds you. While the drive is
back on the computer, taps are for registering cards, not attendance, so eject
it again before the class taps in.

On a phone charger or power bank there is no drive: the device waits about five
seconds for a computer, then takes attendance as usual. A card held to it in
those first seconds is read once the wait is over; one taken away sooner gets
no light at all, so just tap it again.

## Lectures and double taps

A **lecture** is a module name and a lecture name, for example `EN2090` and
`Lecture 4`. Every card tapped after you start one is recorded after that
lecture's marker in the log, which is how the computer knows which lecture it
belongs to. Start one from the app (Lectures page), or by editing the `#MODULE` and
`#LECTURE` lines in `SETTINGS.CSV` and ejecting the drive (or tapping the button,
or unplugging). Edit them to the same text as
before and add a line `#NEWSESSION,1` to start a second lecture with the same
names.

### Starting a lecture on the device

You can take attendance for several lectures in a row without a computer.
When one lecture ends and the next begins, **hold the power button until you
feel a buzz (2 seconds), then let go.** The device answers with a green light and
three quick buzzes, and every card counts again from that moment.

The new lecture keeps the module of the one before and counts its name on:
`Circuits Lecture 4` becomes `Circuits Lecture 5`, then `Circuits Lecture 6`. A
name without a number gets ` 2`, ` 3` and so on, and if no lecture was ever set
the first one is `Lecture 1` with no module. The next time you plug the device
in, the companion app adds each of these lectures with the taps that belong to
it; rename one there if the automatic name is not right. A lecture without a
module is filed under **UNASSIGNED** until you move it.

Keep holding past the buzz and the device switches off instead (at 5 seconds),
without starting a lecture. A hold while the device is a USB drive on a computer
only ends the drive session, like a tap; hold again once it is taking attendance.

### Double taps

Within one lecture a card counts **once**. A student who taps twice by accident,
holds the card on the reader, or comes back to the reader later gets a double
buzz and no second row, even if the device has gone to sleep in between. Start
the next lecture and everyone counts again. If you never start a lecture, a card
already recorded in the last six hours still counts once.

## Deleting the records

Starting a lecture from the companion app also empties the device. The app first
reads every tap on the device into its own database, checks that it got all of
them, and only then tells the device to delete its copy (the `#CLEARLOG,1` line
in `SETTINGS.CSV`). The old taps stay in the app, matched to their lectures. If
the app could not read every tap it does not ask, and the device keeps them.

**Clear device records** in the app does the same without starting a lecture:
it reads everything in first, and refuses to clear the device if it could not.

If the device's records cannot be read at all, **Erase device without saving…**
(in the app's Device menu) deletes them without copying them first.
You have to type `ERASE` to confirm. Any taps and lectures that were not already
in the app are lost for good. The device keeps its ID and its clock.

Without the app, add a line `#CLEARLOG,1` to `SETTINGS.CSV` and eject. **Copy
`ATTEND.CSV`, `LECTURES.CSV` and the `LECTURES` folder somewhere safe first:**
the records cannot be brought back. Renaming the lecture by hand never deletes anything.

## Reading the attendance

1. Plug the device into a computer with the USB-C cable.
2. A drive called **ATTENDANCE** appears. Open `ATTEND.CSV` (it opens in Excel,
   Numbers, Google Sheets or any text editor).

```
DATE,TIME,CARD_ID
2026-10-06,09:30:12,0000123456
2026-10-06,09:30:40,0000999999
```

Copy the file somewhere else to keep it. The drive itself is read-only for this
file, so you cannot damage the log by accident. The header row has spaces after
it to keep every row the same width; most programs ignore this, and a script
should strip them. The file holds only taps: the lecture markers are not rows,
and there are no names. To see names and per-lecture attendance, use the
companion app, which matches the card numbers to your student list.

`LECTURES.CSV`, also read-only, lists every lecture start in the log, one row
each: date, time, module and lecture name, for example
`2026-10-07,14:00:03,EN2090,Circuits Lecture 5`. The rows are padded with spaces
like `ATTEND.CSV`. A tap belongs to the last lecture that started before it.

The `LECTURES` folder holds the same taps split up, one read-only file per
lecture, with the same columns as `ATTEND.CSV`:

```
LECTURES
  L000_2026-10-06_09-12.csv    taps from before the first lecture, if there were any
  L001_2026-10-06_14-00.csv    lecture 1, started 2026-10-06 at 14:00
  L002_2026-10-07_14-00.csv
```

The name is the lecture's number on the device, then the date and time it
started (some older programs show only the short name, such as `L001.CSV`).
`L000` is named after its first tap. The numbers start from 1 again after the
records are deleted. To see the lecture's module and name, look up its row in
`LECTURES.CSV`.

`STATUS.TXT` on the drive is a short read-only summary: the device ID, the
clock, the battery, how many records the log holds, how many files the
`LECTURES` folder has, the last tap, the current lecture and when it started,
and what the device will do with your `SETTINGS.CSV` when you eject the drive.
The battery reads like `87 % (3950 mV)`; it reads a little high while the
device is charging, which it is whenever it is plugged in. The companion app
shows the same figure at the top of its window.

`LASTCARD.TXT` shows the card last tapped since the device was plugged in, for
registering cards (see below). The companion app reads it for you.

## Changing the device's settings

1. Plug the device in and open the **ATTENDANCE** drive.
2. Open `SETTINGS.CSV` in a text editor. It is a few lines, each starting with `#`:

   ```
   # Edit these lines, then eject the drive (or press the button). Add #NEWSESSION,1 to start another lecture with the same names.
   #TIME,2026-10-06 14:30:00
   #MODULE,EN2090
   #LECTURE,Circuits Lecture 4
   #DEVICE,0000012345
   ```

3. Change what you need and save, keeping the name `SETTINGS.CSV`. Or replace
   the whole file with your own, saved under exactly that name: a file with any
   other name is ignored. Use a plain text editor (Notepad, TextEdit in plain
   text mode); spreadsheet programs can change the `#TIME` format or the
   encoding, and the device then ignores those lines.
4. **Eject the drive** (or tap the button on the device, or unplug the cable).
   The device checks the file, then shows the result:
   - green light and two buzzes: accepted and applied
   - red light and three buzzes: refused, and nothing was changed

What each line does:

| Line | Effect |
|---|---|
| `#TIME,2026-10-06 14:30:00` | sets the clock, if you changed it (an untouched line leaves the clock alone) |
| `#MODULE,...` and `#LECTURE,...` | name the lecture; a new one starts if either changed |
| `#NEWSESSION,1` | starts a new lecture even if the names are the same |
| `#CLEARLOG,1` | deletes every record on the device (copy `ATTEND.CSV` first) |
| `#DEVICE,...` | sets the device ID printed on the enclosure (the line appears once an ID is set) |

Safe to know:

- Nothing is applied until you eject the drive, tap the button or unplug the
  cable. Save the file first. Holding the power button for 5 seconds while
  plugged in also applies your changes before the device switches off.
- Module names can be up to **24 bytes** and lecture names up to **32 bytes**
  (about that many English letters; fewer for Sinhala or Tamil, which take three
  bytes a letter). A comma inside a name is turned into a space.
- Lines that do not start with `#` are ignored, and so are `#` lines the
  device does not know. That includes the `#CARDS` list an older version of the
  app wrote, with the numbers under it: the device keeps no card list now.
- Read `STATUS.TXT` on the drive to see what the device thinks of your file
  *before* you eject: it says whether the clock, a new lecture, deleting the
  records or a new device ID will be applied, or names the problem. (Your
  computer may show an old copy of `STATUS.TXT` right after you change the file.)

## Setting the clock

The device keeps time while switched off, but it needs setting once, and again
if the battery goes completely flat. Edit the `#TIME` line in `SETTINGS.CSV` to
the current local time, for example `#TIME,2026-10-06 14:30:00`, save, and
eject. (If you leave that line alone the clock is not touched.) The app can do
this for you: it sets the clock whenever you start a lecture, or with **Set the
device clock**.

## Registering a new card

The device does not need to know about a new card: it records every card. The
companion app is where a card is given to a student, and the device can read the
card for it while it is plugged in:

1. Plug the device into the computer and open the companion app.
2. On the **Students** page press **Tap a card…** (or, in a student's window,
   **Tap card on device…**).
3. Tap the card on the device. It shows a green light and buzzes, and the card's
   number appears in the app. The tap is not recorded as attendance.
4. Fill in the index number and name, and save.

With a student picked in the list first, **Tap a card…** gives that student the
new card instead (a lost or replaced card). A card that already belongs to
another student is refused, and the app waits for another one. When you are
done, eject the drive (or tap the button) and the device takes attendance again.

A card can also be registered afterwards: tap it with the device unplugged (it
is recorded like any other), plug the device in, and press **Register…** next to
it in the orange *New cards* box on the Students page.

Without the app there is nothing to register on the device. Find the card's
number in the `CARD_ID` column of `ATTEND.CSV`, or tap it while the device is
plugged in and open `LASTCARD.TXT` (your computer may show an old copy of that
file; close it and open it again), and keep your own list of who owns it.

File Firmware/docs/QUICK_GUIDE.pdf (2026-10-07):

# Attendance Logger: Quick Guide

For lecturers and staff who take attendance with the card reader.
Students tap their ID card on the reader. The device stores the card number and time, and answers with a light and a buzz. The companion app on the computer later shows who attended each lecture.

## Taking attendance in four steps

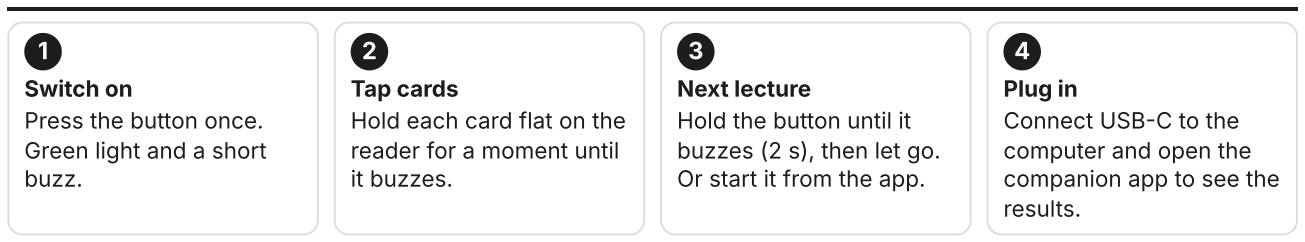
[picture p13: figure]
Switch on Press the button once. Green light and a short buzz.; Tap cards Hold each card flat on the reader for a moment until it buzzes.; Next lecture Hold the button until it buzzes (2 s), then let go. Or start it from the app.; Plug in Connect USB-C to the computer and open the companion app to see the results.

## What the lights and buzzes mean

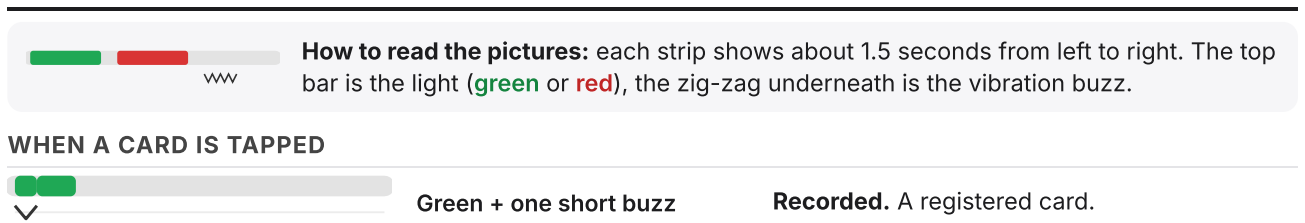
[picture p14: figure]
WHEN A CARD IS TAPPED; Green + one short buzz; Recorded. A registered card.

How to read the pictures: each strip shows about 1.5 seconds from left to right. The top bar is the light (green or red), the zig-zag underneath is the vibration buzz.

Red + one long buzz

Recorded, but the card is not registered. Register it in the companion app (see page 2). The tap is kept.

Green + two quick buzzes

Already recorded in this lecture. Not counted again.
Nothing to do. The student is already marked present.

Red flashing 4 times, buzzing

Not recorded: the memory is full.
Plug into the computer and start a lecture from the app (this empties the device).
Green + short buzz | Switched on and ready for cards.
| Battery is fine (after a quick tap of the
A buzz while you hold, no | 2 seconds reached. Let go now to start a new

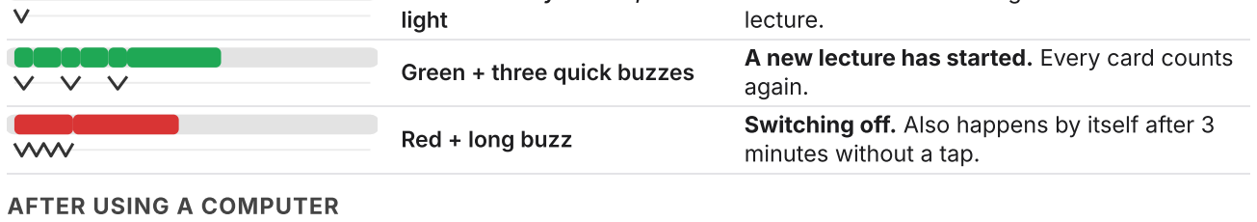
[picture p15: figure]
light; lecture.; Green + three quick buzzes; again.; Red + long buzz; minutes without a tap.; AFTER USING A COMPUTER

| A new lecture has started. Every card counts
| Switching off. Also happens by itself after 3

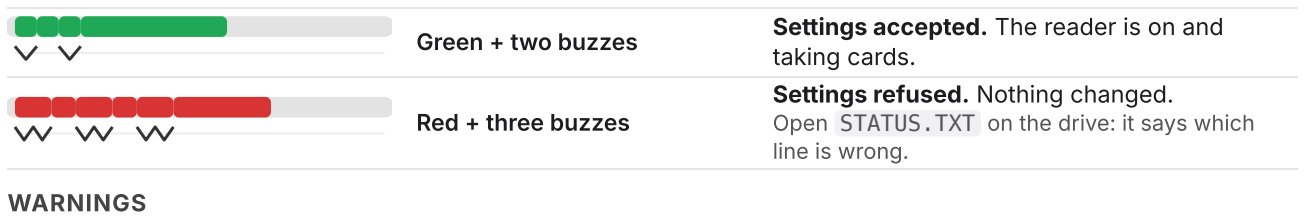
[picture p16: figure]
Green + two buzzes; Settings accepted. The reader is on and taking cards.; Red + three buzzes; Settings refused. Nothing changed.; line is wrong.; WARNINGS

Open STATUS.TXT on the drive: it says which

Red blinking 5 times, no buzz

Battery low. If it was already very low the device then switches off.
Charge it with the USB-C cable.

Red flashing 4 times +
buzzes, at switch-on

The card reader did not start.
Switch off (hold 5 s) and on again. If it repeats, get it serviced.

## The power button

WHAT YOU DO | WHAT HAPPENS
Press once (device off) | Switches on: green light and a short buzz.
Quick tap (device on) | Shows the battery: two green blinks = fine, red blinking 5 times = low. While the device is a USB drive on a computer, a tap ends that and starts taking cards instead.
Hold 2 s until it buzzes, then let go | Starts the next lecture (green + three quick buzzes). It keeps the module name and counts the lecture on: Lecture 4 becomes Lecture 5.
Keep holding for 5 s | Switches off (red + long buzz). No lecture is started.

On battery the device switches itself off after 3 minutes without a tap. Press the button to wake it. Your records are safe: they are kept when it switches off.

## Lectures and double taps

Each student counts once per lecture, even if the device slept in between. A second tap gets two quick buzzes.
When one lecture ends and the next begins, start a new lecture (hold the button 2 s, or use the app). Then everyone counts again.
If you never start a lecture, a card already recorded in the last 6 hours still counts only once.

## Using it with the computer

1. Plug the device in with the USB-C cable. A drive called ATTENDANCE appears. The reader is off while it is a drive.
2. Open the companion app. It reads the taps and shows attendance for each lecture.
3. To start a lecture, use the Lecture tab in the app. It saves all taps, empties the device, sets the clock and ejects the drive.
4. The device answers green + two buzzes and starts taking cards. The cable can stay in: it charges while it works.
Without the app: eject the drive, or tap the button once, to switch the reader back on.

## Registering a new student card

1. Tap the new card on the device. It shows red with a long buzz, but the tap is recorded.
2. Plug the device in and open the app. The card appears under New cards on the Students tab.
3. Press Register and fill in the student's details.
4. Press Send cards to device, then eject. Green + two buzzes means it was stored.
From then on that card shows green.

## Charging

Charge with any USB-C charger or computer port. It keeps taking cards while it charges.
The clock keeps running while the device is off. If the battery ever goes completely flat, set the clock again (the app does it when you start a lecture).

## If something is not right

PROBLEM | WHAT TO DO
Nothing happens when a card is tapped | Press the button: the device may have switched itself off. If it is plugged into a computer, the reader is off; eject the drive or tap the button.
Card does not read | Hold the card flat and still on the reader for about a second. Keep it away from phones and other cards in the same wallet.
Every tap shows red | The device does not have the latest card list. Press Send cards to device in the app.
The battery runs low quickly | Charge it fully with the USB-C cable. A tap of the button shows the battery: two green blinks = fine.
Times in the records are wrong | Set the clock: start a lecture from the app, or use Set the device clock.

Attendance Logger, firmware quick guide. Full details: Firmware/docs/USER_GUIDE.md and Companion/README.md .

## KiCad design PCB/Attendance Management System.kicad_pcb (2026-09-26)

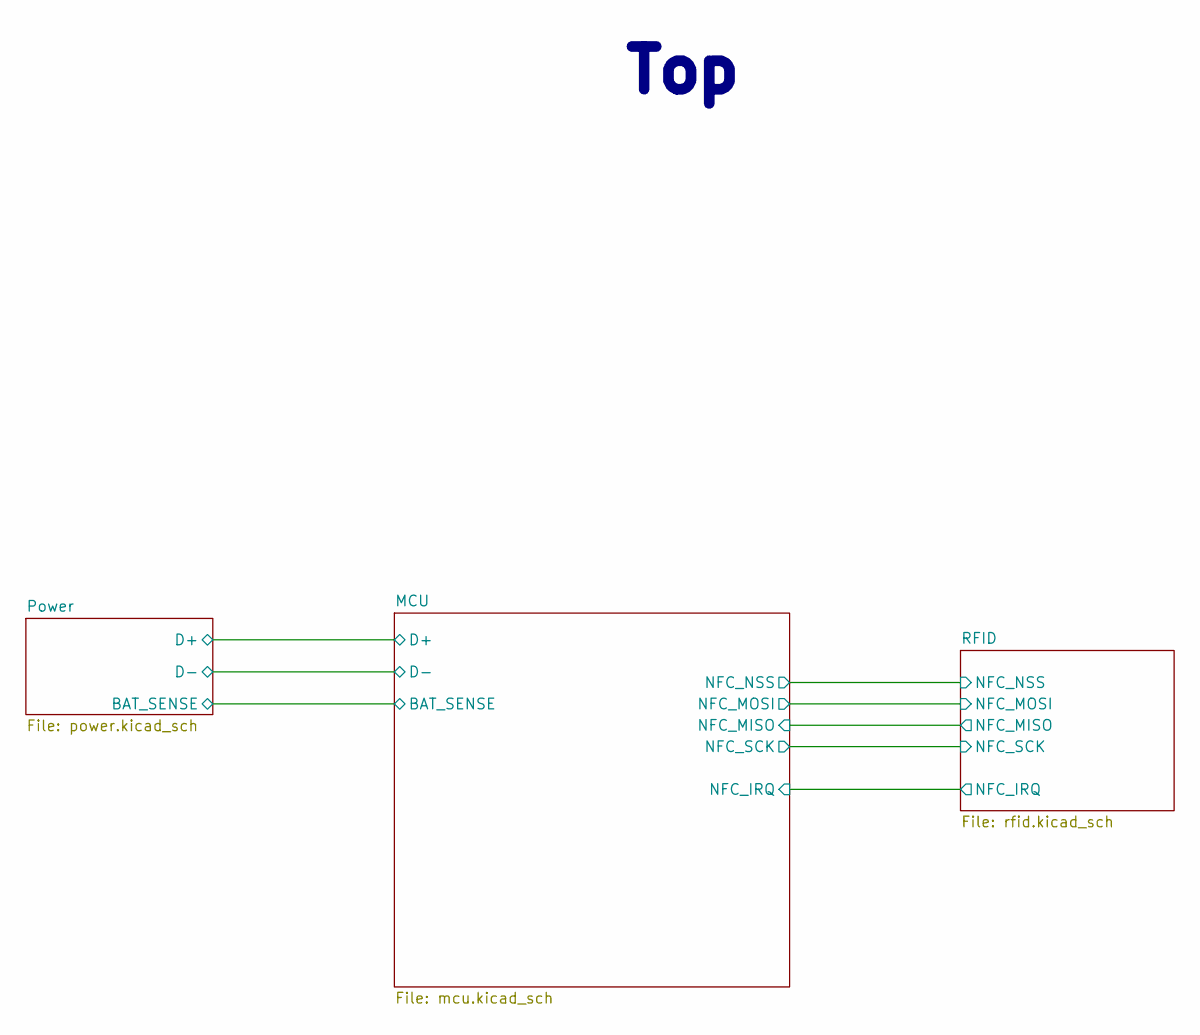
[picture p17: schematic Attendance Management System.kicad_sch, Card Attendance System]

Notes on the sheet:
Top

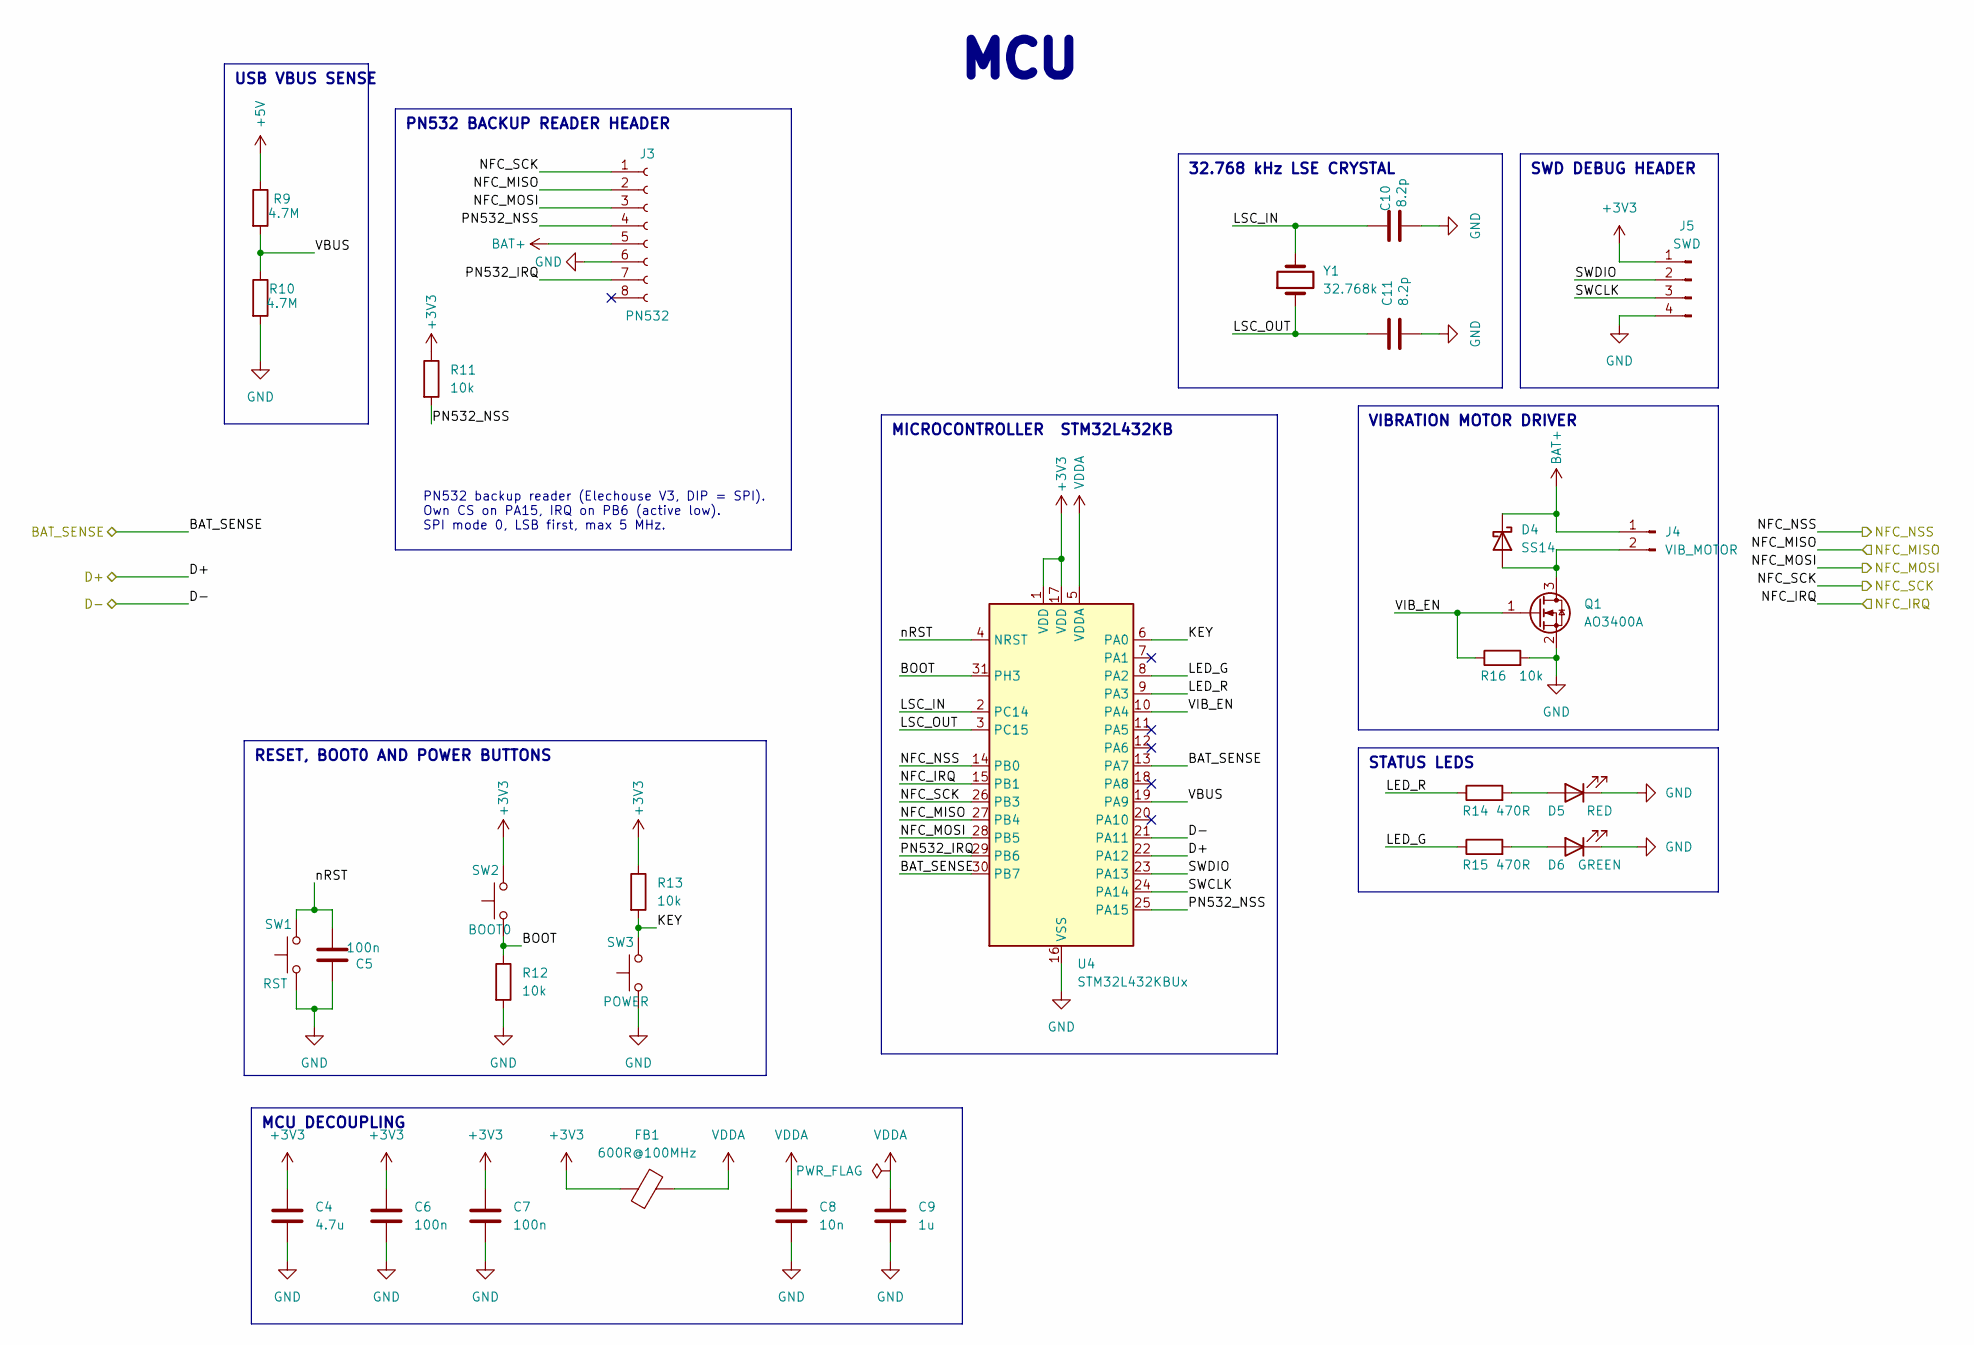
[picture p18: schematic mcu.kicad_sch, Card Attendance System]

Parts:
C4: 4.7u; C_0805_2012Metric; Voltage 10V; LCSC C1779
C5, C6, C7: 100n; C_0805_2012Metric; Voltage 16V; LCSC C49678
C8: 10n; C_0805_2012Metric; Voltage 16V; LCSC C1710
C9: 1u; C_0805_2012Metric; Voltage 10V; LCSC C28323
C10, C11: 8.2p; C_0805_2012Metric; Voltage 50V; LCSC C1840
D4: SS14; D_SMA; LCSC C2480
D5: RED; LED_0805_2012Metric; LCSC C84256
D6: GREEN; LED_0805_2012Metric; LCSC C98221
FB1: 600R@100MHz; L_0402_1005Metric; LCSC C76884
J3: PN532; PinSocket_1x08_P2.54mm_Vertical; LCSC C42431840
J4: VIB_MOTOR; PinHeader_1x02_P2.54mm_Vertical; LCSC C492401
J5: SWD; PinHeader_1x04_P2.54mm_Vertical; LCSC C2691448
Q1: AO3400A; SOT-23; LCSC C20917
R9, R10: 4.7M; R_0805_2012Metric; LCSC C17674
R11, R12, R13, R16: 10k; R_0805_2012Metric; LCSC C17414
R14, R15: 470R; R_0805_2012Metric; LCSC C17710
SW1: RST; SW_Tactile_SPST_NO_Straight_CK_PTS636Sx25SMTRLFS; LCSC C2689642
SW2: BOOT0; SW_Tactile_SPST_NO_Straight_CK_PTS636Sx25SMTRLFS; LCSC C2689642
SW3: POWER; SW_Tactile_SPST_NO_Straight_CK_PTS636Sx25SMTRLFS; LCSC C2689642
U4: STM32L432KBUx; QFN-32-1EP_5x5mm_P0.5mm_EP3.45x3.45mm; LCSC C2928224
Y1: 32.768k; Crystal_SMD_EuroQuartz_EQ161-2Pin_3.2x1.5mm; LCSC C95361

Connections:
+3V3: C4.1, C6.1, C7.1, FB1.1, J5.1, R11.1, R13.1, SW2.2, U4.1 (VDD), U4.17 (VDD); also elsewhere on the board
+5V: R9.1; also elsewhere on the board
/MCU/BAT_SENSE: U4.13 (PA7), U4.30 (PB7); also elsewhere on the board
/MCU/BOOT: R12.1, SW2.1, U4.31 (PH3)
/MCU/D+: U4.22 (PA12); also elsewhere on the board
/MCU/D-: U4.21 (PA11); also elsewhere on the board
/MCU/KEY: R13.2, SW3.2, U4.6 (PA0)
/MCU/LED_G: R15.1, U4.8 (PA2)
/MCU/LED_R: R14.1, U4.9 (PA3)
/MCU/LSC_IN: C10.2, U4.2 (PC14), Y1.2
/MCU/LSC_OUT: C11.1, U4.3 (PC15), Y1.1
/MCU/NFC_IRQ: U4.15 (PB1); also elsewhere on the board
/MCU/NFC_MISO: J3.2, U4.27 (PB4); also elsewhere on the board
/MCU/NFC_MOSI: J3.3, U4.28 (PB5); also elsewhere on the board
/MCU/NFC_NSS: U4.14 (PB0); also elsewhere on the board
/MCU/NFC_SCK: J3.1, U4.26 (PB3); also elsewhere on the board
/MCU/PN532_IRQ: J3.7, U4.29 (PB6)
/MCU/PN532_NSS: J3.4, R11.2, U4.25 (PA15)
/MCU/SWCLK: J5.3, U4.24 (PA14)
/MCU/SWDIO: J5.2, U4.23 (PA13)
/MCU/VBUS: R9.2, R10.1, U4.19 (PA9)
/MCU/VIB_EN: Q1.1 (G), R16.1, U4.10 (PA4)
/MCU/nRST: C5.1, SW1.2, U4.4 (NRST)
BAT+: D4.1 (K), J3.5, J4.1; also elsewhere on the board
GND: C4.2, C5.2, C6.2, C7.2, C8.2, C9.2, C10.1, C11.2, D5.1 (K), D6.1 (K), J3.6, J5.4, Q1.2 (S), R10.2, R12.2, R16.2, SW1.1, SW3.1, U4.16 (VSS), U4.32 (VSS), U4.33 (VSS); also elsewhere on the board
unnamed: D4.2 (A), J4.2, Q1.3 (D)
unnamed: D5.2 (A), R14.2
unnamed: D6.2 (A), R15.2
VDDA: C8.1, C9.1, FB1.2, U4.5 (VDDA)

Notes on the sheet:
PN532 backup reader (Elechouse V3, DIP = SPI). Own CS on PA15, IRQ on PB6 (active low). SPI mode 0, LSB first, max 5 MHz.
SWD DEBUG HEADER
VIBRATION MOTOR DRIVER
RESET, BOOT0 AND POWER BUTTONS
MICROCONTROLLER STM32L432KB
MCU
32.768 kHz LSE CRYSTAL
PN532 BACKUP READER HEADER
USB VBUS SENSE
MCU DECOUPLING
STATUS LEDS

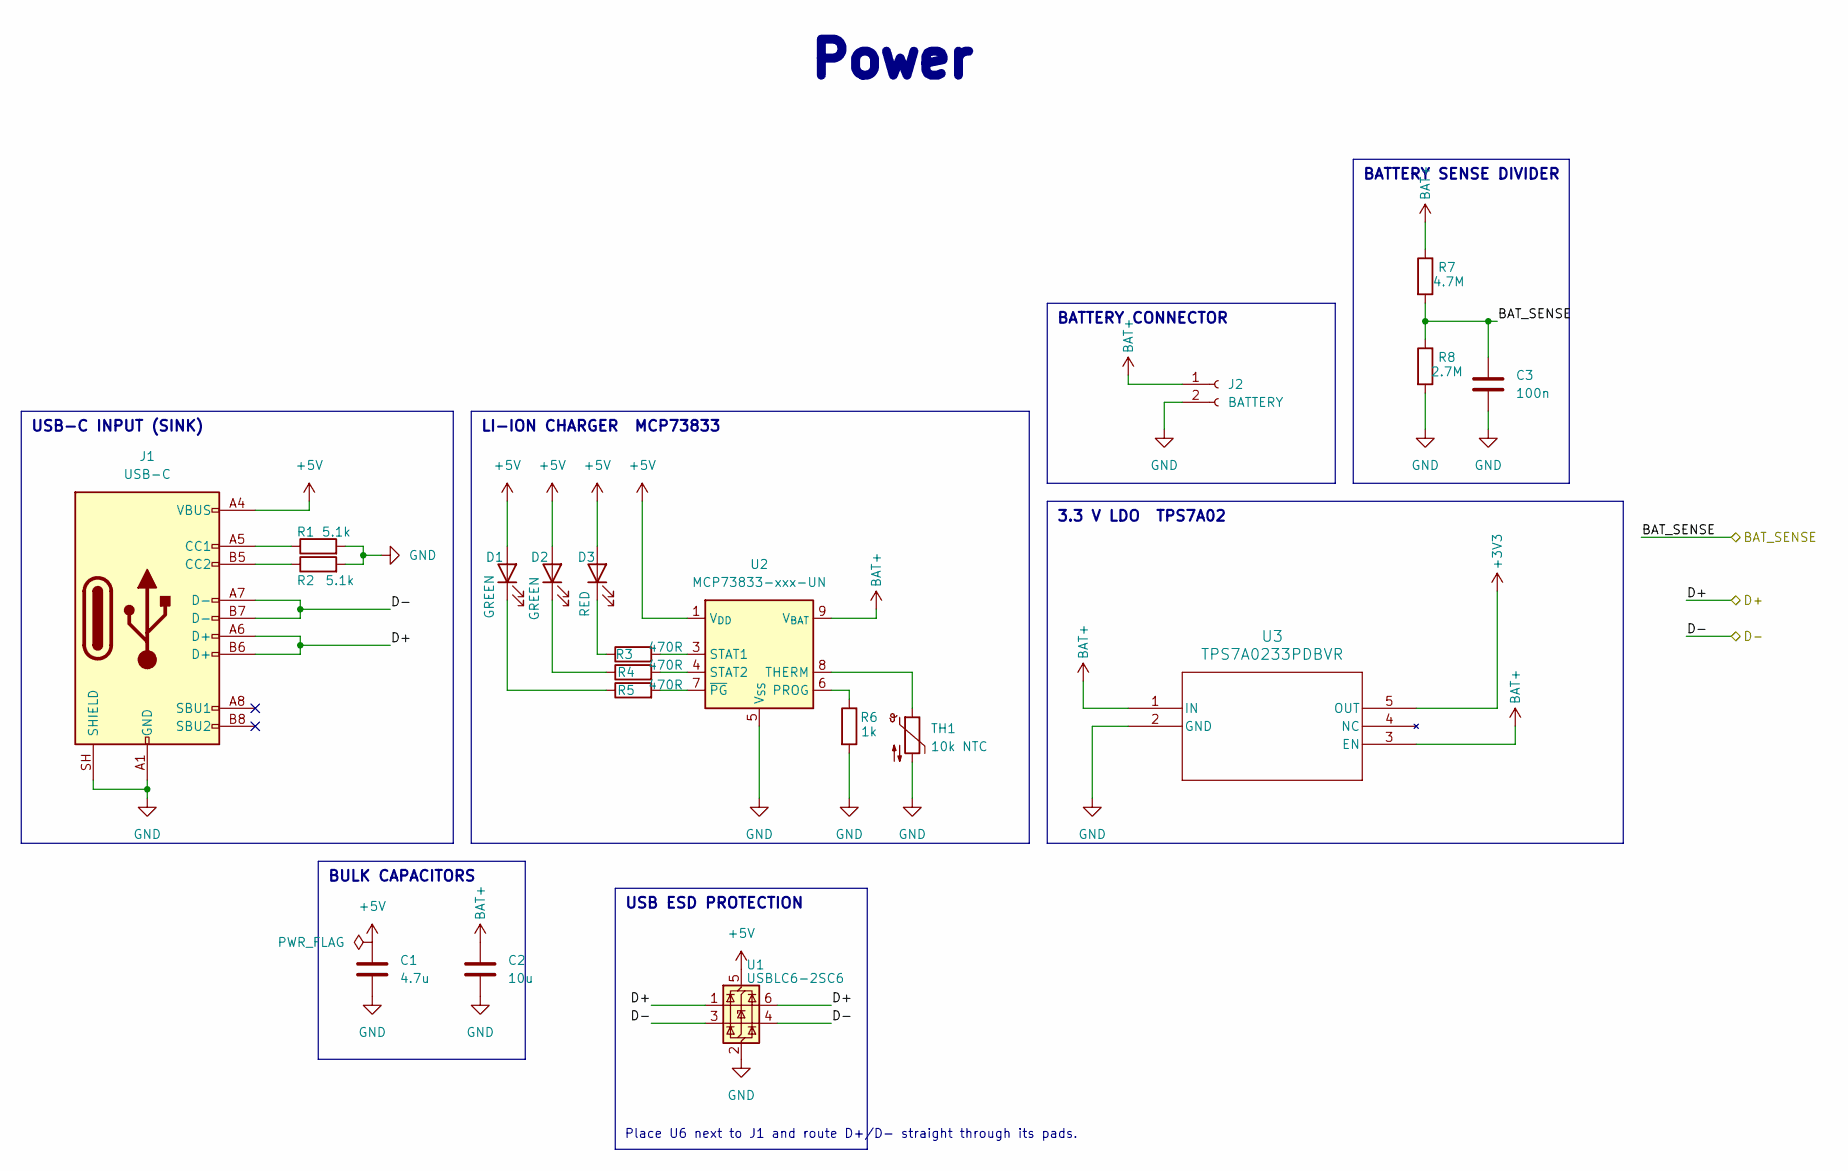
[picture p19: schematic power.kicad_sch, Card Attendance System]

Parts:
C1: 4.7u; C_0805_2012Metric; Voltage 16V; LCSC C1779
C2: 10u; C_0805_2012Metric; Voltage 10V; LCSC C15850
C3: 100n; C_0805_2012Metric; Voltage 16V; LCSC C49678
D1, D2: GREEN; LED_0805_2012Metric; LCSC C98221
D3: RED; LED_0805_2012Metric; LCSC C84256
J1: USB-C; USB_C_Receptacle_GCT_USB4110; LCSC C5143397
J2: BATTERY; JST_XA_B02B-XASK-1_1x02_P2.50mm_Vertical; LCSC C263753
R1, R2: 5.1k; R_0805_2012Metric; LCSC C27834
R3, R4, R5: 470R; R_0805_2012Metric; LCSC C17710
R6: 1k; R_0805_2012Metric; LCSC C17513
R7: 4.7M; R_0805_2012Metric; LCSC C17674
R8: 2.7M; R_0805_2012Metric; LCSC C17531
TH1: 10k NTC; R_Axial_DIN0204_L3.6mm_D1.6mm_P1.90mm_Vertical; LCSC C141588
U1: USBLC6-2SC6; SOT-23-6; LCSC C7519
U2: MCP73833-xxx-UN; MSOP-10_3x3mm_P0.5mm; LCSC C627668
U3: TPS7A0233PDBVR; SOT23_DBV_TEX-L; LCSC C2887324

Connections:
+3V3: U3.5 (OUT); also elsewhere on the board
+5V: C1.1, D1.2 (A), D2.2 (A), D3.2 (A), J1.A4 (VBUS), J1.A9 (VBUS), J1.B4 (VBUS), J1.B9 (VBUS), U1.5 (VBUS), U2.1 (V_{DD}), U2.2 (V_{DD}); also elsewhere on the board
/MCU/BAT_SENSE: C3.1, R7.2, R8.1; also elsewhere on the board
/MCU/D+: J1.A6 (D+), J1.B6 (D+), U1.1 (I/O1), U1.6 (I/O1); also elsewhere on the board
/MCU/D-: J1.A7 (D-), J1.B7 (D-), U1.3 (I/O2), U1.4 (I/O2); also elsewhere on the board
BAT+: C2.1, J2.1, R7.1, U2.9 (V_{BAT}), U2.10 (V_{BAT}), U3.1 (IN), U3.3 (EN); also elsewhere on the board
GND: C1.2, C2.2, C3.2, J1.A1 (GND), J1.A12 (GND), J1.B1 (GND), J1.B12 (GND), J1.SH (SHIELD), J2.2, R1.2, R2.2, R6.2, R8.2, TH1.2, U1.2 (GND), U2.5 (V_{SS}), U3.2 (GND); also elsewhere on the board
unnamed: D1.1 (K), R5.1
unnamed: D2.1 (K), R4.1
unnamed: D3.1 (K), R3.1
unnamed: J1.A5 (CC1), R1.1
unnamed: J1.B5 (CC2), R2.1
unnamed: R6.1, U2.6 (PROG)
unnamed: R3.2, U2.3 (STAT1)
unnamed: R4.2, U2.4 (STAT2)
unnamed: TH1.1, U2.8 (THERM)
unnamed: R5.2, U2.7 (~PG)

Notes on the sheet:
USB-C INPUT (SINK)
LI-ION CHARGER MCP73833
BATTERY CONNECTOR
USB ESD PROTECTION
Power
BATTERY SENSE DIVIDER
3.3 V LDO TPS7A02
BULK CAPACITORS
Place U6 next to J1 and route D+/D- straight through its pads.

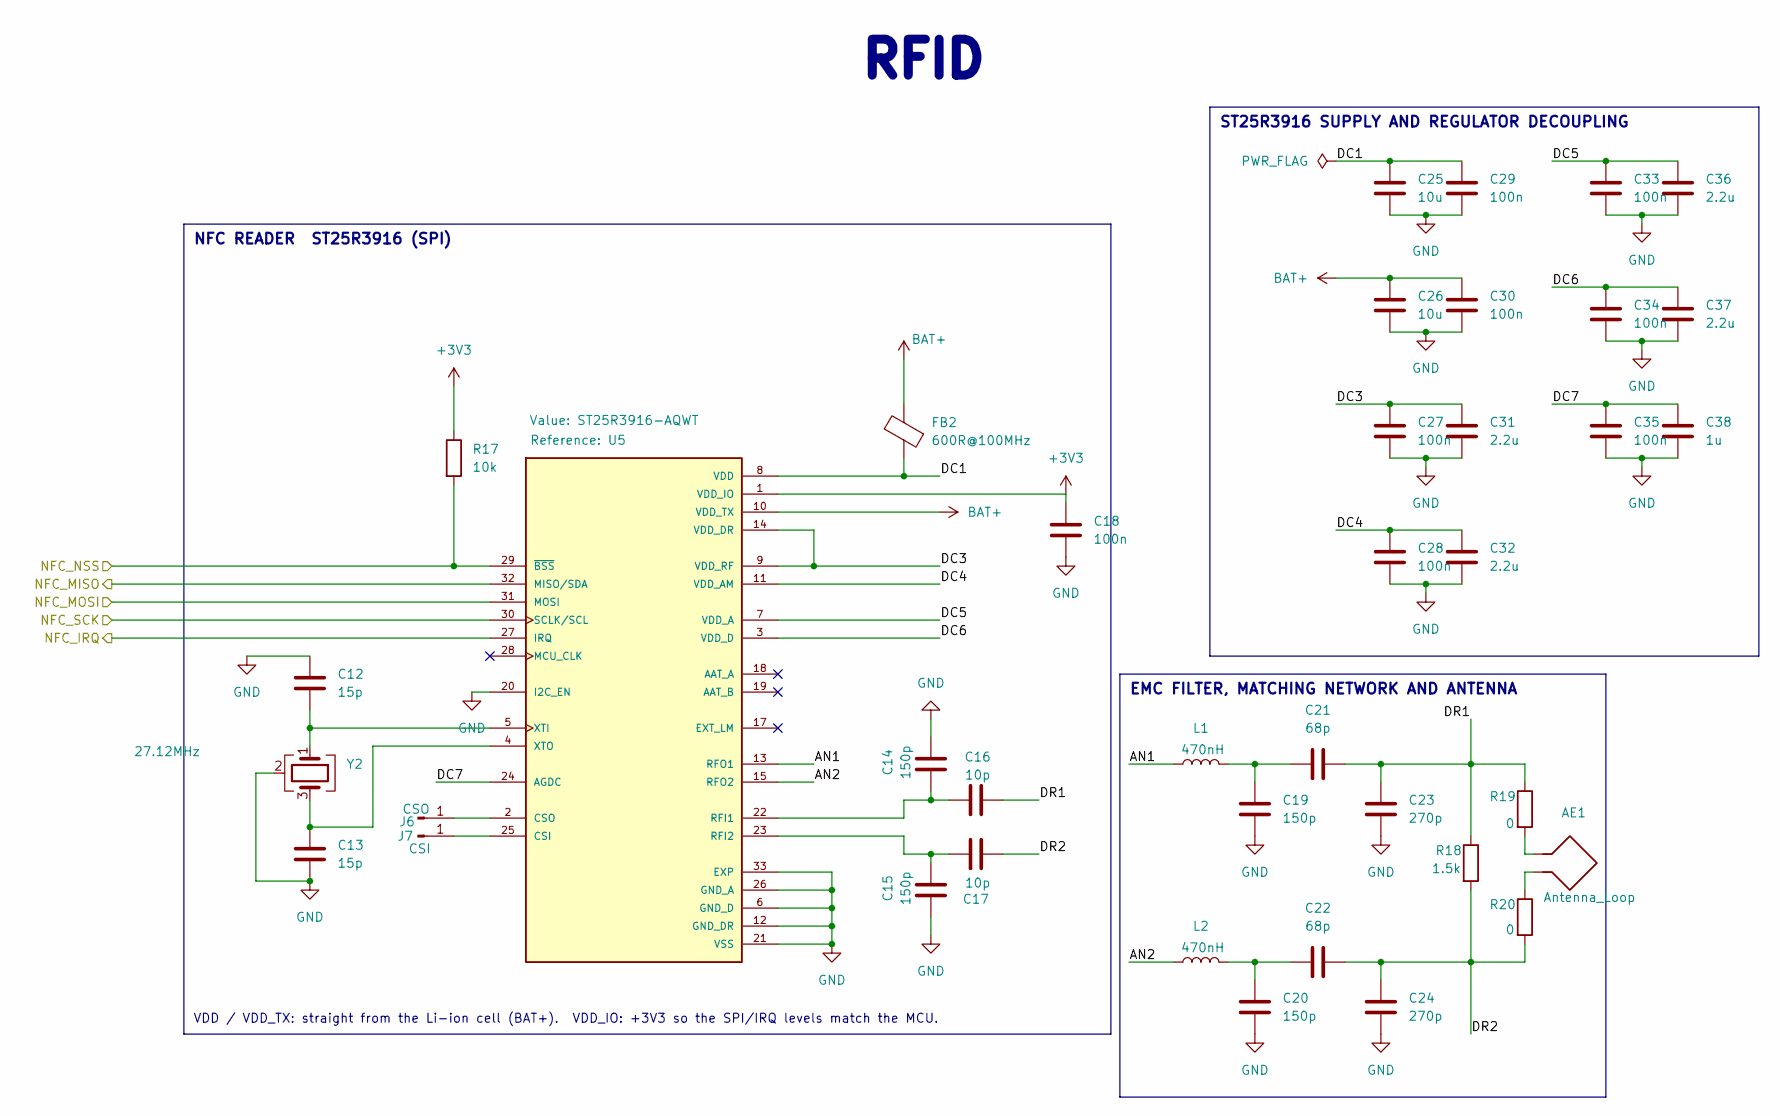
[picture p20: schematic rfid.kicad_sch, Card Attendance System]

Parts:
AE1: Antenna_Loop; NFC_Loop_40x30_3T
C12, C13: 15p; C_0805_2012Metric; Voltage 50V; LCSC C107110
C14, C15, C19, C20: 150p; C_0805_2012Metric; Voltage 50V; LCSC C107111
C16, C17: 10p; C_0805_2012Metric; Voltage 50V; LCSC C107107
C18, C27, C28, C29, C30, C33, C34, C35: 100n; C_0805_2012Metric; Voltage 16V; LCSC C49678
C21, C22: 68p; C_0805_2012Metric; Voltage 50V; LCSC C107120
C23, C24: 270p; C_0805_2012Metric; Voltage 50V; LCSC C107106
C25, C26: 10u; C_0805_2012Metric; Voltage 10V; LCSC C15850
C31, C32, C36, C37: 2.2u; C_0805_2012Metric; Voltage 10V; LCSC C377773
C38: 1u; C_0805_2012Metric; Voltage 10V; LCSC C28323
FB2: 600R@100MHz; L_0402_1005Metric; LCSC C76884
J6: CSO; SolderWirePad_1x01_SMD_1x2mm
J7: CSI; SolderWirePad_1x01_SMD_1x2mm
L1, L2: 470nH; L_0805_2012Metric_Pad1.05x1.20mm_HandSolder; LCSC C337959
R17: 10k; R_0805_2012Metric; LCSC C17414
R18: 1.5k; R_0805_2012Metric; LCSC C4310
R19, R20: 0; R_0805_2012Metric; LCSC C17477
U5: ST25R3916-AQWT; QFN50P500X500X100-33N; PARTREV 4; LCSC C2908147
Y2: 27.12MHz; Crystal_SMD_3225-4Pin_3.2x2.5mm_HandSoldering; MPN X32252712MMB4SI; LCSC C29975

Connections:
+3V3: C18.1, R17.1, U5.1 (VDD_IO); also elsewhere on the board
/MCU/NFC_IRQ: U5.27 (IRQ); also elsewhere on the board
/MCU/NFC_MISO: U5.32 (MISO/SDA); also elsewhere on the board
/MCU/NFC_MOSI: U5.31 (MOSI); also elsewhere on the board
/MCU/NFC_NSS: R17.2, U5.29 (~BSS); also elsewhere on the board
/MCU/NFC_SCK: U5.30 (SCLK/SCL); also elsewhere on the board
/RFID/AN1: L1.1, U5.13 (RFO1)
/RFID/AN2: L2.1, U5.15 (RFO2)
/RFID/DC1: C25.1, C29.1, FB2.1, U5.8 (VDD)
/RFID/DC3: C27.1, C31.1, U5.9 (VDD_RF), U5.14 (VDD_DR)
/RFID/DC4: C28.1, C32.1, U5.11 (VDD_AM)
/RFID/DC5: C33.1, C36.1, U5.7 (VDD_A)
/RFID/DC6: C34.1, C37.1, U5.3 (VDD_D)
/RFID/DC7: C35.1, C38.1, U5.24 (AGDC)
/RFID/DR1: C16.1, C21.1, C23.1, R18.1, R19.1
/RFID/DR2: C17.2, C22.1, C24.1, R18.2, R20.2
BAT+: C26.1, C30.1, FB2.2, U5.10 (VDD_TX); also elsewhere on the board
GND: C12.1, C13.2, C14.1, C15.2, C18.2, C19.2, C20.2, C23.2, C24.2, C25.2, C26.2, C27.2, C28.2, C29.2, C30.2, C31.2, C32.2, C33.2, C34.2, C35.2, C36.2, C37.2, C38.2, U5.6 (GND_D), U5.12 (GND_DR), U5.16 (GND_DR), U5.20 (I2C_EN), U5.21 (VSS), U5.26 (GND_A), U5.33 (EXP), Y2.2 (G), Y2.4 (G); also elsewhere on the board
unnamed: AE1.1, R19.2
unnamed: AE1.2, R20.1
unnamed: C19.1, C21.2, L1.2
unnamed: C20.1, C22.2, L2.2
unnamed: J6.1 (Pin_1_1), U5.2 (CSO)
unnamed: J7.1 (Pin_1_1), U5.25 (CSI)
unnamed: C14.2, C16.2, U5.22 (RFI1)
unnamed: C15.1, C17.1, U5.23 (RFI2)
unnamed: C12.2, U5.5 (XTI), Y2.1
unnamed: C13.1, U5.4 (XTO), Y2.3

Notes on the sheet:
VDD / VDD_TX: straight from the Li-ion cell (BAT+). VDD_IO: +3V3 so the SPI/IRQ levels match the MCU.
NFC READER ST25R3916 (SPI)
ST25R3916 SUPPLY AND REGULATOR DECOUPLING
EMC FILTER, MATCHING NETWORK AND ANTENNA
RFID

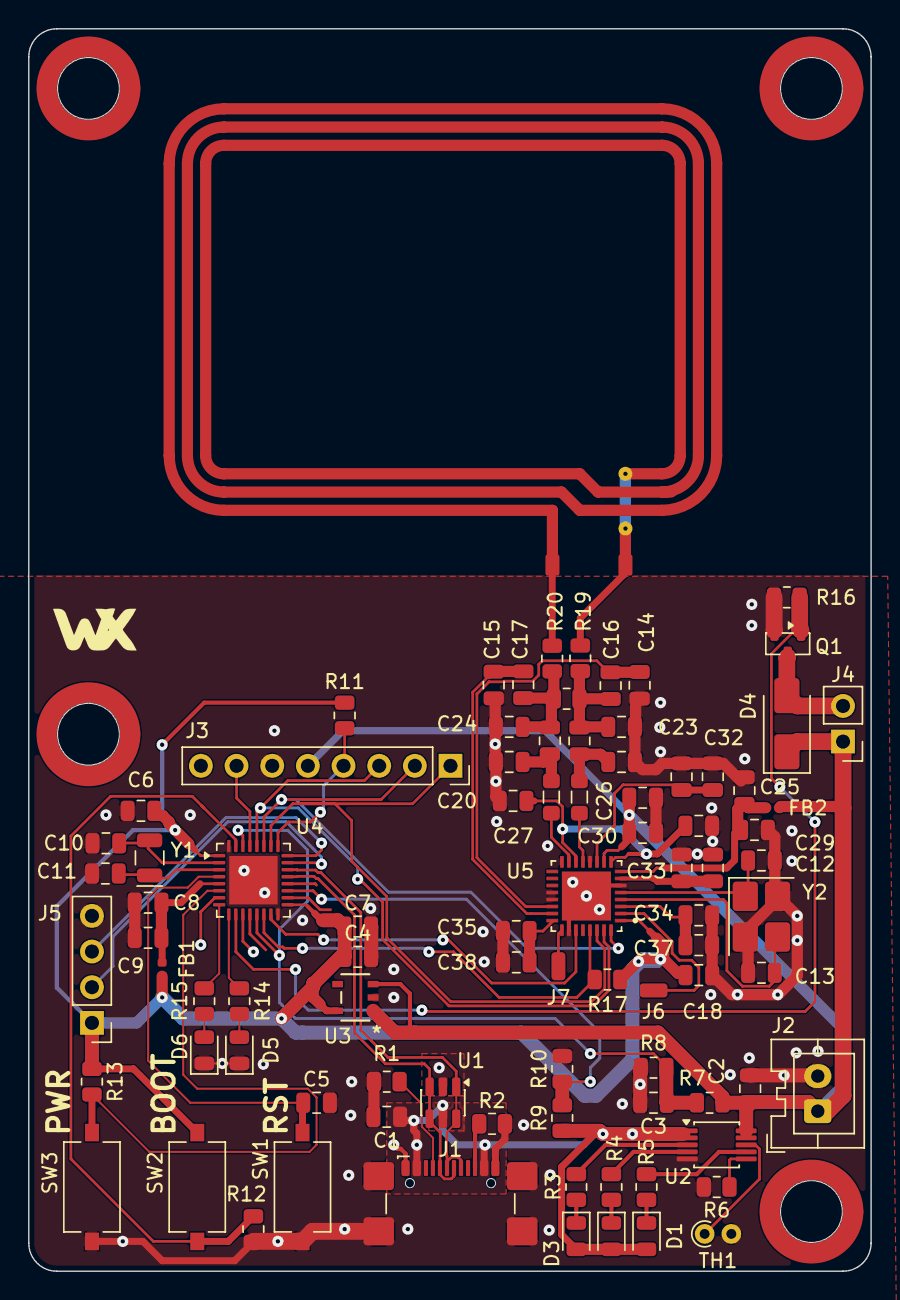
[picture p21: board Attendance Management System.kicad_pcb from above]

Board: 2 copper layers, 60.0 x 88.5 mm, 88 parts (0 on the bottom side), 59 nets.

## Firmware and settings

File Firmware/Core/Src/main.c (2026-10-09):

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
/* Includes ------------------------------------------------------------------*/
#include "main.h"

/* USER CODE BEGIN Includes */
#include "bsp.h"
#include "app_fsm.h"
#include "app_debug.h"
/* USER CODE END Includes */

ADC_HandleTypeDef hadc1;

LPTIM_HandleTypeDef hlptim1;
LPTIM_HandleTypeDef hlptim2;

RTC_HandleTypeDef hrtc;

SPI_HandleTypeDef hspi1;

TIM_HandleTypeDef htim1;
TIM_HandleTypeDef htim2;

PCD_HandleTypeDef hpcd_USB_FS;

/* USER CODE BEGIN PV */

/* Global, volatile state for STM32CubeIDE Live Expressions. Declared in
 * App/Inc/app_debug.h, which documents each one; written by the application
 * (and the reader driver) every pass of the main loop. */

/* Battery */
volatile uint32_t dbg_battery_mv = 0u;
volatile uint8_t  dbg_battery_state = 0u;
volatile uint16_t dbg_battery_counts = 0u;
volatile uint32_t dbg_battery_samples = 0u;
volatile uint8_t  dbg_battery_error = 0u;
volatile uint32_t dbg_battery_raw_mv = 0u;
volatile uint32_t dbg_vdda_mv = 0u;
volatile uint16_t dbg_vrefint_counts = 0u;
volatile uint16_t dbg_vrefint_cal = 0u;
volatile uint8_t  dbg_adc_error = 0u;

/* Last card */
volatile uint32_t dbg_card_id = 0u;
volatile uint8_t  dbg_card_uid[10] = { 0u };
volatile uint8_t  dbg_card_uid_len = 0u;
volatile uint8_t  dbg_card_atqa[2] = { 0u };
volatile uint8_t  dbg_card_sak = 0u;
volatile uint32_t dbg_card_count = 0u;
volatile uint8_t  dbg_scan_result = 0u;

/* Button */
volatile bool     dbg_button_down = false;
volatile uint32_t dbg_button_short_count = 0u;
volatile uint32_t dbg_button_long_count = 0u;

/* Reader */
volatile bool     dbg_nfc_ready = false;
volatile uint8_t  dbg_nfc_chip_id = 0u;
volatile bool     dbg_nfc_supply_3v3 = false;
volatile uint8_t  dbg_nfc_amplitude = 0u;
volatile uint8_t  dbg_nfc_last_status = 0u;
volatile uint32_t dbg_nfc_polls = 0u;
volatile uint32_t dbg_nfc_errors = 0u;
volatile uint32_t dbg_nfc_collisions = 0u;
volatile uint32_t dbg_nfc_last_irq = 0u;
volatile uint32_t dbg_nfc_irq_pin_misses = 0u;
volatile bool     dbg_nfc_armed = false;
volatile uint32_t dbg_nfc_wakeups = 0u;
volatile uint32_t dbg_nfc_false_wakes = 0u;
volatile uint8_t  dbg_nfc_wake_raw = 0u;
volatile uint32_t dbg_nfc_wake_irq = 0u;
volatile int16_t  dbg_nfc_wake_offset = 0;
volatile uint8_t  dbg_nfc_wake_delta = 0u;

/* System */
volatile uint8_t  dbg_state = 0u;
volatile uint8_t  dbg_boot_cause = 0u;
volatile uint32_t dbg_uptime_ms = 0u;
volatile uint32_t dbg_sleep_ms = 0u;
volatile uint8_t  dbg_lptim_fault = 0u;
volatile uint8_t  dbg_pempty_cleared = 0u;
volatile bool     dbg_vbus = false;
volatile bool     dbg_usb_host = false;
volatile uint32_t dbg_records_ram = 0u;
volatile uint32_t dbg_records_flash = 0u;
volatile uint32_t dbg_records_free = 0u;
volatile uint8_t  dbg_battery_percent = 0u;
volatile app_datetime_t dbg_now = { 0u, 0u, 0u, 0u, 0u, 0u };

/* Written from the debugger to set the RTC */
volatile app_datetime_t dbg_set_time = { 0u, 0u, 0u, 0u, 0u, 0u };
volatile bool     dbg_set_time_request = false;

/* USER CODE END PV */

void SystemClock_Config(void);
static void MX_GPIO_Init(void);
static void MX_LPTIM1_Init(void);
static void MX_LPTIM2_Init(void);
static void MX_RTC_Init(void);
static void MX_USB_PCD_Init(void);
static void MX_ADC1_Init(void);
static void MX_SPI1_Init(void);
static void MX_TIM1_Init(void);
static void MX_TIM2_Init(void);
/**
  * @brief  The application entry point.
  * @retval int
  */
int main(void)
{

  /* USER CODE BEGIN 1 */
  /* Before anything can interrupt: own the vector table and clear a stale
   * "flash is empty" flag. See bsp_early_init(). */
  bsp_early_init();
  /* USER CODE END 1 */

  /* MCU Configuration--------------------------------------------------------*/

  /* Reset of all peripherals, Initializes the Flash interface and the Systick. */
  HAL_Init();

  /* Configure the system clock */
  SystemClock_Config();

  /* Initialize all configured peripherals */
  MX_GPIO_Init();
  MX_LPTIM1_Init();
  MX_LPTIM2_Init();
  MX_RTC_Init();
  MX_USB_PCD_Init();
  MX_ADC1_Init();
  MX_SPI1_Init();
  MX_TIM1_Init();
  MX_TIM2_Init();
  /* USER CODE BEGIN 2 */

  /* Level 1: clocks, pins, RTC, ADC, power. Everything is polled from the
   * main loop; only SysTick and USB interrupt. */
  bsp_init();

#if BSP_POWER_TEST
  /* Bench build: steady loads for a multimeter, no application. */
  bsp_power_test();
#endif

  /* Level 2: the flow chart's "Start" through to the first card poll. */
  app_init();

  /* USER CODE END 2 */

  /* Infinite loop */
  /* USER CODE BEGIN WHILE */
  while (1)
  {
    /* USER CODE END WHILE */

    /* USER CODE BEGIN 3 */

    /* One pass: sample the inputs, run the reader, the timers and the
     * feedback pattern, then sleep until the next deadline (Stop 2 when idle
     * on battery). The reader, button, VBUS, USB and LPTIM1 interrupts end
     * the sleep early. */
    app_task();
  }
  /* USER CODE END 3 */
}

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


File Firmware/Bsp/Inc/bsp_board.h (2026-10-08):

/**
 * @file    bsp_board.h
 * @brief   Level 1 (HAL) — the board. Pins, peripheral instances, clocks.
 *
 * Everything device-specific is here, so retargeting to another STM32 or
 * another PCB revision is a change to this file plus the .c files that use it.
 * Nothing in App/ includes this.
 *
 * Target: STM32L432KBU6, UFQFPN32, 128 kB flash / 64 kB SRAM.
 *
 *  Pin   Signal            Function
 *  ----  ----------------  ---------------------------------------------------
 *  PC14  LSE_IN            32.768 kHz crystal. Keeps the RTC, and with it
 *  PC15  LSE_OUT           the CSV timestamps, running while the unit is off.
 *  PA0   PWR_BTN           WKUP1, the only Standby wake source. EXTI0 (both
 *                          edges) wakes the loop; the level is sampled there.
 *  PA1   --                Spare.
 *  PA2   LED_GREEN         Active high.
 *  PA3   LED_RED           Active high.
 *  PA4   VIB_EN            Vibration motor driver enable.
 *  PA5   --                Spare.
 *  PA6   --                Spare.
 *  PA7   BATT_SENSE        ADC1_IN12, 4.7M/2.7M divider off the cell.
 *  PA8   --                Spare.
 *  PA9   USB_VBUS          VBUS detect through R18/R19. EXTI9 (both edges)
 *                          wakes the loop; the level is sampled there.
 *  PA10  --                Spare.
 *  PA11  USB_DM            Fixed function.
 *  PA12  USB_DP            Fixed function.
 *  PA13  SWDIO             Debug. Left configured so the part stays attachable.
 *  PA14  SWCLK             Debug.
 *  PA15  PN532_NSS         Backup reader chip select, active low.
 *  PB0   NFC_NSS           ST25R3916 chip select, active low.
 *  PB1   NFC_IRQ           ST25R3916 interrupt, active high. EXTI1 (rising)
 *                          while the reader is in wake-up mode, otherwise
 *                          polled by bsp_nfc.c with the line masked.
 *  PB3   NFC_SCK           Shared SPI1 clock, AF5.
 *  PB4   NFC_MISO          Shared SPI1 input, AF5, pull-down.
 *  PB5   NFC_MOSI          Shared SPI1 output, AF5.
 *  PB6   PN532_IRQ         Backup reader interrupt, active low. Unused.
 *  PB7   PVD_IN            Same node as PA7; the PVD compares it to VREFINT.
 *  PH3   BOOT0             Strapped low.
 */
#ifndef BSP_BOARD_H
#define BSP_BOARD_H

#include "stm32l4xx_hal.h"

/* The PVD on PVD_IN raises an interrupt, and the firmware currently polls the
 * battery through the ADC instead. Re-enable with the move to interrupts. */
#define BSP_ENABLE_BATTERY_PVD 0u

/* ------------------------------------------------------------------------ */
/* GPIO                                                                     */
/* ------------------------------------------------------------------------ */

#define PIN_PWR_BTN         GPIO_PIN_0
#define PORT_PWR_BTN        GPIOA

#define PIN_LED_GREEN       GPIO_PIN_2
#define PORT_LED_GREEN      GPIOA

#define PIN_LED_RED         GPIO_PIN_3
#define PORT_LED_RED        GPIOA

#define PIN_VIB_EN          GPIO_PIN_4
#define PORT_VIB_EN         GPIOA

#define PIN_BATT_SENSE      GPIO_PIN_7
#define PORT_BATT_SENSE     GPIOA

#define PIN_USB_VBUS        GPIO_PIN_9
#define PORT_USB_VBUS       GPIOA

#define PIN_USB_DM          GPIO_PIN_11
#define PIN_USB_DP          GPIO_PIN_12
#define PORT_USB            GPIOA

#define PIN_PN532_NSS       GPIO_PIN_15
#define PORT_PN532_NSS      GPIOA

#define PIN_NFC_NSS         GPIO_PIN_0
#define PORT_NFC_NSS        GPIOB
#define PIN_NFC_IRQ         GPIO_PIN_1
#define PORT_NFC_IRQ        GPIOB
#define PIN_NFC_SCK         GPIO_PIN_3
#define PIN_NFC_MISO        GPIO_PIN_4
#define PIN_NFC_MOSI        GPIO_PIN_5
#define PORT_NFC_SPI        GPIOB
#define PIN_PN532_IRQ       GPIO_PIN_6
#define PORT_PN532_IRQ      GPIOB

#define PIN_PVD_IN          GPIO_PIN_7
#define PORT_PVD_IN         GPIOB

/** The power button shorts PA0 to ground. */
#define PWR_BTN_ACTIVE_LEVEL     GPIO_PIN_RESET

/** ST25R3916 IRQ is active high. */
#define NFC_IRQ_ACTIVE_LEVEL     GPIO_PIN_SET

/* ------------------------------------------------------------------------ */
/* Clocks                                                                   */
/* ------------------------------------------------------------------------ */

/** MSI range while scanning cards. 4 MHz runs at flash latency 0 and keeps
 *  SPI1 well inside the reader's 10 MHz limit. */
#define BSP_MSI_RANGE_RUN       RCC_MSIRANGE_6      /*  4 MHz */
#define BSP_SYSCLK_RUN_HZ       4000000u

/** MSI range while USB is enumerated. USB FS needs the core fast enough to
 *  turn packets around; 24 MHz has margin and costs only the USB session. */
#define BSP_MSI_RANGE_USB       RCC_MSIRANGE_9      /* 24 MHz */
#define BSP_SYSCLK_USB_HZ       24000000u

#define BSP_LSE_HZ              32768u
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

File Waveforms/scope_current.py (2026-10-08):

#!/usr/bin/env python3
"""Log the logger's battery current with a Tektronix TBS1000C (TBS1052C) over USB.

The scope reads the voltage across a shunt resistor in the battery's negative
lead; this script fetches each triggered acquisition (up to 20 000 points),
converts it to current, and logs the mean current, the charge and the peak.

    pip install pyvisa pyvisa-py pyusb
    python3 scope_current.py --list
    python3 scope_current.py --zero                    # no current flowing: measures the offset
    python3 scope_current.py --shunt 1.0 --captures 20 --offset-mv 0.12 --out taps

Every capture is saved as <out>_NNN.csv (t_s, v, i_a), and one summary row per
capture goes to <out>_summary.csv. The scope's own settings (V/div, time/div,
trigger, acquisition mode) are used as they are, so set them up on the front
panel first; the script only arms single acquisitions and reads them.

Linux: the scope needs USB access, e.g. /etc/udev/rules.d/99-tek.rules with
    SUBSYSTEM=="usb", ATTR{idVendor}=="0699", MODE="0666"
"""
import argparse
import csv
import sys
import time
from datetime import datetime

try:
    import pyvisa
except ImportError:
    sys.exit("needs pyvisa: pip install pyvisa pyvisa-py pyusb")


def open_scope(rm, resource):
    if resource is None:
        tek = [r for r in rm.list_resources() if "0x0699" in r.lower() or "::1689::" in r]
        if not tek:
            sys.exit("no Tektronix scope found; check the rear USB cable and --list")
        resource = tek[0]
    scope = rm.open_resource(resource)
    scope.timeout = 20000
    scope.read_termination = "\n"
    scope.write_termination = "\n"
    print("connected:", scope.query("*IDN?").strip())
    return scope


def preamble(scope):
    """Scale factors for the selected source, whichever command family the firmware answers."""
    for prefix in ("WFMOutpre", "WFMPre"):
        try:
            return {k: float(scope.query(f"{prefix}:{k}?"))
                    for k in ("XINcr", "XZEro", "YMUlt", "YOFf", "YZEro")}
        except pyvisa.errors.VisaIOError:
            scope.write("*CLS")
    sys.exit("the scope answered neither WFMOutpre nor WFMPre")


def acquire(scope, channel, timeout_s):
    scope.write("ACQuire:STOPAfter SEQuence")
    scope.write("ACQuire:STATE RUN")
    t0 = time.time()
    while int(scope.query("ACQuire:STATE?").strip()) != 0:
        if time.time() - t0 > timeout_s:
            return None                       # no trigger
        time.sleep(0.05)
    scope.write(f"DATa:SOUrce {channel}")
    scope.write("DATa:ENCdg ASCii")
    scope.write("DATa:WIDth 1")
    scope.write("DATa:STARt 1")
    scope.write("DATa:STOP 20000")
    p = preamble(scope)
    raw = [float(x) for x in scope.query("CURVe?").strip().split(",")]
    t = [p["XZEro"] + i * p["XINcr"] for i in range(len(raw))]
    v = [(r - p["YOFf"]) * p["YMUlt"] + p["YZEro"] for r in raw]
    return t, v, p["XINcr"]


def main():
    ap = argparse.ArgumentParser(description=__doc__, formatter_class=argparse.RawDescriptionHelpFormatter)
    ap.add_argument("--list", action="store_true", help="list VISA resources and exit")
    ap.add_argument("--resource", help="VISA resource string (default: the first Tektronix device)")
    ap.add_argument("--channel", default="CH1")
    ap.add_argument("--shunt", type=float, default=1.0, help="shunt resistance in ohms")
    ap.add_argument("--offset-mv", type=float, default=0.0, help="scope offset to subtract, from --zero")
    ap.add_argument("--captures", type=int, default=10)
    ap.add_argument("--wait", type=float, default=30.0, help="seconds to wait for each trigger")
    ap.add_argument("--zero", action="store_true", help="measure the offset with no current flowing")
    ap.add_argument("--out", default="capture")
    a = ap.parse_args()

    rm = pyvisa.ResourceManager("@py")
    if a.list:
        print("\n".join(rm.list_resources()) or "nothing found")
        return
    scope = open_scope(rm, a.resource)

    if a.zero:
        scope.write("TRIGger:FORce")
        got = acquire(scope, a.channel, 5.0) or sys.exit("no acquisition")
        mean_mv = 1000 * sum(got[1]) / len(got[1])
        print(f"offset {mean_mv:+.3f} mV: pass --offset-mv {mean_mv:.3f}")
        return

    with open(f"{a.out}_summary.csv", "w", newline="") as fs:
        summary = csv.writer(fs)
        summary.writerow(["n", "time", "window_s", "points", "mean_ma", "charge_uc", "peak_ma", "file"])
        for n in range(1, a.captures + 1):
            got = acquire(scope, a.channel, a.wait)
            if got is None:
                print(f"{n}: no trigger within {a.wait:g} s")
                continue
            t, v, dt = got
            i = [(x - a.offset_mv / 1000) / a.shunt for x in v]
            window = dt * len(i)
            charge_uc = sum(i) * dt * 1e6          # rectangle rule; fine at these sample rates
            mean_ma = 1000 * sum(i) / len(i)
            name = f"{a.out}_{n:03d}.csv"
            with open(name, "w", newline="") as fw:
                w = csv.writer(fw)
                w.writerow(["t_s", "v", "i_a"])
                w.writerows(zip(t, v, i))
            summary.writerow([n, datetime.now().isoformat(timespec="seconds"), f"{window:.6g}", len(i),
                              f"{mean_ma:.4f}", f"{charge_uc:.3f}", f"{1000*max(i):.2f}", name])
            fs.flush()
            print(f"{n}: {window*1000:.3g} ms window, mean {mean_ma:.3f} mA, "
                  f"charge {charge_uc:.2f} uC, peak {1000*max(i):.1f} mA")


if __name__ == "__main__":
    main()

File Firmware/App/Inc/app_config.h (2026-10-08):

/**
 * @file    app_config.h
 * @brief   Level 2 (logic) — compile-time tuning of the attendance application.
 *
 * Every value here is a *policy* decision, not a hardware fact. Hardware facts
 * (pins, peripheral instances, clock trees, reader timings) live in
 * Bsp/Inc/bsp_board.h.
 */
#ifndef APP_CONFIG_H
#define APP_CONFIG_H

/* ------------------------------------------------------------------------ */
/* Timing policy                                                            */
/* ------------------------------------------------------------------------ */

/** Inactivity window after which the unit flushes and goes to Standby. */
#define APP_INACTIVITY_MS               (3u * 60u * 1000u)

/** A card presenting the same ID again inside this window is a duplicate. */
#define APP_DEDUP_WINDOW_S              (10u)

/**
 * A card already recorded in the current lecture is not recorded again, however
 * long ago, so a student who taps twice by accident, or comes back to the
 * reader later, is counted once. A lecture lasts until the next one is started
 * from the USB drive; with none started, or a very long one, this is the most
 * time a record is looked back over. It reads the flash log, so it survives
 * the unit going to Standby between taps.
 */
#define APP_SESSION_MAX_AGE_S           (6u * 3600u)

/** Records examined at most per tap by that check (a few hundred microseconds each 100). */
#define APP_SESSION_SCAN_MAX            (2048u)

/** How many distinct recent cards are remembered for duplicate suppression. */
#define APP_DEDUP_SLOTS                 (8u)

/* ------------------------------------------------------------------------ */
/* Card reader policy                                                       */
/* ------------------------------------------------------------------------ */

/** Interval between reader polls. The field is off between polls. */
#define APP_NFC_POLL_MS                 (100u)

/** Field-on time before REQA, so a card can power up (ISO14443-3: 5 ms). */
#define APP_NFC_FIELD_GUARD_MS          (5u)

/** Consecutive empty polls before a held card counts as taken away. Until
 *  then the same card is not reported again, however many polls see it. It
 *  is also the number of empty polls before wake-up mode is re-armed, after a
 *  tap or a false wake-up, and each costs the RF field (203 mA measured) for
 *  ~6 ms plus 100 ms of Ready mode (5.7 mA): one is enough, since a card still
 *  held and missed once only means one extra wake-up when it leaves. */
#define APP_NFC_REMOVE_MISSES           (1u)

/** 1: between cards the reader sits in its own wake-up mode and interrupts
 *  on PB1 when something changes the antenna; it polls only from a wake-up
 *  until the field is empty again. 0: poll every APP_NFC_POLL_MS for ever. */
#define APP_NFC_USE_WAKEUP              (1u)

/** Wake-up mode measurement interval: the longest a card waits before the
 *  reader notices it. The chip offers 10-80 ms and 100-800 ms. */
#define APP_NFC_WAKE_PERIOD_MS          (100u)

/** Longest the main loop sleeps with nothing due: one heartbeat period, so an
 *  idle unit wakes only for the heartbeat. It also bounds how stale the dbg_*
 *  globals can get. Within BSP_STOP2_MAX_MS, so it is one Stop 2 sleep. */
#define APP_SLEEP_MAX_MS                (5000u)

/** Wake-up mode trigger window: counts either side of the reference that do
 *  not wake the reader. It starts at the minimum and widens by one after each
 *  false wake-up beyond the first in a row (the first one corrects the
 *  reference instead), up to the maximum; it narrows by one again after
 *  APP_NFC_WAKE_RELAX_AFTER wake-ups in a row that found a card. */
#define APP_NFC_WAKE_DELTA_MIN          (2u)
#define APP_NFC_WAKE_DELTA_MAX          (10u)
#define APP_NFC_WAKE_RELAX_AFTER        (20u)

/** Retry interval when the reader failed to initialise. */
#define APP_NFC_RETRY_MS                (5000u)

/** Reader supply mode, with hysteresis. The reader's 3.3 V mode is only
 *  allowed up to 3.6 V; below 3.5 V its 5 V mode loses regulator headroom. */
#define APP_NFC_SUPPLY_3V3_BELOW_MV     (3500u)
#define APP_NFC_SUPPLY_5V_ABOVE_MV      (3600u)


/* ------------------------------------------------------------------------ */
/* Button policy                                                            */
/* ------------------------------------------------------------------------ */

#define APP_BTN_DEBOUNCE_MS             (30u)

/** Hold this long for a new lecture: a buzz marks the moment, and letting go
 *  before APP_BTN_OFF_MS starts it. Shorter presses show the battery status. */
#define APP_BTN_LONG_MS                 (2000u)

/** Hold this long to power off instead; no lecture is started. */
#define APP_BTN_OFF_MS                  (5000u)

/** Two taps whose releases are this close are a double press: with the cable
 *  in and the drive ejected, it brings the drive back. */
#define APP_BTN_DOUBLE_MS               (600u)
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

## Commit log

2026-09-21 PCB project has been created
    [Attendance Management System.kicad_pcb, Attendance Management System.kicad_sch]
2026-09-24 Power schematic is ready
    [Attendance Management System.kicad_sch, mcu.kicad_sch, power.kicad_sch]
2026-09-24 RFID sch added
    [Attendance Management System.kicad_pcb, Attendance Management System.kicad_sch, mcu.kicad_sch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]
2026-09-25 Schematic is almost ready
    [Attendance Management System.kicad_pcb, Attendance Management System.kicad_sch, mcu.kicad_sch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]
2026-09-25 PN532 pins are added
    [mcu.kicad_sch, rfid.kicad_sch]
2026-09-25 ESD diodes added
    [Attendance Management System.kicad_sch, mcu.kicad_sch, power.kicad_sch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]
2026-09-25 Components placed roughly
    [Attendance Management System.kicad_pcb, mcu.kicad_sch, power.kicad_sch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]
2026-09-25 Routing zones completed|
    [Attendance Management System.csv, Attendance Management System.kicad_pcb]
2026-09-25 routing complete
    [Attendance Management System.kicad_pcb, rfid.kicad_sch]
2026-09-25 BOMs updated
    [Attendance Management System-B_Cu.gbr, Attendance Management System-B_Mask.gbr, Attendance Management System-B_Paste.gbr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]
2026-09-25 almost ready for fabrication
    [Attendance Management System.kicad_pcb, Attendance_Management_System_BOM_DigiKey.xlsx, Attendance_Management_System_BOM_LCSC.xlsx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]
2026-09-26 Mounting holes and WX logo added
    [Attendance Management System.kicad_pcb, rfid.kicad_sch]
2026-09-26 Submitted to JLCPCB
    [Attendance Management System.kicad_pcb, designators.csv, positions.csv]
2026-10-06 Enclosure is ready
    [assembly.stl, base.stl, button.stl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]
2026-10-06 Card uid detecton, led and motor are working but the battery voltage detection is not functioning
2026-10-07 Battery percentage is added in GUI, simplified the GUI
2026-10-07 FIxed the 10s card timeout for new lecture bug fixed
    [app_config.h, bsp_board.h]
2026-10-07 Fit firmware to the 128 kB STM32L432KB and add power report
    The fitted MCU is the STM32L432KB (flash-size word at 0x1FFF75E0 reads
    128), but the firmware kept its config and log at 0x08020000, outside
    the part's specified flash. Code and data now share the 128 kB: 72 kB
    of code (pages 0-35) and 56 kB of data from 0x08012000 (config page plus
    27 log pages, 6 858 records, down from 13 970).
    - Linker script and startup file renamed to the KB names; FLASH 72K,
    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
    [Attendance Management System.csv, Attendance_Management_System_BOM_DigiKey.xlsx, Attendance_Management_System_BOM_LCSC.xlsx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]
2026-10-08 Power calculations doc updated
2026-10-08 Lengthen Stop 2 sleeps and add a power-test bench build
    LPTIM1 now counts LSE/8 (4096 Hz, 16 s wrap), so one Stop 2 sleep can
    last up to 15 s. The idle loop sleeps up to 5 s and wakes only for the
    10 ms heartbeat flash, with the battery sample aligned to it. One empty
    poll re-arms the reader's wake-up mode, and the accept buzz is 60 ms.
    `make power-test` builds bsp_power_test.c, which holds one load at a
    time steady for a meter. The power report and cost model are updated.
    [app_config.h, bsp_board.h, bsp_power.c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]
2026-10-08 Add scope waveform captures and plotting tools
    plot_waveforms.py browses the TBS1052C CSVs in Waveforms/ with a
    drop-down (CH1 yellow, CH2 blue, optional shunt current); --save writes
    PNGs. scope_current.py moves here from Firmware/Tests.
    [TEK00000.CSV, TEK00001.CSV, TEK00002.CSV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]
2026-10-08 Use the scope captures in the power report
    Firmware/docs/waveforms.py integrates the TBS1052C captures in Waveforms/
    (1 ohm shunt, offset removed) and power_report.py builds its idle and event
    figures from them instead of current x firmware time:
    - One wake-up measurement is 9.9 uC (oscillator start ~13 mA for 0.4 ms,
    then ~41 us of field at up to 94 mA), so wake-up mode averages 99 uA,
    not the multimeter's 185 uA (kept as the pessimistic case).
    - A read keeps the field on 12.2 ms at 202 mA; an empty poll 5.7 ms at
    228 mA; the buzz measures 50 ms at 91 mA (motor ~82 mA starting up).
    - A false wake-up is 1.33 mC from IRQ to re-arm, as modelled.
    Idle scanning falls from 194 to 108 uA,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
    [power_report.py, waveforms.py]
2026-10-08 Add clock tree and wake-up timings to the power report
    - Clock tree in STM32CubeMX's own style (palette from STGraphicChart and
    fonts from STFonts in STM32CubeMX.jar, wire and multiplexer colours from
    its STM32L43.png), with the values the firmware programs at run time and
    the ST25R3916's own clocks. Exported as Firmware/docs/clock_tree.svg
    (written by power_report.py) and clock_tree.png (3x render).
    - Clock justification table gains the reader's 32 kHz wake-up timer,
    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
2026-10-09 Stop tracking KiCad backups, per-user state and __pycache__
    [Attendance Management System.kicad_pcb, Attendance Management System.kicad_sch, mcu.kicad_sch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]
2026-10-13 Build the Companion app as Linux and Windows installers
    PyInstaller bundles the app with Python and Qt. build_linux.sh packs it
    as a .deb and a .tar.gz, build_windows.bat as an Inno Setup installer,
    and build_windows_docker.sh builds the same installer from Linux under
    Wine. A GitHub Actions workflow builds both on every Companion change
    and attaches them to a release when a companion-v* tag is pushed.
2026-10-14 Move the through-hole parts to the back of the board
    J2, J5, TH1 and the J3/J4 footprints go on B.Cu so the front stays flat for the slim enclosure.
2026-10-14 Slim two-part enclosure for the board with its tall parts on the back
    enclosure.py builds the lid, lid inlay and base (printable and mouldable), the battery and motor, and the full assembly, and checks the fit against the .kicad_pcb. export_pcb.py writes the populated 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
2026-10-14 Add the Windows installer, AttendanceLogger-Setup-1.0.0.exe
    Built with packaging/build_windows_docker.sh from the current Companion code.

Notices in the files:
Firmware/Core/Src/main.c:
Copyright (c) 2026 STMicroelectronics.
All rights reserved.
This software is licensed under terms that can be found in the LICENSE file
